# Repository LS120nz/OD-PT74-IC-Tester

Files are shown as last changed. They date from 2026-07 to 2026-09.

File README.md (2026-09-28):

# OD-PT74

Pico 74xx Logic IC Tester

OD-PT74 is the first bench instrument in the Otter Designs Test Equipment family.








## PCB Manufacturing

Production-ready PCBs are available from the PCBWay Shared Project.

➡️ https://www.pcbway.com/project/shareproject/OD_PT74_Logic_IC_Tester_728014b9.html

An open-source bench instrument for testing classic 74xx-series logic ICs.

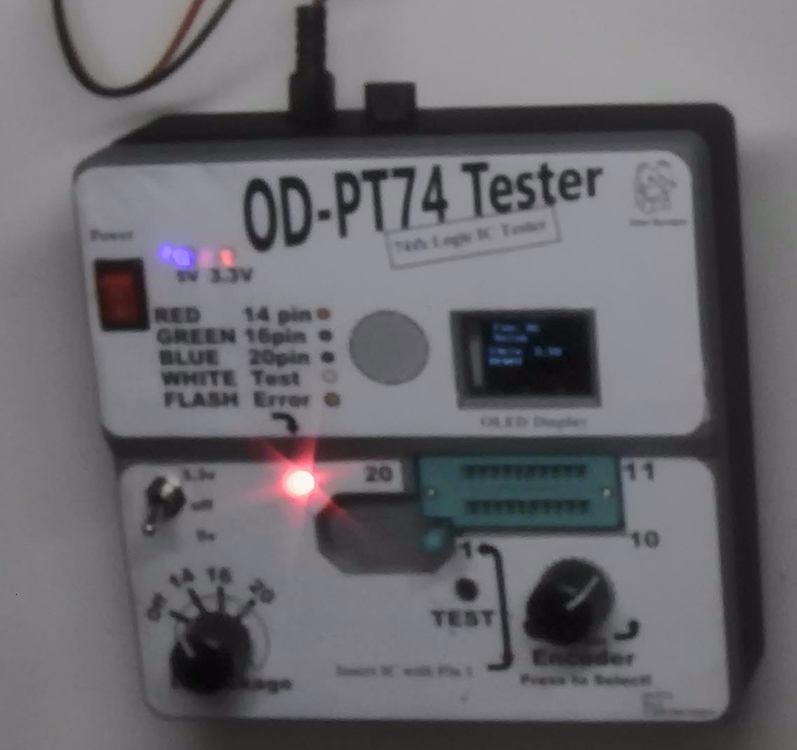
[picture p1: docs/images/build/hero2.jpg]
OD-PT74 Tester


*OD-PT74 Pico 74xx IC Tester installed in the production enclosure.*



---

## Overview

The OD-PT74 Pico 74xx IC Tester is a Raspberry Pi Pico 2 (RP2040) based instrument designed to test common 74xx logic ICs used in retro-computing, electronics repair, education, and hobby projects.

The Rev-C platform combines dedicated hardware, a graphical OLED user interface, and modular MicroPython firmware to provide fast, repeatable testing of common logic devices in a compact desktop instrument.

Current support focuses on standard 14-pin, 16-pin, and 20-pin DIP devices from the 74LS, 74HC, 74HCT and selected compatible logic families.

## 🚀 Quick Start

1. Download or clone this repository.
2. Install **Thonny** from https://thonny.org
3. Install **MicroPython** onto your Raspberry Pi Pico.
4. Copy the following files to the Pico:
   - `main.py`
   - `ssd1306.py`
5. Power up the tester.
6. Verify the POST completes successfully.
7. Start testing ICs!

For detailed installation instructions, see the **Documentation Index** or jump directly to one of the guides below.

---

## Documentation

| Section | Description |
|---|---|
| [📖 Documentation Index](docs/README.md) | Browse all project documentation |
| [🚀 Getting Started](docs/guides/getting-started.md) | First-time setup |
| [🔧 Build Guide](docs/guides/build-guide.md) | Hardware assembly |
| [🔧 Front Panel Wiring Guide](docs/guides/Switch-Wiring-guide.md)
| [💾 Firmware Guide](docs/guides/firmware-guide.md) | Install and update the firmware |
| [▶️ Usage Guide](docs/guides/usage-guide.md) | Operating the tester |
| [🧩 Supported ICs](docs/guides/supported-ics.md) | Supported logic device library |
| [🛠 Troubleshooting Guide](docs/guides/troubleshooting-guide.md) | Diagnose common issues |

---

## Key Features

* Raspberry Pi Pico 2 (RP2040) based design
* Supports standard 14-, 16- and 20-pin DIP packages
* Compatible with common 74LS, 74HC and 74HCT logic families
* Automatic package detection
* Quick, Full and Soak test modes
* Power-On Self Test (POST)
* 128×64 OLED graphical interface
* Rotary encoder driven menu system
* USB serial diagnostics
* Open-source hardware and firmware

---

## Gallery

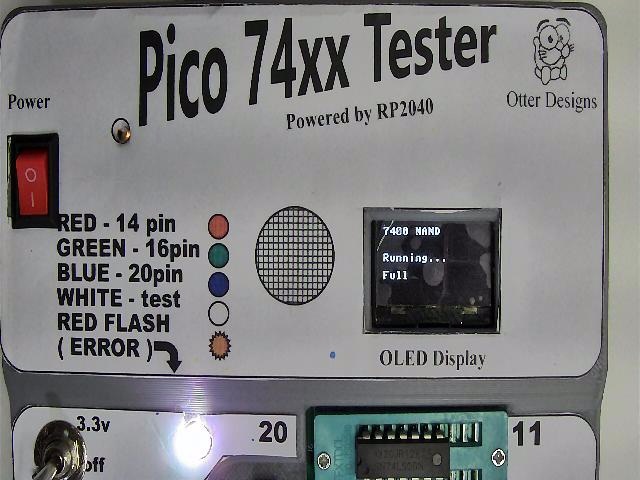
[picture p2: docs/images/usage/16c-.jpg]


*Figure 1. Full functional test in progress.*

* 
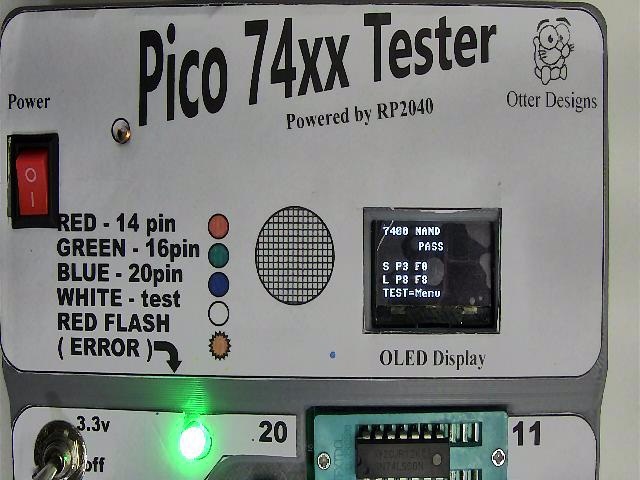
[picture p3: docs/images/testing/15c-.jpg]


*Figure 2. OLED displaying a successful PASS result.*

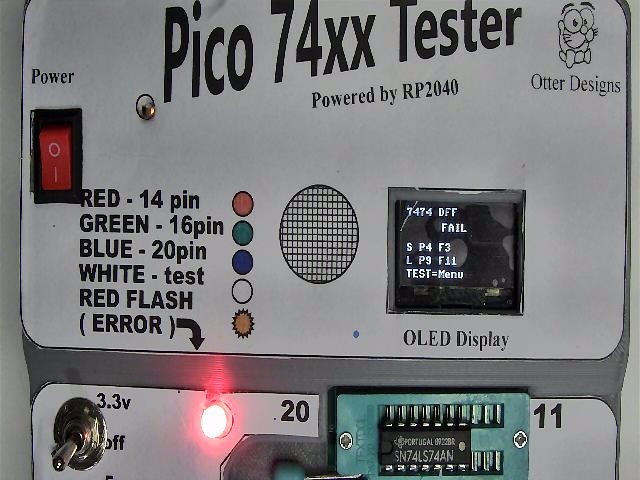
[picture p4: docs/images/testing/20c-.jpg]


*Figure 3. OLED displaying a FAIL result.*

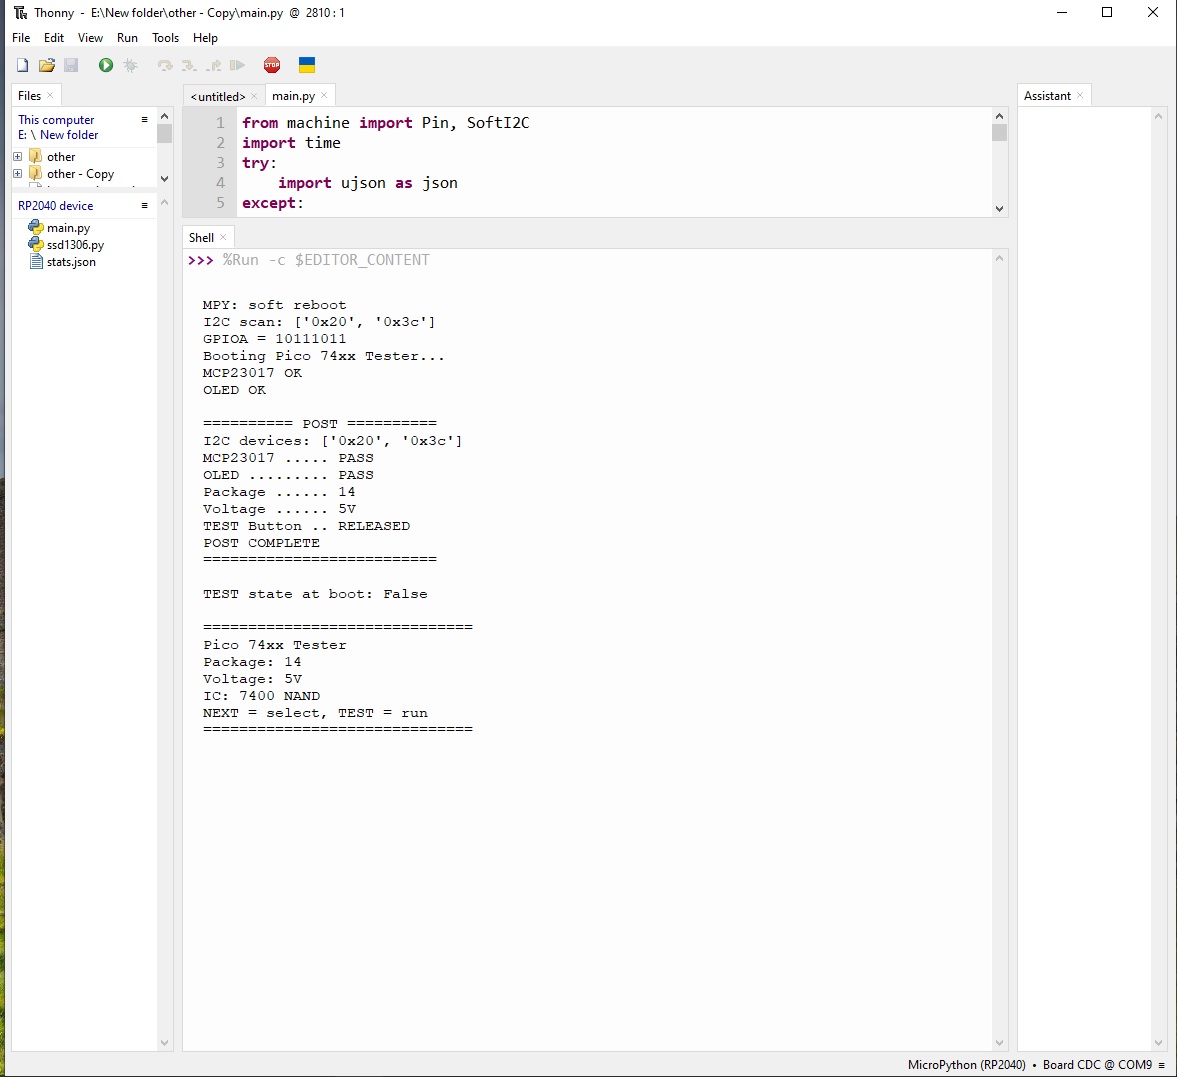
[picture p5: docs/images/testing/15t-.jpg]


*Figure 4. USB serial diagnostic output in Thonny.*

## Hardware Summary

| Feature | Specification |
| --- | --- |
| MCU | Raspberry Pi Pico 2 (RP2040) |
| Display | 128 × 64 SSD1306 OLED |
| DUT Packages | 14, 16 and 20-pin DIP |
| DUT Supply | 3.3 V / OFF / 5 V |
| Interface | Rotary encoder + push buttons |
| Firmware | MicroPython |
| License | MIT (firmware), CERN-OHL-S v2 (hardware) |

---

## Current Release

Hardware PCB Revision: Rev-C
Firmware Version: v1.0.0

This is the first public release of the OD-PT74.

Earlier PCB revisions (Rev-A and Rev-B) were internal development prototypes and were never publicly released.

The project is now focused on:

* expanding the verified IC library
* firmware maintenance and refinement
* documentation improvements
* community contributions

Advanced diagnostic capabilities are planned for the separate Logic IC Diagnostic Analyzer project.

---

## Hardware

Designed for through-hole construction using readily available components with a few SMDs.

Rev-C introduces a production-quality hardware platform featuring:

* Raspberry Pi Pico 2 controller
* 20-pin ZIF socket
* 3.3 V / OFF / 5 V DUT power selection
* Package selection for 14-, 16- and 20-pin devices
* MCP23017 I/O expansion
* SSD1306 OLED display
* Rotary encoder navigation
* TEST and NEXT push buttons
* RGB status LED
* Audible buzzer
* Shared I²C bus architecture
* 5 V power indicator LED
* 3.3 V power indicator LED

GPIO protection is provided through series resistors and clamp diodes to improve robustness during normal operation.

---

## Firmware

The firmware uses a modular architecture that separates hardware drivers, IC definitions, and user interface logic for ease of maintenance and future expansion.

Implemented functionality includes:

* Power-On Self Test (POST)
* OLED diagnostics
* I²C bus diagnostics
* MCP23017 detection
* Package detection
* DUT voltage detection
* Menu-driven user interface
* Serial diagnostic output
* Quick Test mode
* Full Functional Test mode
* Soak testing (50, 500 and Continuous)

---

## Test Modes

| Mode | Description |
| --- | --- |
| Quick | Fast functional verification |
| Full | Complete functional testing |
| Soak 50 | 50 consecutive test cycles |
| Soak 500 | 500 consecutive test cycles |
| Continuous | Unlimited endurance testing |
| POST | Automatic hardware self-test during power-up |

During startup the tester automatically verifies:

* OLED communication
* MCP23017 communication
* I²C bus operation
* Package selection
* DUT voltage selection
* TEST button operation

Diagnostic information is displayed on both the OLED and the USB serial console.

---

## Getting Started

1. Assemble the hardware.
2. Install MicroPython on the Raspberry Pi Pico 2.
3. Copy the firmware to the Pico.
4. Power on the tester.
5. Allow the Power-On Self Test to complete.
6. Select the package size.
7. Insert the IC into the ZIF socket.
8. Press **TEST**.

---

## Project Evolution

| Revision | Description |
| --- | --- |
| Rev-C | First public production release of the OD-PT74 |

Earlier prototype revisions were used during development and are documented in the project history.

---

## Repository Layout

```text
hardware/
firmware/
graphics/
images/
templates/

docs/
├── README.md
├── guides/
├── reference/
├── development/
├── archive/
└── images/

README.md
CHANGELOG.md
CONTRIBUTING.md
LICENSE
```

---

## Contributing

Contributions are welcome, particularly:

* verified IC definitions
* bug reports
* documentation improvements
* hardware testing
* firmware enhancements

When submitting a new IC definition, please include:

* source code
* pin mapping
* tested device family
* hardware validation results
* Quick, Full and Soak test results where applicable

---

## License

Hardware is licensed under the **CERN-OHL-S v2**.

Firmware and documentation are licensed under the **MIT License**.

See the LICENSE file for details.

---

## Acknowledgements

Developed by **Otter Designs**, New Zealand.

If you build an OD-PT74, we'd love to see it! Share your photos, improvements, verified IC definitions, or project ideas by opening an issue or discussion on GitHub.

---

## Project Reference

| Document | Description |
|---|---|
| [📐 Project Overview](docs/reference/project-overview.md) | Project goals and architecture |
| [📘 Hardware Design Guide](docs/reference/hardware-design-guide.md) | Hardware architecture and design |
| [📝 Documentation Style Guide](docs/reference/documentation-style-guide.md) | Documentation standards |

## Development

| Document | Description |
|---|---|
| [📅 Milestones](docs/development/Milestones.md) | Project progress and milestones |

## Project Preservation

Where practical, the OD-PT74 repository includes the original source files used to create the project.

Examples include:

- KiCad PCB source
- FreeCAD enclosure source
- SVG diagrams
- Firmware source code
- Documentation source

This approach helps ensure the project remains buildable, maintainable and adaptable for many years to come.

| [✅ Bring-up Checklist](docs/development/bringup-checklist.md) | Hardware verification checklist |

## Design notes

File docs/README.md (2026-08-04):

# Documentation

*Welcome to the OD-PT74 Pico 74xx IC Tester documentation.*

New to the project? Start with the Getting Started Guide, then continue with the Build Guide and Firmware Guide.

## User Guides

1. **[Getting Started](guides/getting-started.md)** – First-time setup and initial power-on.
2. **[Build Guide](guides/build-guide.md)** – Complete hardware assembly instructions.
3. **[Front Panel Wiring Guide](guides/Switch-Wiring-guide.md)** - Wire up Switches.
4. **[Firmware Guide](guides/firmware-guide.md)** – Installing MicroPython and the OD-PT74 firmware.
5. **[Usage Guide](guides/usage-guide.md)** – Operating the tester and interpreting results.
6. **[Supported ICs](guides/supported-ics.md)** – Validated devices and support status.
7. **[Troubleshooting Guide](guides/troubleshooting-guide.md)** – Diagnosing common problems.

## Reference

- **[Project Overview](reference/project-overview.md)** – High-level overview of the OD-PT74 project.
- **[Hardware Design Guide](reference/hardware-design-guide.md)** – Hardware architecture and design philosophy.
- **[Documentation Style Guide](reference/documentation-style-guide.md)** – Documentation standards used throughout the repository.

## Development

- **[Project Milestones](development/milestones.md)** – Major project achievements and release history.
- **[Bring-up Checklist](development/bringup-checklist.md)** – Hardware validation checklist for assembled boards.

## Archive

Historical documentation for Rev-A and early Rev-B development.

---

## Documentation Navigation

| Document | Description |
|---|---|
| [🏠 Project Home](../README.md) | Return to the project homepage |

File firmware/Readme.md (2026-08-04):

\# Firmware

This directory contains the firmware for the \*\*OD-PT74 Pico 74xx Logic IC Tester\*\*.

\## Current Release

\- Hardware: Rev-C

\- Firmware: v1.0.0

\## Files

| File | Description |

|------|-------------|

| `main.py` | Main application firmware |

| `ssd1306.py` | SSD1306 OLED display driver |

| `stats.json` | Automatically created after testing ICs (do not copy manually) |

\## Installation

1\. Install the supported version of MicroPython onto the Raspberry Pi Pico.

2\. Copy `main.py` and `ssd1306.py` to the Pico.

3\. Reset the Pico.

4\. The OD-PT74 will boot automatically.

For detailed installation instructions, see the \*\*Firmware Guide\*\*.

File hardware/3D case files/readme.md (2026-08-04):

# OD-PT74 3D Printed Case

This directory contains the 3D printable enclosure for the **OD-PT74 Rev-C**.

## Design

- Designed using **FreeCAD**
- Tested on a **Creality K1**
- Optimised for **PLA+**

## Included Files

| File Type | Description |
|---|---|
| **FCStd** | Original FreeCAD source files |
| **3MF** | Print projects with print settings |
| **STL** | Standard files ready for slicing and printing |

## Project Preservation

The original FreeCAD source files are included so the enclosure can be modified, repaired or adapted for future revisions of the OD-PT74.

This follows the project's preservation philosophy of including original design files wherever practical.

## CAD Software

The enclosure was designed using **FreeCAD 0.21**.

The supplied `.FCStd` files can be opened with newer versions of FreeCAD, although the user interface and available tools may differ.

## Source Files

The FreeCAD (`.FCStd`) files are provided so the enclosure can be modified or adapted for future revisions.

The STL files are ready for 3D printing.

The 3MF files are provided for users who wish to use the recommended print settings.

> [!NOTE]
> The 3MF files contain the slicer settings used to print the enclosure shown throughout this documentation. Users of other printers or slicers can use the STL files together with their own preferred print settings.

### Recommended Print Settings

The supplied 3MF files have been prepared for:

- **Printer:** Creality K1
- **Nozzle:** 0.4 mm
- **Material:** PLA filament

These settings are provided as a starting point and may be adjusted to suit your own printer and preferred material.

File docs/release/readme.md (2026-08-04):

# Release Assets

This folder contains the assets used to publish the OD-PT74 Logic IC Tester.

Contents include:

- GitHub release notes
- PCBWay Shared Project description
- Release images
- QR code artwork

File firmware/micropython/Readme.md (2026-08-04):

# Firmware

This directory contains the firmware for the **OD-PT74 Pico 74xx Logic IC Tester**.

## Supported Hardware

- Hardware Revision: Rev-C
- Firmware Version: v1.0.0

## Files

| File | Description |
|---|---|
| `main.py` | Main OD-PT74 application firmware |
| `ssd1306.py` | SSD1306 OLED display driver |

## Installation

1. Install MicroPython on the Raspberry Pi Pico.
2. Copy `main.py` to the Pico.
3. Copy `ssd1306.py` to the Pico.
4. Reboot the Pico.

The firmware will start automatically.

## Notes

This firmware is intended for the Rev-C OD-PT74 hardware.

*Copyright © 2026 Otter Designs*

OD-PT74 Firmware v1.0.0

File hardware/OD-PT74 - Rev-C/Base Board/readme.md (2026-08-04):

# OD-PT74 Rev-C Base Board

This directory contains all design, manufacturing and reference files for the **OD-PT74 Rev-C Base Board**.

## Contents

### BOM

Contains the Bill of Materials in both human-readable Markdown and KiCad-generated CSV formats.

### KiCad

Contains the complete KiCad source project, including the schematic, PCB layout and associated project files.

### Gerbers

Contains the Gerber and drill files generated from the final Rev-C design.

### Images

Contains reference images, including the schematic, PCB layout and 3D board render.

### OD-PT74_Base.zip
A ready-to-upload archive containing all manufacturing files required for PCB fabrication.

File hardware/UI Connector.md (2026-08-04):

\# OD-PT74 UI Connector

This document defines the board-to-board connector assignments between the OD-PT74 Rev-C Main Board and Top Board.

These connector assignments are provided for hardware maintenance, future revisions and third-party expansion boards.

\## Compatible Hardware

• OD-PT74 Rev-C Main Board

• OD-PT74 Rev-C Top Board

\## J7 — ZIF Interface Bus (Pins 1–16)

Pin 1 - ZIF-1
Pin 2 - ZIF-2
Pin 3 - ZIF-3
Pin 4 - ZIF-4
Pin 5 - ZIF-5
Pin 6 - ZIF-6
Pin 7 - ZIF-7
Pin 8 - ZIF-8
Pin 9 - ZIF-9
Pin 10 - ZIF-10
Pin 11 - ZIF-11
Pin 12 - ZIF-12
Pin 13 - ZIF-13
Pin 14 - ZIF-14
Pin 15 - ZIF-15
Pin 16 - ZIF-16

\## J8 — ZIF \& User Interface Bus

Pin 1 - ZIF-17
Pin 2 - ZIF-18
Pin 3 - ZIF-19
Pin 4 - ZIF-20
Pin 5 - I2C SDA
Pin 6 - I2C SCL
Pin 7 - RGB Red
Pin 8 - RGB Green
Pin 9 - RGB Blue
Pin 10 - Test / Enter Button
Pin 11 - Active Piezo Buzzer
Pin 12 - Encoder-A
Pin 13 - Encoder-B
Pin 14 - Encoder-SW
Pin 15 - GPIO28 (Reserved / Future Use)
Pin 16 - Next / Select Button

\## J6 — Power Distribution Bus

Pin 1 - DC +3.3v
Pin 2 - DC +3.3v
Pin 3 - DC +5v
Pin 4 - DC +5v
Pin 5 - Gnd
Pin 6 - Gnd
Pin 7 - Pico +3.3v
Pin 8 - Pico +3.3v
Pin 9 - Pico +5v
Pin 10 - Pico +5v
Pin 11 - Gnd
Pin 12 - Gnd
Pin 13 - 3.3 V Output
Pin 14 - 3.3 V Output
Pin 15 - 5 V Output
Pin 16 - 5 V Output
Pin 17 - Gnd
Pin 18 - Gnd
Pin19 - N/C
Pin20 - N/C

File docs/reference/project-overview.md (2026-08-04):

# OD-PT74 Project Overview

## Introduction

The OD-PT74 Pico 74xx Logic IC Tester is an open-source bench instrument designed to verify the functionality of standard 74xx-series digital logic integrated circuits.

Built around the Raspberry Pi Pico (RP2040), the tester provides a dedicated hardware platform with modular MicroPython firmware, allowing common logic devices to be tested quickly and consistently without requiring external test equipment.

The project is intended for electronics enthusiasts, retro-computing hobbyists, educators, repair technicians, and anyone working with TTL or CMOS logic devices.

---

| Item | Value |
| --- | --- |
| Product | OD-PT74 |
| Hardware | Rev-C |
| Firmware | v1.0.0 |
| MCU | RP2040 |
| Language | MicroPython |
| Supported Packages | 14, 16 & 20-pin DIP |

---

## Project Goals

The primary objectives of the project are:

* Provide a simple, reliable tester for common 74xx logic ICs.
* Support the most widely used DIP package formats.
* Deliver consistent and repeatable functional testing.
* Present an intuitive user interface suitable for bench use.
* Maintain an open, modular architecture that is easy to extend.
* Encourage community contributions for additional IC definitions.

---

## Design Scope

The OD-PT74 Rev-C hardware is designed specifically for testing standard logic devices using conventional pin assignments.

Supported device families include:

* 74LS
* 74HC
* 74HCT
* Selected compatible 74xx logic families

Supported package sizes are:

* 14-pin DIP
* 16-pin DIP
* 20-pin DIP

The Rev-C hardware assumes conventional power pin locations used by the majority of standard 74xx devices.

Devices requiring non-standard power arrangements, external adapters, analogue measurements, or specialised timing analysis are intentionally outside the scope of this revision.

---

## Hardware Overview

The tester consists of a dedicated hardware platform featuring:

* Raspberry Pi Pico (RP2040)
* 20-pin ZIF socket
* OLED graphical display
* MCP23017 I/O expander
* Rotary encoder navigation
* TEST and NEXT push buttons
* DUT voltage selection (3.3 V / OFF / 5 V)
* RGB status LED
* Audible buzzer
* Dual 5 V / 3.3 V power indicators

The hardware has been designed for robustness, ease of assembly, and reliable bench operation.

---

## Firmware Overview

The firmware is written in MicroPython using a modular architecture.

Major software components include:

* Hardware abstraction layer
* Display driver
* Menu system
* IC definition library
* Test engine
* Self-test routines
* Diagnostic utilities

Separating IC definitions from the test engine allows new devices to be added without modifying the core firmware.

---

## Testing Philosophy

The objective of the tester is to verify the logical behaviour of supported integrated circuits rather than perform exhaustive electrical characterisation.

Available test modes include:

* Quick Test
* Full Functional Test
* Soak Test (50, 500, or Continuous cycles)

Each device is exercised using predefined test vectors appropriate to its logical function.

---

## Current Status

The OD-PT74 hardware is now based on the Rev-C production PCB and is considered feature complete.

Current development is focused on:

• Expanding the verified IC library
• Firmware enhancements
• Documentation improvements
• Community contributions

---

## Future Development

Future advanced diagnostic capabilities are being developed as part of the separate Otter Designs Advanced Diagnostics Unit (OD-ADU) project.

Planned capabilities include:

* Support for larger package formats
* Adapter-based device testing
* Non-standard power pin configurations
* Advanced timing analysis
* Oscilloscope-style diagnostic tools
* Enhanced device characterisation

These features are intentionally outside the design scope of Rev-C to keep the platform simple, reliable, and focused on testing the most commonly encountered 74xx logic devices.

---

## Repository Documentation

Additional information is available throughout the repository:

* README – project introduction and quick start
* Getting Started – assembly and first use
* Build Guide – hardware construction
* Usage Guide – operating instructions
* Supported ICs – verified device list
* Troubleshooting – common problems and solutions
* CHANGELOG – project revision history

Refer to these documents for detailed instructions and technical reference material.

---

## Related Documentation

| Document | Description |
|---|---|
| [🏠 Project Home](../../README.md) | Return to the main project page |
| [📖 Documentation Index](../README.md) | Documentation overview |
| [🔧 Build Guide](../guides/build-guide.md) | Hardware assembly |

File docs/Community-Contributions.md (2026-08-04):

## Community IC Contributions

The OD-PT74 74xx Tester was designed to allow additional IC support to be added over time.

If you develop and validate support for a new device, contributions are welcome.

### Please Include

* IC part number
* Device family (74LS, 74HC, 74HCT, etc.)
* Test function source code
* Pin mapping used
* Test methodology
* Hardware validation results
* Quick / Full / Soak test results
* Any known limitations

### Validation Requirements

Before submitting a new IC definition, please verify the device on physical hardware.

At minimum:

* Quick Test PASS
* Full Test PASS
* Soak Test PASS (recommended 50 cycles)

### Goal

The aim of the project is to build a growing library of verified logic IC tests that can be shared with the community.

Verified contributions may be incorporated into future firmware releases and credited to the contributor.

### Notes

OD-PT74 74xx Tester focuses primarily on standard 74xx-series logic devices.

More specialised devices and advanced diagnostic functions are planned for the future Logic IC Diagnostic Analyzer.

## Project Preservation

The OD-PT74 repository is intended to preserve everything required to build, modify, and maintain the project. Where practical, original source files are included alongside generated outputs to ensure the project remains usable for future builders and contributors.

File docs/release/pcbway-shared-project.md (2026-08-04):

OD-PT74 PCBWay Shared Project
Project Title

OD-PT74 Logic IC Tester

Short Description
-------------------
The OD-PT74 is an open-source RP2040-based 74xx TTL and CMOS logic IC tester designed for hobbyists, repair technicians and electronics enthusiasts. It supports 14, 16 and 20-pin DIP devices and features an intuitive OLED display with rotary encoder navigation. Complete firmware, hardware source, enclosure files and build documentation are available on GitHub.

Features
----------
Supports 14, 16 and 20-pin DIP logic ICs
Supports both TTL and CMOS logic families
RP2040 microcontroller
OLED display
Rotary encoder user interface
Quick, Full and Soak test modes
Open-source firmware
KiCad hardware source included
FreeCAD enclosure source included
Complete build documentation

GitHub Repository
----------------
GitHub Repository Contents:

Firmware source
Hardware source (KiCad)
Gerber files
BOM files
Pick & Place files
FreeCAD enclosure source
STL files
3MF files
Build Guide
Front Panel Wiring Guide
Hardware Design Guide
Troubleshooting Guide

PCBWay Files
--------------
This Shared Project provides the production-ready manufacturing files for both PCBs used by the OD-PT74:

• Base Board
• Top Board

Each board includes:
• Gerber files
• Bill of Materials (BOM)
• Pick & Place files

GitHub
--------
The complete project, including firmware, documentation, hardware source, enclosure source and future updates, is available on GitHub:

https://github.com/LS120nz/OD-PT74-IC-Tester
Please visit the GitHub repository for firmware updates, documentation and future hardware revisions.

Notes
--------
This project is fully open source.

Complete documentation, firmware updates and future revisions will always be available from the GitHub repository.

Photos to Upload
-----------------
Hero image
Assembled tester
Internal assembly
Top PCB
Base PCB

This project is released as open-source hardware. Contributions, improvements and additional device support are welcome through the GitHub repository.

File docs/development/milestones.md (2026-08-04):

# Project Milestones

## Current Release

Hardware: Rev-C
Firmware: v1.0.0
Status: Public Release

The OD-PT74 has progressed through three hardware revisions, culminating in the Rev-C production design.

### Verified Hardware

* RP2040 Pico controller
* MCP23017 I/O expander
* 20-pin ZIF socket interface
* 14-pin package support
* 16-pin package support
* 20-pin package support
* 3.3V / OFF / 5V DUT voltage selection
* Rotary encoder interface
* TEST and NEXT pushbuttons
* SSD1306 128×64 OLED display
* I²C bus shared between MCP23017 and OLED
* Fault detection and reporting
* Dual 5 V / 3.3 V power indicators

### Verified ICs

Refer to the *Supported ICs* Guide for the current list of validated devices.

### Validation Highlights

The tester has successfully identified defective ICs during validation testing, including:

* Faulty 74HC393 device detected and confirmed
* Incorrect 74163 test implementation identified during firmware validation
* Multiple pin-mapping and package-mapping issues corrected during bring-up

### Project Timeline

✅ Rev-A
Initial concept and functional prototype.

✅ Rev-B
Major redesign and feature validation.

✅ Rev-C
Production hardware.
Public GitHub release.
Documentation complete.
Firmware v1.0.0.

### Future Development

- Additional IC definitions
- Firmware enhancements
- Community contributions
- OD-ADU development

## Related Documentation

| Document | Description |
|---|---|
| [🏠 Project Home](../../README.md) | Return to the main project page |
| [📖 Documentation Index](../README.md) | Documentation overview |

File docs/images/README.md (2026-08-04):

# Images

This directory contains all images used throughout the GitHub documentation for the **OD-PT74 Pico 74xx IC Tester**.

Images are organised by document or purpose to simplify maintenance and keep the documentation consistent.

## Folder Structure

- **build/** – Hardware assembly photographs.
- **firmware/** – Thonny and firmware installation screenshots.
- **hardware/** – Product photographs and hardware overview images.
- **usage/** – Operating the tester and example test results.
- **testing/** – Test examples and validation images.
- **branding/** – Logos, labels, and other branding artwork.

When adding new images:

- Use descriptive filenames.
- Keep images grouped in the appropriate folder.
- Optimise images for GitHub viewing where practical.
- Update the relevant documentation if image filenames or locations change.

## Related Documentation

| Document | Description |
|---|---|
| [🏠 Project Home](../../README.md) | Return to the main project page |
| [📖 Documentation Index](../README.md) | Documentation overview |

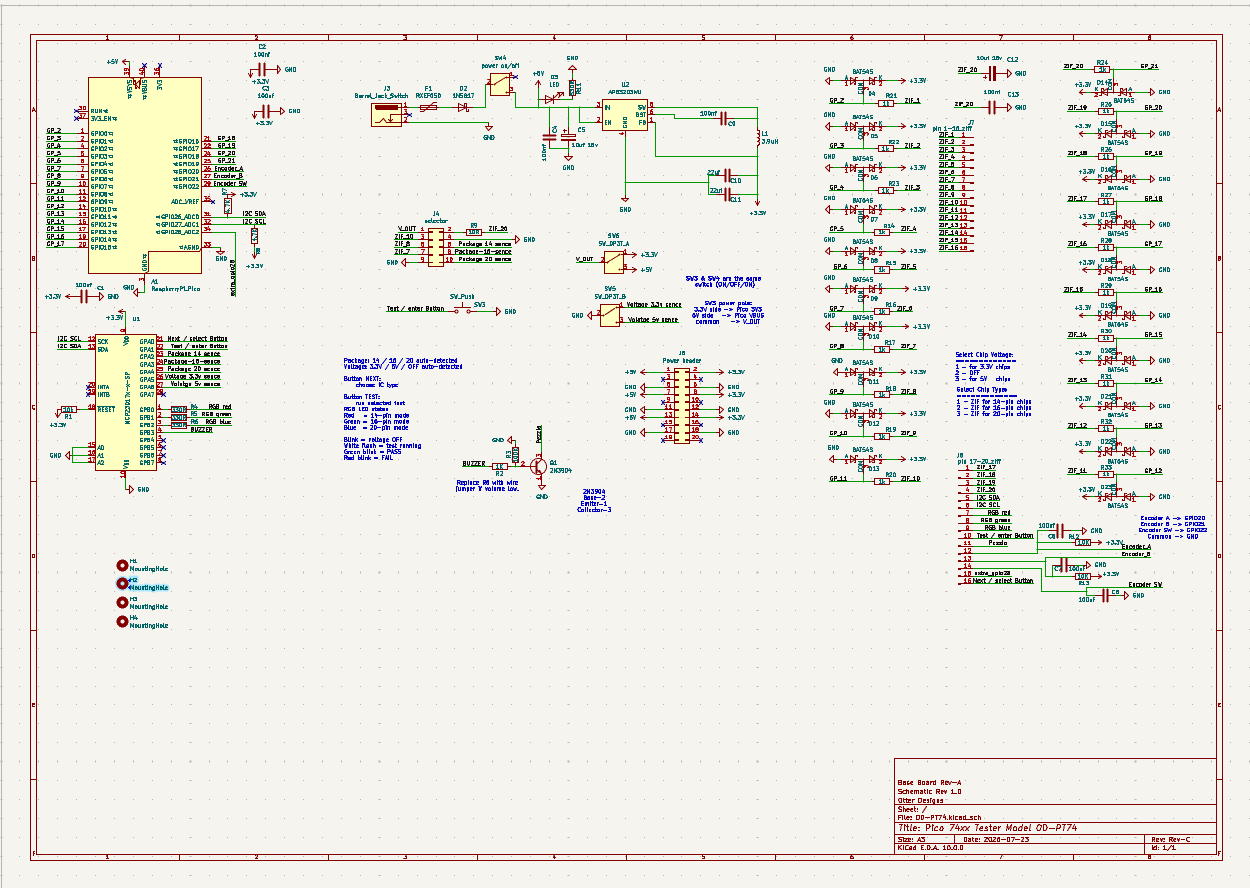
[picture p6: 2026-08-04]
hardware/OD-PT74 - Rev-C/Base Board/Images/OD-PT74_Rev-C_Base_Board-schematic.png

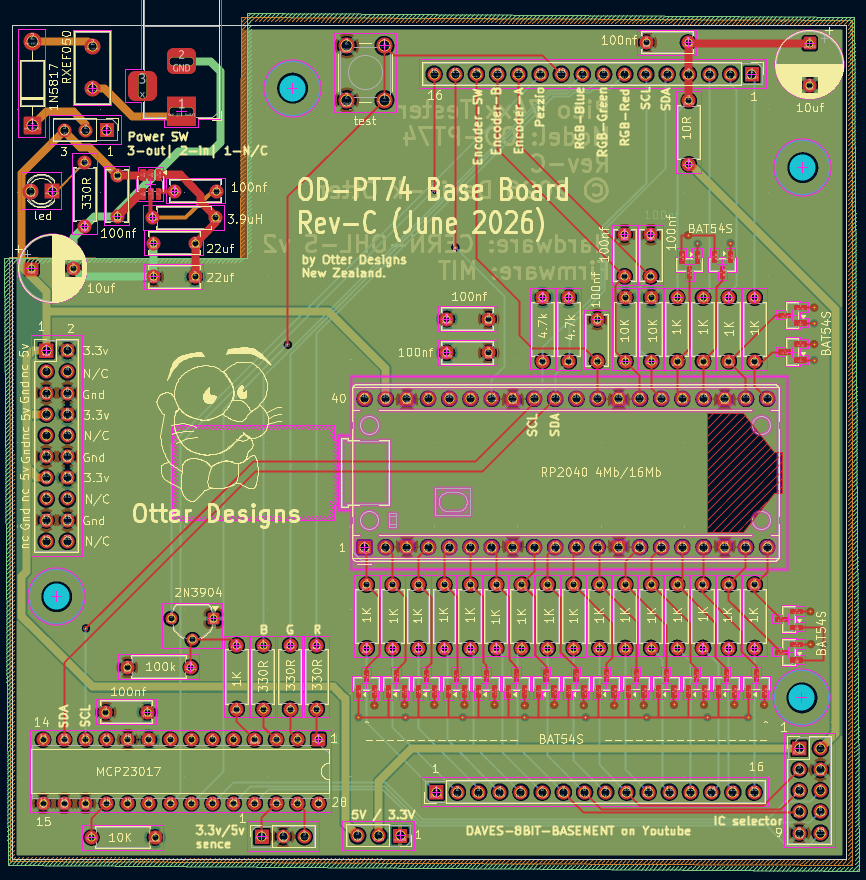
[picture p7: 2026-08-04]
hardware/OD-PT74 - Rev-C/Base Board/Images/OD-PT74_Rev-C_Base_Board-KiCad.png

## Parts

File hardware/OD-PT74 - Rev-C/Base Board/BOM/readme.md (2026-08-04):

# Bill of Materials

This directory contains the manufacturing and assembly files for the **OD-PT74 Rev-C**.

## Files

| File | Purpose |
|---|---|
| `OD-PT74_BOM.md` | Human-readable parts list |
| `OD-PT74.csv` | KiCad Bill of Materials export |
| `OD-PT74_all.pos` | Pick-and-Place data for PCB assembly |

The CSV files were generated from the final Rev-C KiCad project.

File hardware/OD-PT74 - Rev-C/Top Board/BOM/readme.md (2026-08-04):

# Bill of Materials

This directory contains the manufacturing and assembly files for the **OD-PT74 Rev-C**.

## Files

| File | Purpose |
|---|---|
| `top_board_BOM.md` | Human-readable parts list |
| `top_board.csv` | KiCad Bill of Materials export |
| `top_board_all.pos` | Pick-and-Place data for PCB assembly |

The CSV files were generated from the final Rev-C KiCad project.

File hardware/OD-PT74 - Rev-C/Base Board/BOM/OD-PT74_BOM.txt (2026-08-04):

Main Board B.O.M Rev-B
------------------
1 x Raspberry-Pi Pico 2040 4Mb+ (A1)
9 x 100nf Disc cap (C1, C2, C3, C4, C6, C7, C8, C9, C13)
2 X 10UF 16V Elec Cap (C5, C12)
2 x 22uf Poly/Disc (C10, C11)
1 x 1N5817 Shockey Diode (D2)
1 x 3mm Led power led (D3)
20 x BAT54S diode (D4 - D23)
1 x RXEF050 resettable fuse (F1)
1 x Barrel Jack (J3)
1 x Selector 3-Pole x 4-Contact (connects to J4)
1 x 2x5 p2.54 Vertical header (J4) (selector header)
1 x 2x10 p2.54 Vertical Socket (J6) (top board Power)
2 x 1x16 p5.54 Vertical Socket (J7,J8) (GPIO headers)
1 x 3.9uH coil (L1)
1 x 2N3904 (Q1)
3 x 10K (R1,R12,R13)
1 x 100K (R3)
4 x 330R (R4,R5,R6,R11)
2 x 4.7K (R7,R8)
1 x 10R (R9)
21 x 1K (R2, R14-R33)
1 x push switch 6x6mm (SW3)
1 x SPST power on/of mains switch (SW7 not in circuit)
1 x DPxTT 3v/5v ic test & scene (for SW5 and SW6) (On/Off/On)
1 x MCP23017 (U1)
1 x AP63203WU (U2)
1 x Dip20 socket
2 x 1x3 2.54 Vertical Header (SW3, SW5, SW6)

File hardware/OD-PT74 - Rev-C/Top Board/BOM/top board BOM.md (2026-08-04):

# OD-PT74 Rev-C Top Board

*Bill of Materials*
-------------------------

1 × Active Piezo Buzzer (BZ1)

2 × 3 mm Power LEDs (D1, D3)
    - Red
    - Green

1 × RGB LED (D2)

1 × Power Switch, ON/OFF/ON (J1)

1 × 128×64 OLED Display Header (J2)

1 × 2×10 Board Connector (J3)

2 × 1×16 Headers (J4, J5)

1 × 20-pin ZIF Socket

1 × 1 kΩ Resistor (R1)

1 × 330 Ω Resistor (R2)

1 × 6×6 mm Tactile Push Button (SW1)

1 × EC11E Vertical Low-Profile Rotary Encoder (SW2)

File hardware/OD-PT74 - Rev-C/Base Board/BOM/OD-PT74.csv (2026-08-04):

Id | Designator | Footprint | Quantity | Designation | Supplier and ref
1 | A1 | RaspberryPi_Pico_Common_THT | 1 | RaspberryPi_Pico
2 | C1, C2, C3, C4, C6, C7, C8, C9, C13 | C_Disc_D6.0mm_W2.5mm_P5.00mm | 9 | 100nf
3 | C5, C12 | CP_Radial_D8.0mm_P5.00mm | 2 | 10uf 16v
4 | C10, C11 | C_Disc_D6.0mm_W2.5mm_P5.00mm | 2 | 22uf
5 | D2 | D_DO-41_SOD81_P10.16mm_Horizontal | 1 | 1N5817
6 | D3 | LED_D3.0mm_Clear | 1 | LED
7 | D4, D5, D6, D7, D8, D9, D10, D11, D12, D13, D14, D15, D16, D17, D18, D19, D20, D21, D22, D23 | SOT-23 | 20 | BAT54S
8 | F1 | Fuse_Littelfuse_395Series | 1 | RXEF050
9 | J3 | BarrelJack_Horizontal | 1 | Barrel_Jack_Switch
10 | J4 | PinHeader_2x05_P2.54mm_Vertical | 1 | selector
11 | J6 | PinHeader_2x10_P2.54mm_Vertical | 1 | Power header
12 | J7 | PinHeader_1x16_P2.54mm_Vertical | 1 | pin 1-16_ziff
13 | J8 | PinHeader_1x16_P2.54mm_Vertical | 1 | pin 17-20_ziff
14 | L1 | R_Axial_DIN0207_L6.3mm_D2.5mm_P7.62mm_Horizontal | 1 | 3.9uH
15 | Q1 | TO-92L_Wide | 1 | 2N3904
16 | R1 | R_Axial_DIN0207_L6.3mm_D2.5mm_P7.62mm_Horizontal | 1 | 10k
17 | R2 | R_Axial_DIN0207_L6.3mm_D2.5mm_P7.62mm_Horizontal | 1 | 1K
18 | R3 | R_Axial_DIN0207_L6.3mm_D2.5mm_P7.62mm_Horizontal | 1 | 100K
19 | R4, R5, R6, R11 | R_Axial_DIN0207_L6.3mm_D2.5mm_P7.62mm_Horizontal | 4 | 330R
20 | R7, R8 | R_Axial_DIN0207_L6.3mm_D2.5mm_P7.62mm_Horizontal | 2 | 4.7K
21 | R9 | R_Axial_DIN0207_L6.3mm_D2.5mm_P7.62mm_Horizontal | 1 | 10R
22 | R12, R13 | R_Axial_DIN0207_L6.3mm_D2.5mm_P7.62mm_Horizontal | 2 | 10K
23 | R14, R15, R16, R17, R18, R19, R20, R21, R22, R23, R24, R25, R26, R27, R28, R29, R30, R31, R32, R33 | R_Axial_DIN0207_L6.3mm_D2.5mm_P7.62mm_Horizontal | 20 | 1k
24 | SW3 | SW_PUSH_6mm_H7.3mm | 1 | SW_Push
25 | SW4 | PinHeader_1x03_P2.54mm_Vertical | 1 | power on/off
26 | SW5 | PinSocket_1x03_P2.54mm_Vertical | 1 | SW_DP3T_B
27 | SW6 | PinSocket_1x03_P2.54mm_Vertical | 1 | SW_DP3T_A
28 | U1 | DIP-28_W7.62mm | 1 | MCP23017x-x-SP
29 | U2 | TSOT-23-6 | 1 | AP63203WU

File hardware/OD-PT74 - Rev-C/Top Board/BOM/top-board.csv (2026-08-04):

Id | Designator | Footprint | Quantity | Designation | Supplier and ref
1 | BZ1 | Buzzer_15x7.5RM7.6 | 1 | Active Piezo Buzzer
2 | D1, D3 | LED_D3.0mm | 2 | LED
3 | D2 | LED_D5.0mm-4_RGB_Staggered_Pins | 1 | LED_BRKG
4 | J2 | OLED_128x64 | 1 | OLED_128x64
5 | J3 | PinHeader_2x10_P2.54mm_Vertical | 1 | Power header
6 | J4 | PinHeader_1x16_P2.54mm_Vertical | 1 | pin 1-16_ziff
7 | J5 | PinHeader_1x16_P2.54mm_Vertical | 1 | pin 17-20_ziff
8 | J6 | DIP_Socket-20_W4.3mm_W5.08mm_W7.62mm_W10.16mm_W10.9mm_3M_220-3342-00-0602J | 1 | Ziff
9 | J7 | PinHeader_1x03_P2.54mm_Horizontal | 1 | buzzer power
10 | J8 | PinHeader_1x03_P2.54mm_Vertical | 1 | RGB-header1
11 | J9 | PinHeader_1x03_P2.54mm_Vertical | 1 | RGB-header2
12 | R1 | R_Axial_DIN0207_L6.3mm_D2.5mm_P7.62mm_Horizontal | 1 | 1k
13 | R2 | R_Axial_DIN0207_L6.3mm_D2.5mm_P7.62mm_Horizontal | 1 | 330R
14 | SW1 | SW_PUSH_6mm | 1 | Test
15 | SW2 | RotaryEncoder_Alps_EC11E-Switch_Vertical_H20mm | 1 | RotaryEncoder_Switch_MP

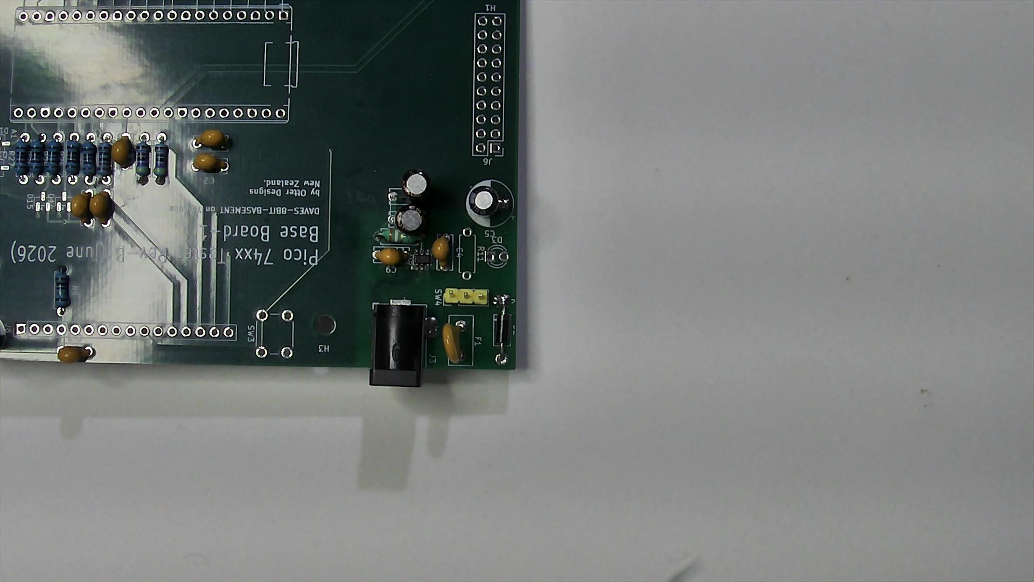
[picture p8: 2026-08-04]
docs/images/build/02-5v-power-components.jpg

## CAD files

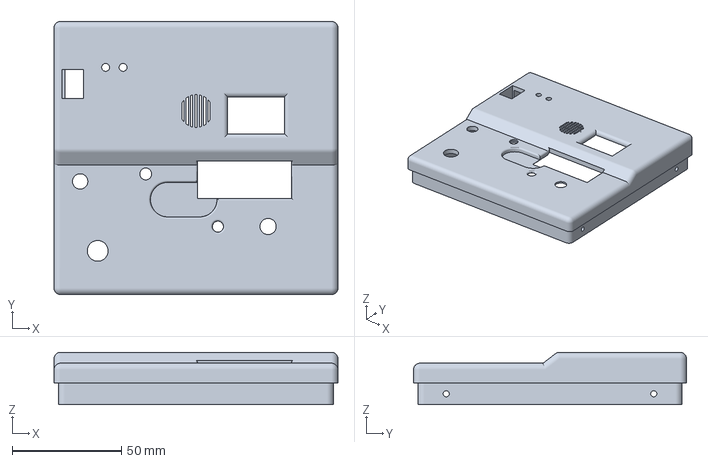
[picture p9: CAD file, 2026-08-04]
hardware/3D case files/3mf/OD-PT74-top-Body.3mf
130.0 x 125.0 x 24.0 mm

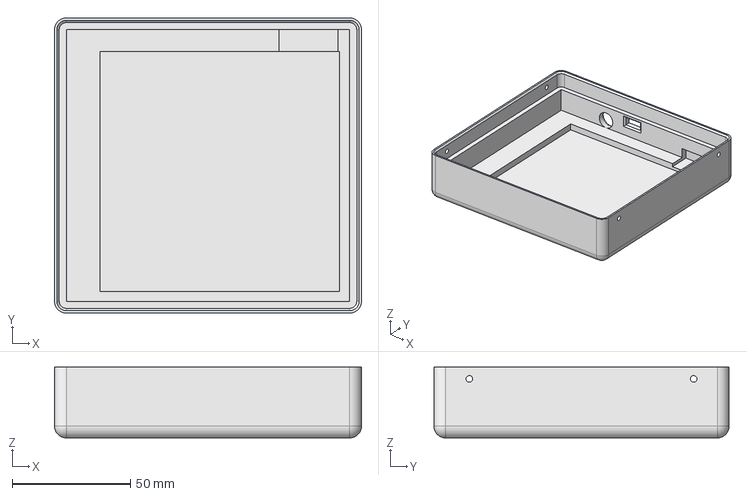
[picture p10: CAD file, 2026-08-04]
hardware/3D case files/freecad/OD-PT74-base.FCStd
130.0 x 125.0 x 30.0 mm

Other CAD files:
hardware/3D case files/freecad/OD-PT74-top.FCStd
hardware/3D case files/3mf/OD-PT74-base.3mf
hardware/3D case files/stl/OD-PT74-base.stl
hardware/3D case files/stl/OD-PT74-top-Body.stl

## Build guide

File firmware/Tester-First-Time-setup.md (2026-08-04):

# Installing MicroPython and the OD-PT74 Pico 74xx Logic IC Tester Firmware

If this is your first time using a Raspberry Pi Pico, don't worry—this guide walks you through every step.
Difficulty: Beginner
Estimated time: 10–15 minutes

This guide was validated using MicroPython v1.28.0 and Thonny 4.x. Newer versions should also work, but the screenshots may differ slightly.

## OD-PT74 First-Time Setup

## Requirements

You'll need:
- Raspberry Pi Pico or Pico W
- USB cable
- Windows / Linux / macOS
- Internet connection

## Step 1 - Install Thonny
➡️ **Download Thonny**
https://thonny.org
Download and install Thonny from the official website before continuing with this guide.
- Install and Start Thonny.

## Step 2 - Install MicroPython

- Hold BOOTSEL.
- Plug the Pico into USB.
- Release BOOTSEL.
- A new drive appears.
* In Thonny:
	Run
	   Select Interpreter
		Raspberry Pi Pico
		     Install MicroPython

## Step 3 - Download the Project

Clone the GitHub repository or download the ZIP archive, then open the firmware folder.

## Step 4 - Copy the Firmware

Copy the following file to the Raspberry Pi Pico:

- main.py

(Save the files to the Raspberry Pi Pico in Thonny, not to "This Computer".)

Saving main.py causes the Pico to restart automatically. This is normal.

Installing main.py

*Figure 1. Saving main.py to RP2040.*

## Step 5 - Install Required Libraries

Make sure you Copy this file to the Pico:

ssd1306.py

ssd1306.py is the display driver used by the tester. 

MicroPython does not include this library by default, 

ssd1306.py is included in the project's firmware folder and it must be copied to the Pico before the OLED will work.

(Save the files to the Raspberry Pi Pico in Thonny, not to "This Computer".)

Installing ssd1306.py

*Figure 2. Saving ssd1306.py to RP2040.*

## Step 6 - Verify the Files

The Pico should contain:

| File | Purpose |
| --- | --- |
| `main.py` | Main OD-PT74 firmware |
| `ssd1306.py` | OLED display driver |

verify files

*Figure 3. files installed on PR2040.*

## Step 7 - Reset the Pico

Press Reset or unplug/replug USB.

Expected terminal output:

Booting OD-PT74...
POST...
MCP23017 PASS
OLED PASS
...
If the terminal window is not visible in Thonny, open View → Shell to see the POST messages.

verify files

*Figure 4. the boot screen from Thonny.*

## Step 8 - First Boot

When the Pico restarts you should see:

==============================
OD-PT74
Pico 74xx Logic IC Tester
Firmware v1.0.0
==============================
POST...
MCP23017 PASS
OLED PASS

If you see this, your firmware has been installed successfully.

Congratulations!

Your OD-PT74 Pico 74xx Logic IC Tester firmware is now installed.

Continue with the Bring-Up Guide to verify the hardware.

## Next Step;

Continue with the **[Bring-up Checklist](...)**

## Common Mistakes & Troubleshooting

OLED not detected ?

Before checking the wiring:

• Forgot to copy ssd1306.py to the Pico.
• Saved main.py onto the PC instead of the Pico.
• Selected the wrong interpreter in Thonny.
• OLED connected to the wrong I²C address (0x3C/0x3D).
• USB cable is charge-only and cannot transfer data.
• Does i2c.scan() show the OLED?
• Forgot to install MicroPython before copying main.py.

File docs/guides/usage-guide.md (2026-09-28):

# Usage Guide

This guide explains how to use the OD-PT74 74xx Logic IC Tester to identify and test supported logic ICs.

---

## Before You Begin

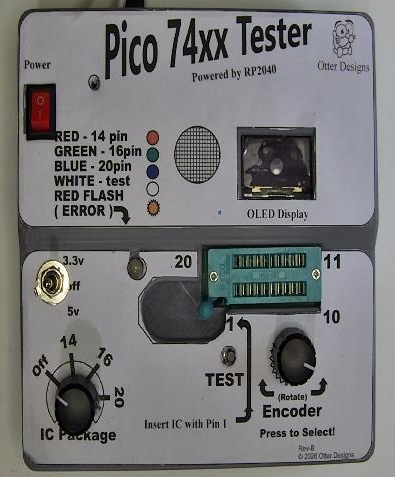
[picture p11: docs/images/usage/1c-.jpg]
Tester turned off


Figure 1 – tester turned off.

Before testing an IC ensure that:

- The firmware has been installed.
- The tester powers on correctly.
- The OLED display is operating.
- The ZIF socket is empty.
- The POST completes without errors.

Always set the IC Voltage Selector to OFF before inserting or removing an IC.
---

## Powering On

Connect the 5 V power supply.

After a few seconds the startup screen is displayed.

---

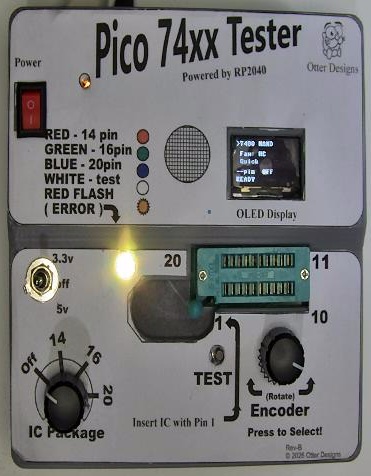
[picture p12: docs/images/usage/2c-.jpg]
Powered on, IC voltage OFF


Figure 2 - powered on, IC voltage off.

---

## Controls

The tester is operated using three controls.

### Voltage Selector

Selects the operating voltage.

---

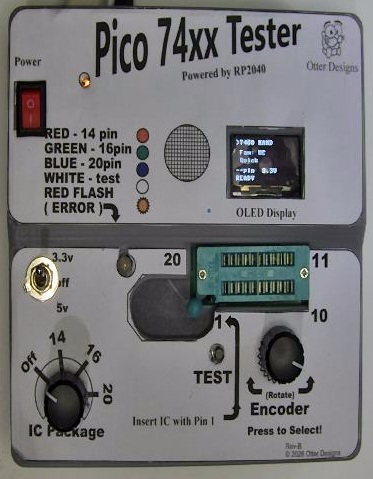
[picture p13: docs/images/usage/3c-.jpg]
3.3v Voltage Selector


Figure 3 - 3.3v voltage selected.

---

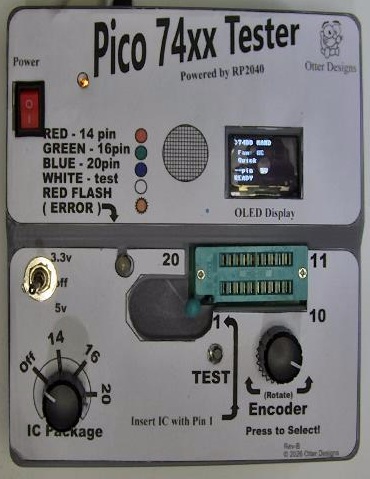
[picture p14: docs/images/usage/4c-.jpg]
5v Voltage Selector


Figure 4 - 5v voltage selected.

---

Always use the correct voltage for the device being tested.
Select 3.3 V for 74LVC, 74HC and other 3.3 V devices (as appropriate for your supported families).
Select 5 V for standard 5 V logic devices.
Never change the voltage while a test is running.

---

## Selecting an IC Package

---

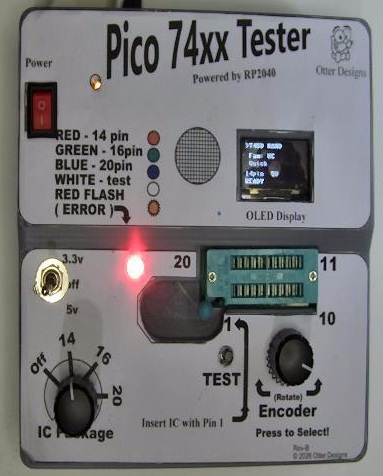
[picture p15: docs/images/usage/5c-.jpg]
Select 14 Pin IC


Figure 5 - selected 14 Pin IC

---

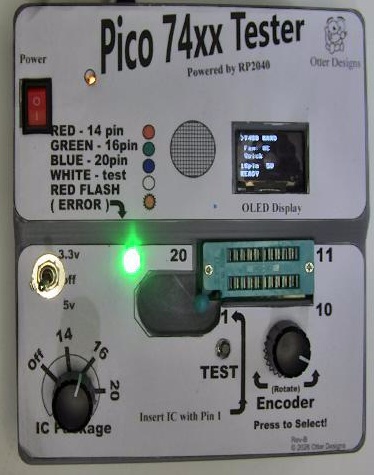
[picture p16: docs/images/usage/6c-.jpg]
Select 16 Pin IC


Figure 6 - selected 16 Pin IC

---

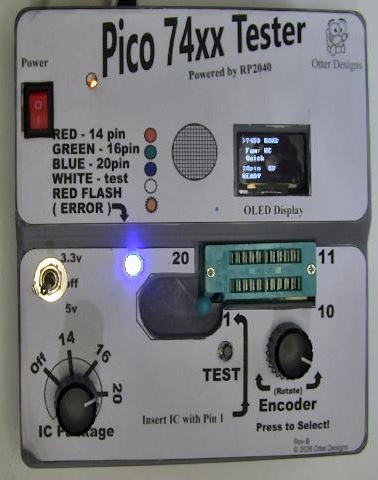
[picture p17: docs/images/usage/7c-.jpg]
Select 20 Pin IC


Figure 7 - selected 20 Pin IC

---

Before inserting an IC, ensure the IC Voltage Selector is set to OFF.

Select the package size that matches the IC being tested:

• 14-pin
• 16-pin
• 20-pin

---

## Installing an IC

Raise the ZIF socket lever.

Insert the IC with Pin 1 aligned with the Pin 1 marking.

Close the lever firmly.

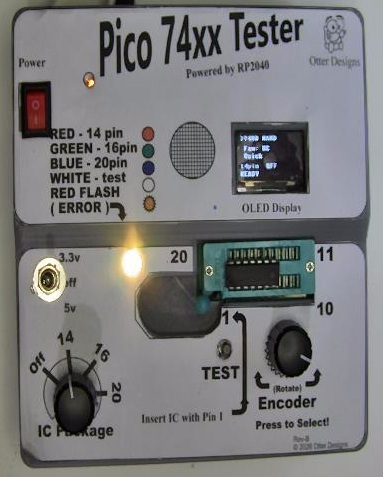
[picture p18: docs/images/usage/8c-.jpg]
Insert IC


Figure 8 - installing an IC.

After the IC has been installed and the ZIF socket is closed, select the correct supply voltage.

Typical examples are:

• 74HC and 74LVC devices — 3.3 V
• Standard 74xx, 74L and 74LS devices — 5 V

Always verify the correct operating voltage for the IC before testing.

---

## Selecting an IC

Rotate the encoder to select the required IC family and device, then press the encoder to confirm.

IC Selection

Figure 9 - selecting an IC.

---

## Running a Test

Press the TEST button and wait for the result.

The display shows the test progress. 

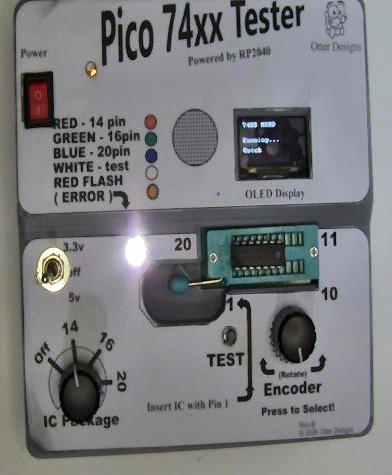
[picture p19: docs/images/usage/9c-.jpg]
Testing


Figure 10 - IC under test.

---

## Quick Test

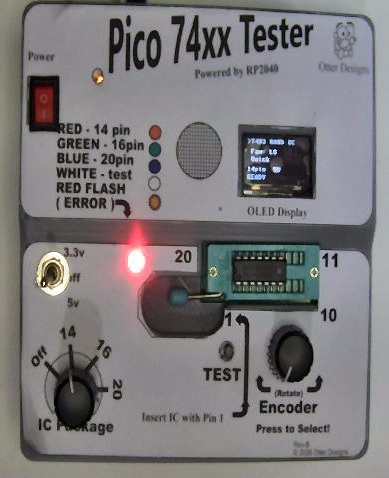
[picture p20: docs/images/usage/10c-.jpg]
quick Testing


Figure 11 - IC quick test.

---

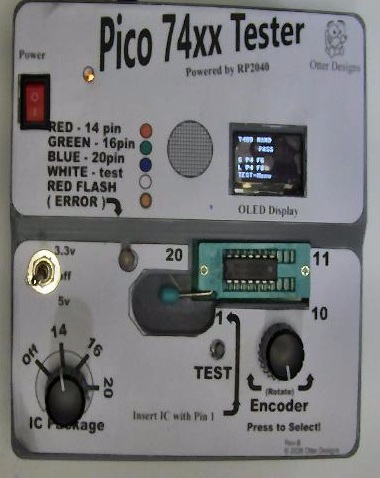
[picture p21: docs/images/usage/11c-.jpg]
quick Test pass


Figure 12 - IC quick test pass.

---

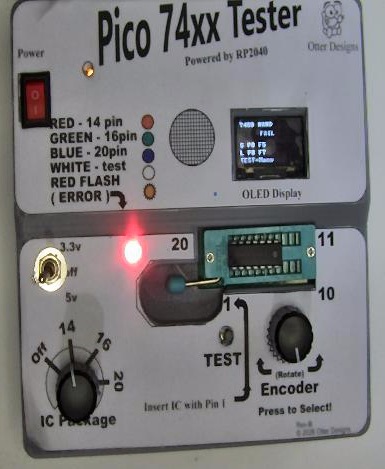
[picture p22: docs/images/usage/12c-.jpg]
quick Test fail


Figure 13 - IC quick test fail.

---

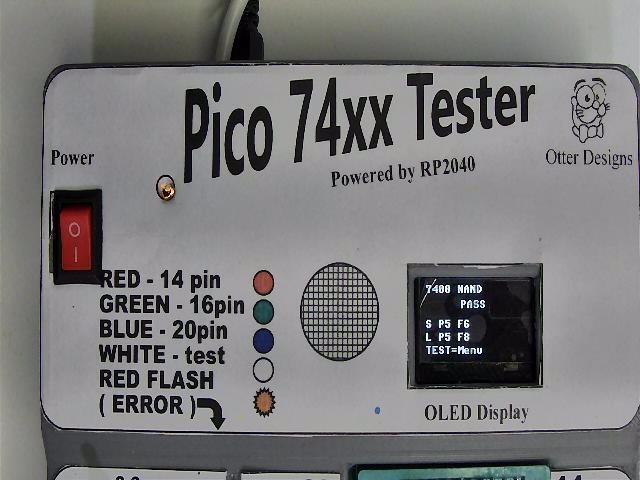
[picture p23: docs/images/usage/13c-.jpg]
Close up pass


Figure 14 - close-up quick test pass.

---

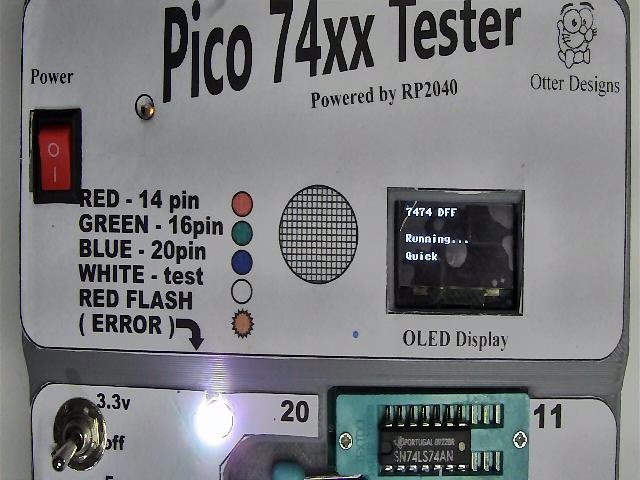
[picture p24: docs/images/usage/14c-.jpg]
running quick Test


Figure 15 - running quick test.

---

Quick Test performs a rapid functional check of the IC.

Typical execution time is approximately 10 seconds, depending on the device.

### PASS

The IC passed the basic functional tests.

### FAIL

The IC failed one or more functional tests...

---

## Full Test

Full Test performs additional functional verification and therefore takes longer than Quick Test.

Full Test pass

Figure 16 - full test pass.

---

Running Full Test

Figure 17 - Running full test.

---

Full Test performs a more comprehensive verification than Quick Test.

For maximum confidence, run a Soak Test to exercise the IC continuously over an extended period.

---

## Soak Test

Some devices may be tested continuously.

Select **Soak Test** from the menu.

The tester repeatedly exercises the IC until cancelled.

---

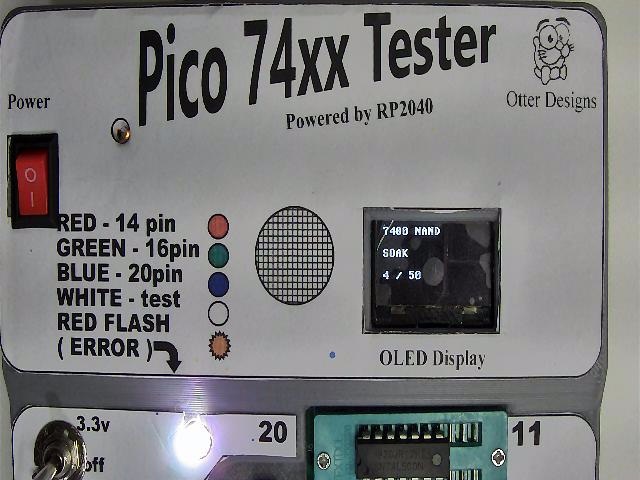
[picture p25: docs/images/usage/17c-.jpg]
Soak Test Start


Figure 18 - soak test start.

---

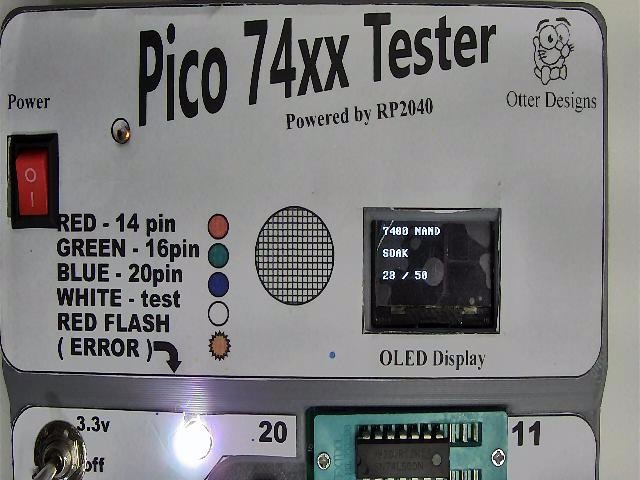
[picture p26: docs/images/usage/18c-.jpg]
Soak Test Halfway


Figure 19 - soak test halfway.

---

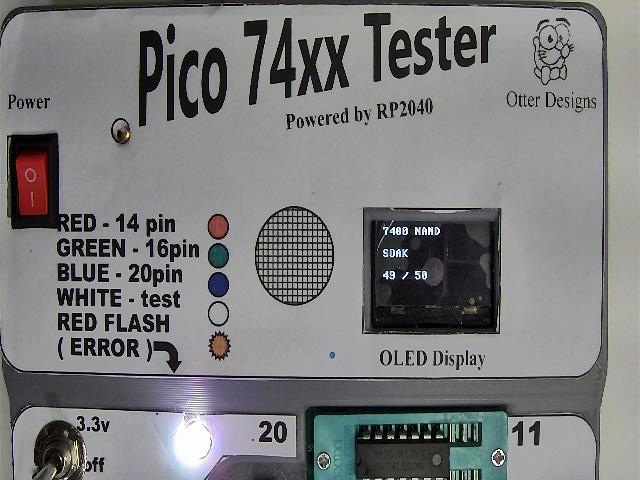
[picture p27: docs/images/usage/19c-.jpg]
Soak Test Finished


Figure 20 - soak test finished.

---

Soak Test repeatedly exercises the IC to help identify intermittent or temperature-related faults.

As the IC reaches its normal operating temperature, faults that do not appear during shorter tests may become apparent.

---

## Failed IC Example

Failed IC

Figure 21 - failed IC test.

If a test reports FAIL then the IC did not pass one or more functional checks.

For additional diagnostic information, connect the Raspberry Pi Pico 2 USB port to your computer and view the serial output in Thonny or another serial terminal.

If the fault is unclear, check the following before retesting:

• IC Voltage Selector is set correctly.
• IC orientation is correct.
• The correct IC type has been selected.
• The IC pins are clean and undamaged.

---

## Removing an IC

When testing has completed:
1. Switch the IC power to OFF.
2. Open the ZIF socket.
3. Remove the IC.
4. Insert the next IC and close the ZIF socket when ready.

---

## Supported Devices

Refer to the **Supported ICs** document for the complete list of supported devices.

---

## Troubleshooting

If a device repeatedly fails:

- Verify the correct voltage is selected.
- Check IC orientation.
- Confirm the correct device has been selected.
- Inspect the IC for bent or damaged pins.
- Clean oxidised pins if necessary.

For further assistance refer to the **Troubleshooting Guide**.

---

## Next Steps

You should now be familiar with the basic operation of your **OD-PT74 Pico 74xx IC Tester**.

Continue with the following guides to explore the supported IC library or to diagnose hardware and firmware issues if required.

## Related Documentation

| Document | Description |
|---|---|
| [🏠 Project Home](../../README.md) | Return to the main project page |
| [📖 Documentation Index](../README.md) | Browse all project documentation |
| [🚀 Getting Started](getting-started.md) | First-time setup |
| [🔧 Build Guide](build-guide.md) | Hardware assembly |
| [💾 Firmware Guide](firmware-guide.md) | Installing and updating the firmware |
| **▶️ Usage Guide** | **You are here** |
| [🧩 Supported ICs](supported-ics.md) | List of supported logic devices |
| [🛠 Troubleshooting Guide](troubleshooting-guide.md) | Diagnose common hardware and firmware issues |

---

| ← Previous | Next → |
|---|---|
| [💾 Firmware Guide](firmware-guide.md) | [🧩 Supported ICs](supported-ics.md) |

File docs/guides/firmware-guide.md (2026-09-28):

# Firmware Guide

Thonny Installed

Welcome to the **Firmware Guide** for the **OD-PT74 Pico 74xx IC Tester**.

This guide explains how to prepare a Raspberry Pi Pico (RP2040) by installing MicroPython and loading the OD-PT74 firmware. It provides a step-by-step walkthrough using the Thonny IDE, from connecting the Pico for the first time to running the firmware and verifying that the tester is operating correctly.

The firmware consists of two Python files:

- `main.py` – Main application firmware.
- `ssd1306.py` – OLED display driver.

No previous experience with MicroPython is required. Simply follow each step in order, and your tester will be ready to use in just a few minutes.

---

## Requirements

Before starting you will need:

- Raspberry Pi Pico 2 RP2040
- USB cable
- Computer running Windows, Linux or macOS
- Thonny IDE installed
- `main.py`
- `ssd1306.py`

> [!NOTE]
> This guide assumes the OD-PT74 hardware has already been assembled. 
>
> If you have not yet completed the hardware build, refer to the **Build Guide** before continuing.
>
> The firmware consists of two Python files:
> - `main.py` – Main application firmware.
> - `ssd1306.py` – OLED display driver.

---

## Installing Thonny

If Thonny is not already installed, download and install it before continuing.

Once installed, connect the Raspberry Pi Pico 2 to your computer using a USB cable.

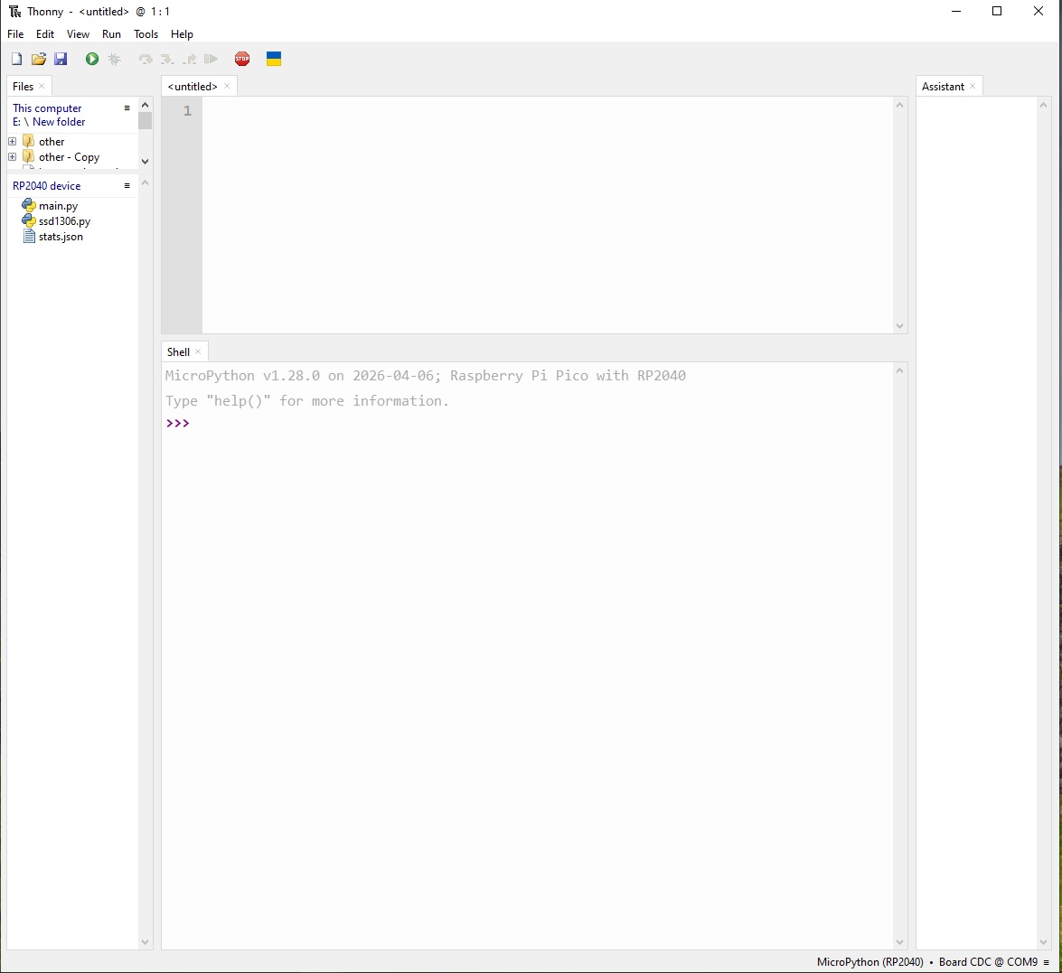
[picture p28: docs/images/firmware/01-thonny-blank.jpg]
Thonny Start


Figure 2 - Thonny IDE after starting.

Download and install the supported version of MicroPython as specified in the project README.

---

## Configure Thonny

Open the interpreter configuration.

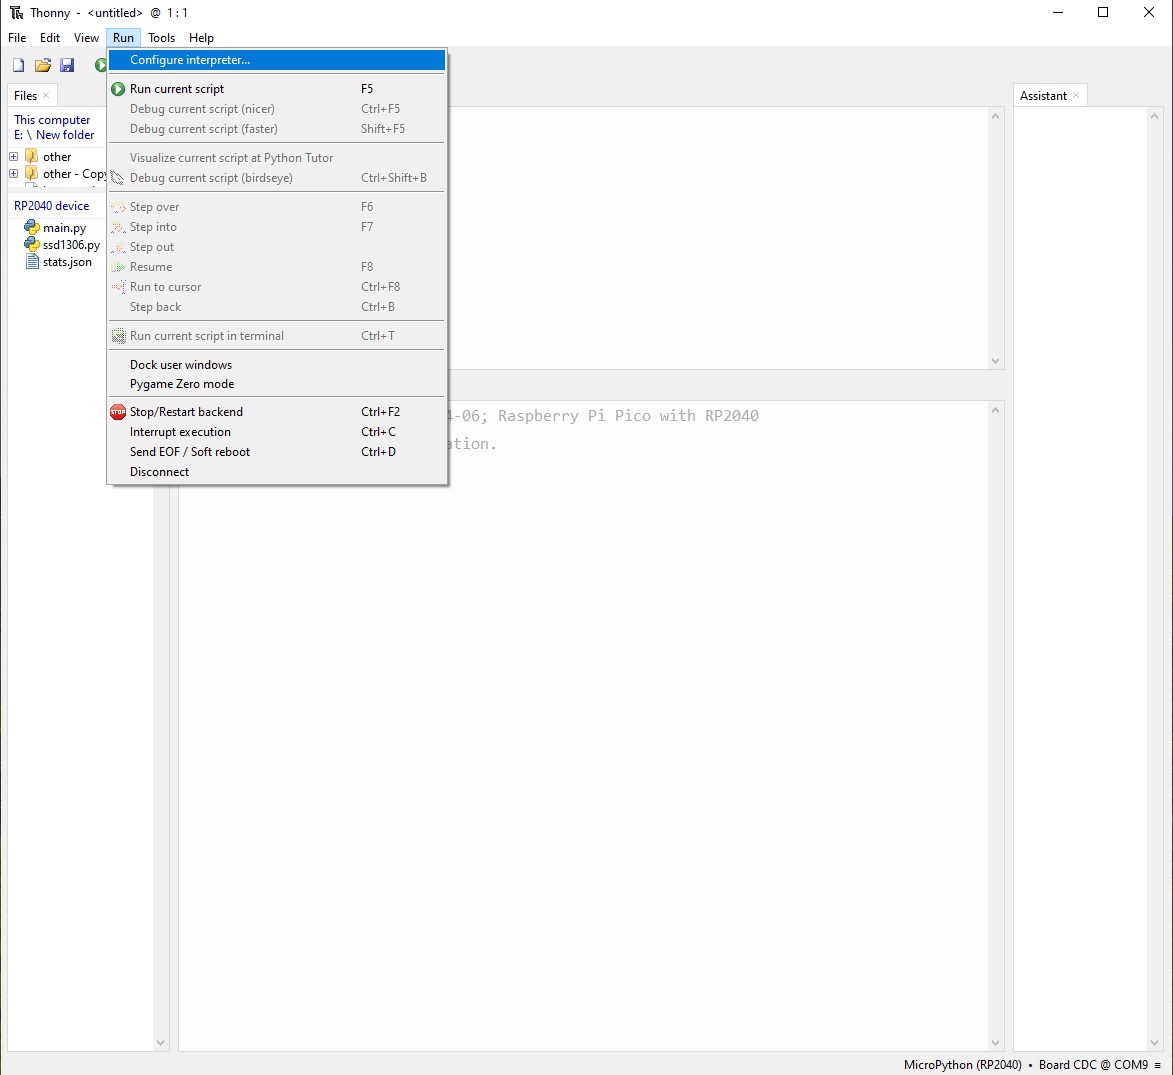
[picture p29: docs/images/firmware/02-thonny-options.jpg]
Interpreter Menu


Figure 3 - open the interpreter configuration.

Then select **Run → Interpreter...**

Select:

- **MicroPython (Raspberry Pi Pico)**

Connection:

- **Try to detect port automatically**

or select the correct COM port manually if required.

---

## Verify USB Connection

If no serial port is shown, open Windows Device Manager.

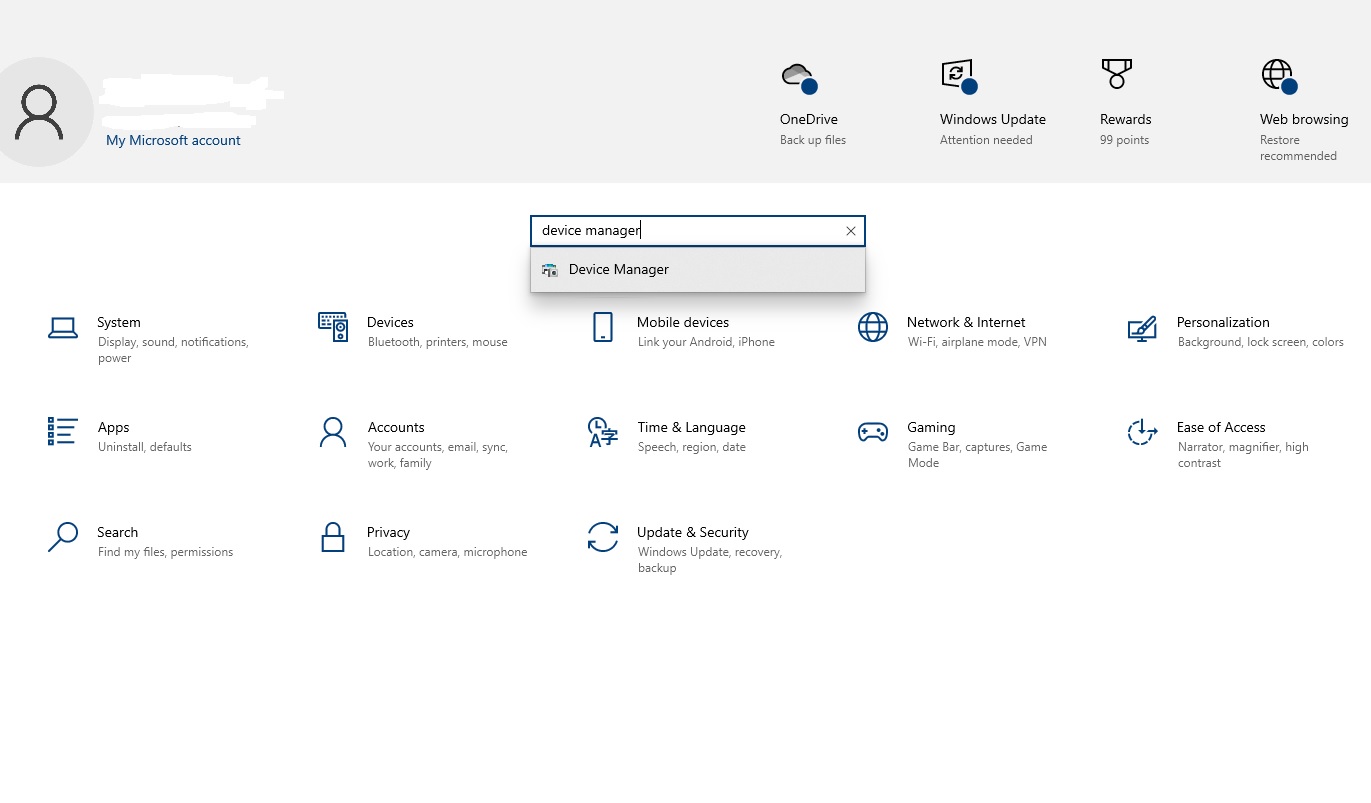
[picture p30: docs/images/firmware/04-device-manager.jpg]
Device Manager


Figure 4 - windows device manager.

Expand:

Ports (COM & LPT)

Verify that the Raspberry Pi Pico 2 serial port is listed.

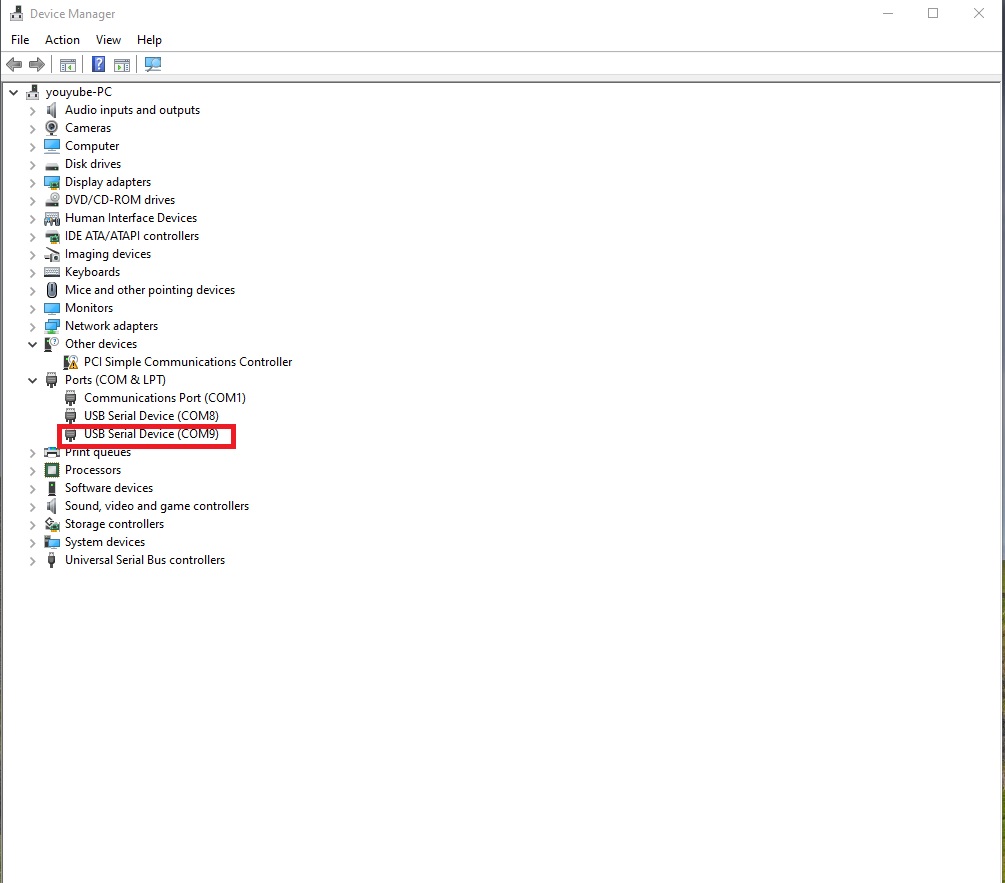
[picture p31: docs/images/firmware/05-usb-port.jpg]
USB Port


Figure 5 - pico USB serial port detected.

Return to Thonny and select this COM port.

---

## Copy main.py

Open the firmware file.

Select **File → Open**.

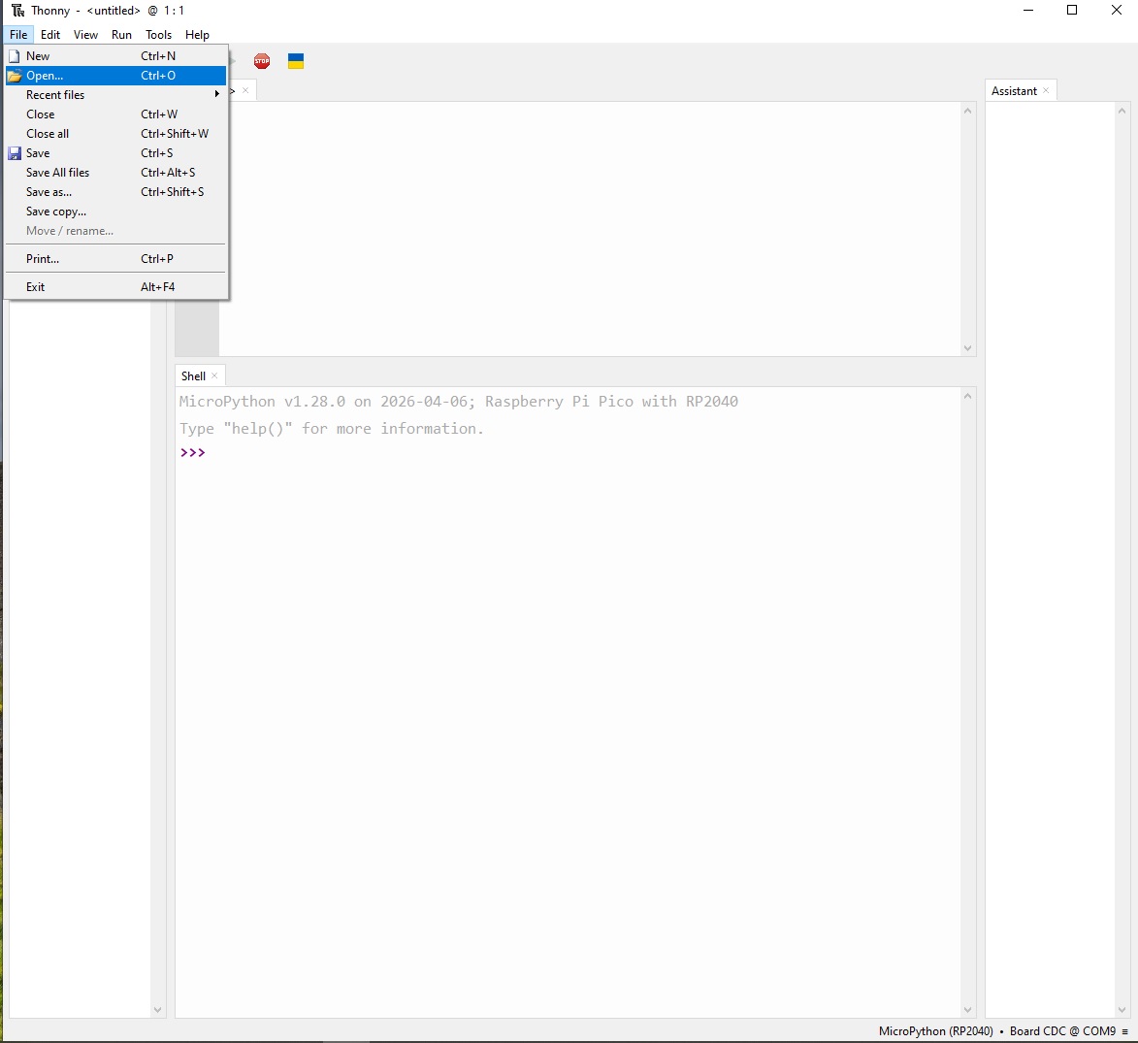
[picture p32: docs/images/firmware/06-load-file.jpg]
Load File


Figure 6 - opening a file.

Choose **This Computer**.

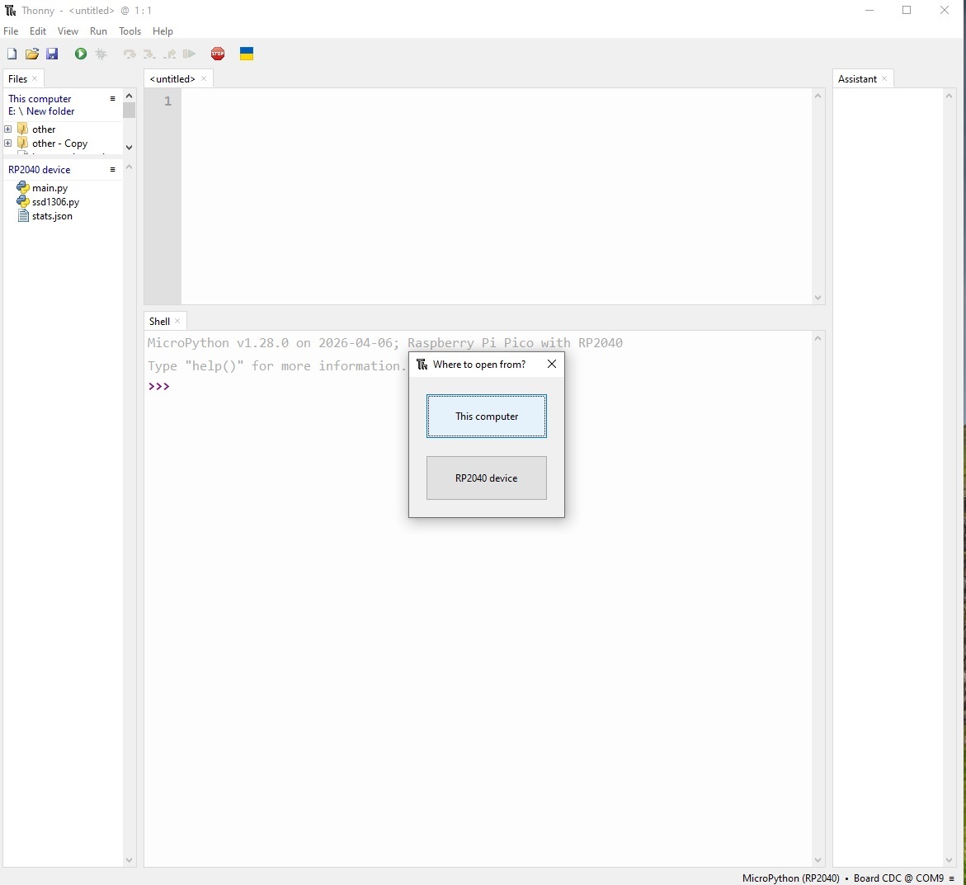
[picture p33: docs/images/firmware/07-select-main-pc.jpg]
Select PC


Figure 7 - select "this computer".

Browse to **firmware/main.py**.

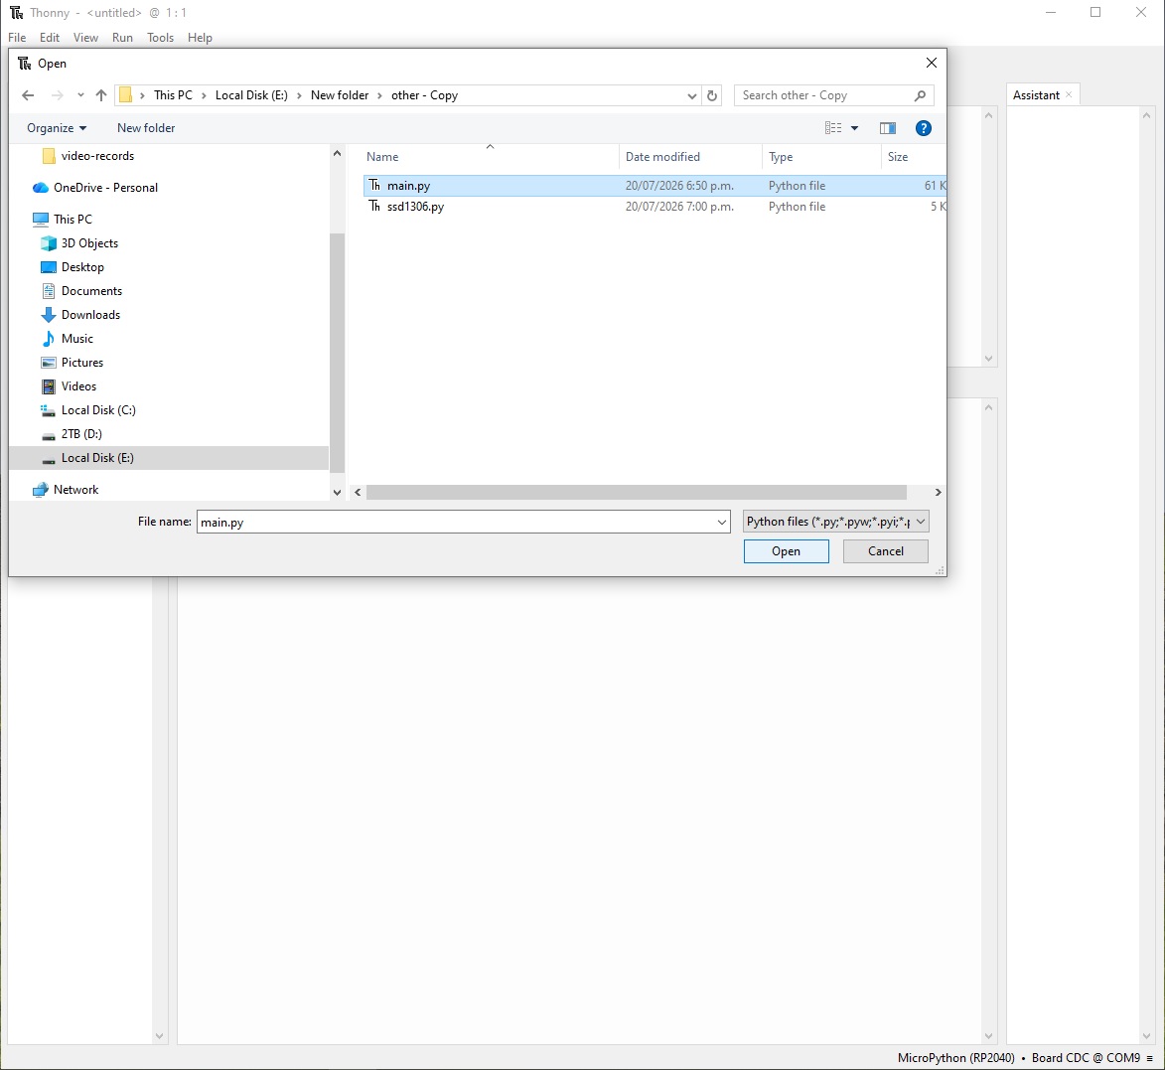
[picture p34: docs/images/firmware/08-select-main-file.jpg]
Select main.py


Figure 8 - select main.py.

The firmware source should now appear in the editor.

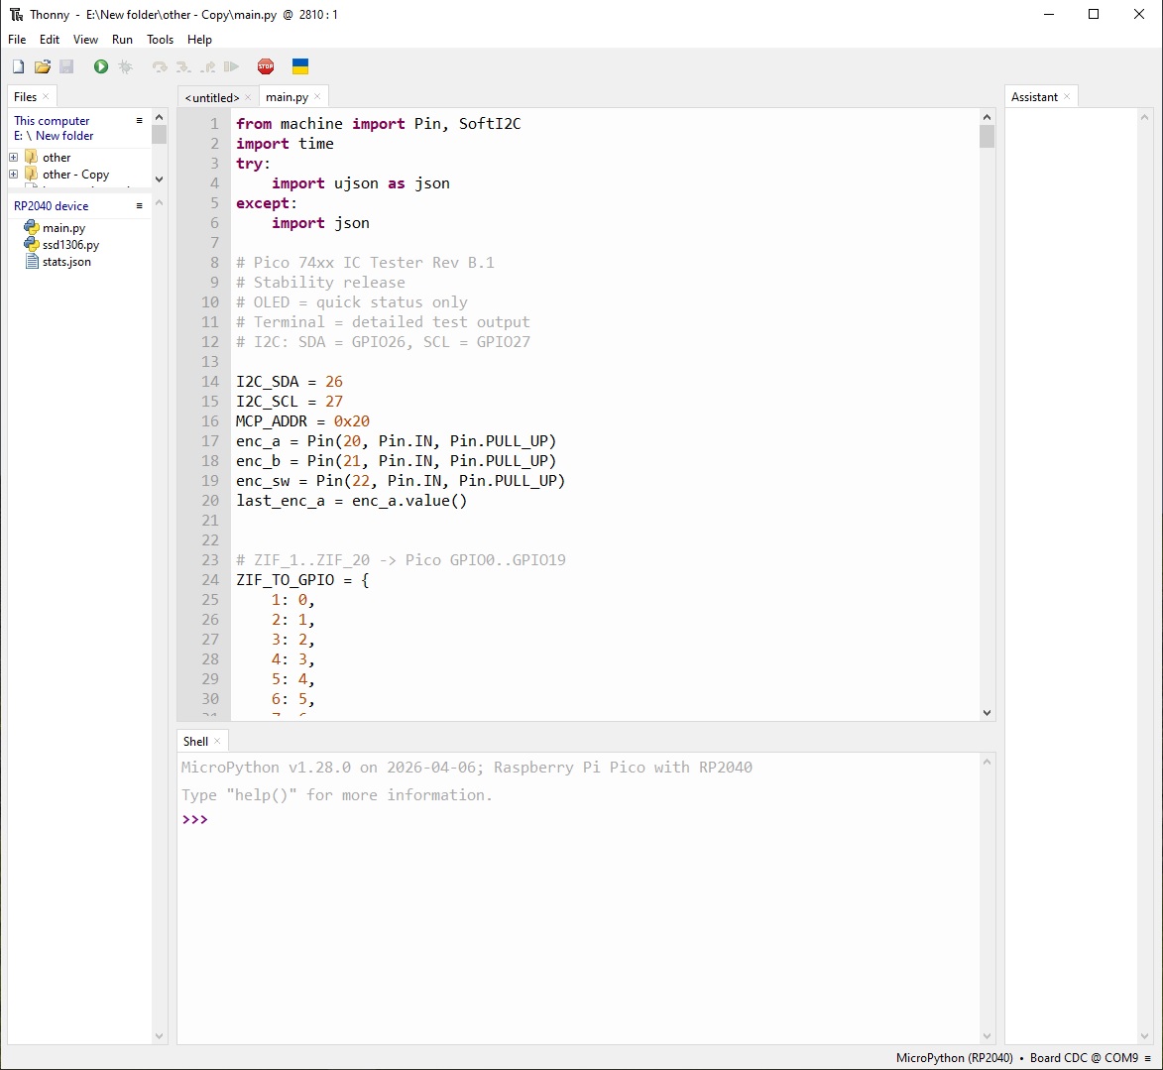
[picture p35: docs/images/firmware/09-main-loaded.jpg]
main.py Loaded


Figure 9 - main.py loaded into thonny.

---

## Save main.py

Select **File → Save As...**

Choose **Raspberry Pi Pico 2**.

Do **not** save the file back to your PC.

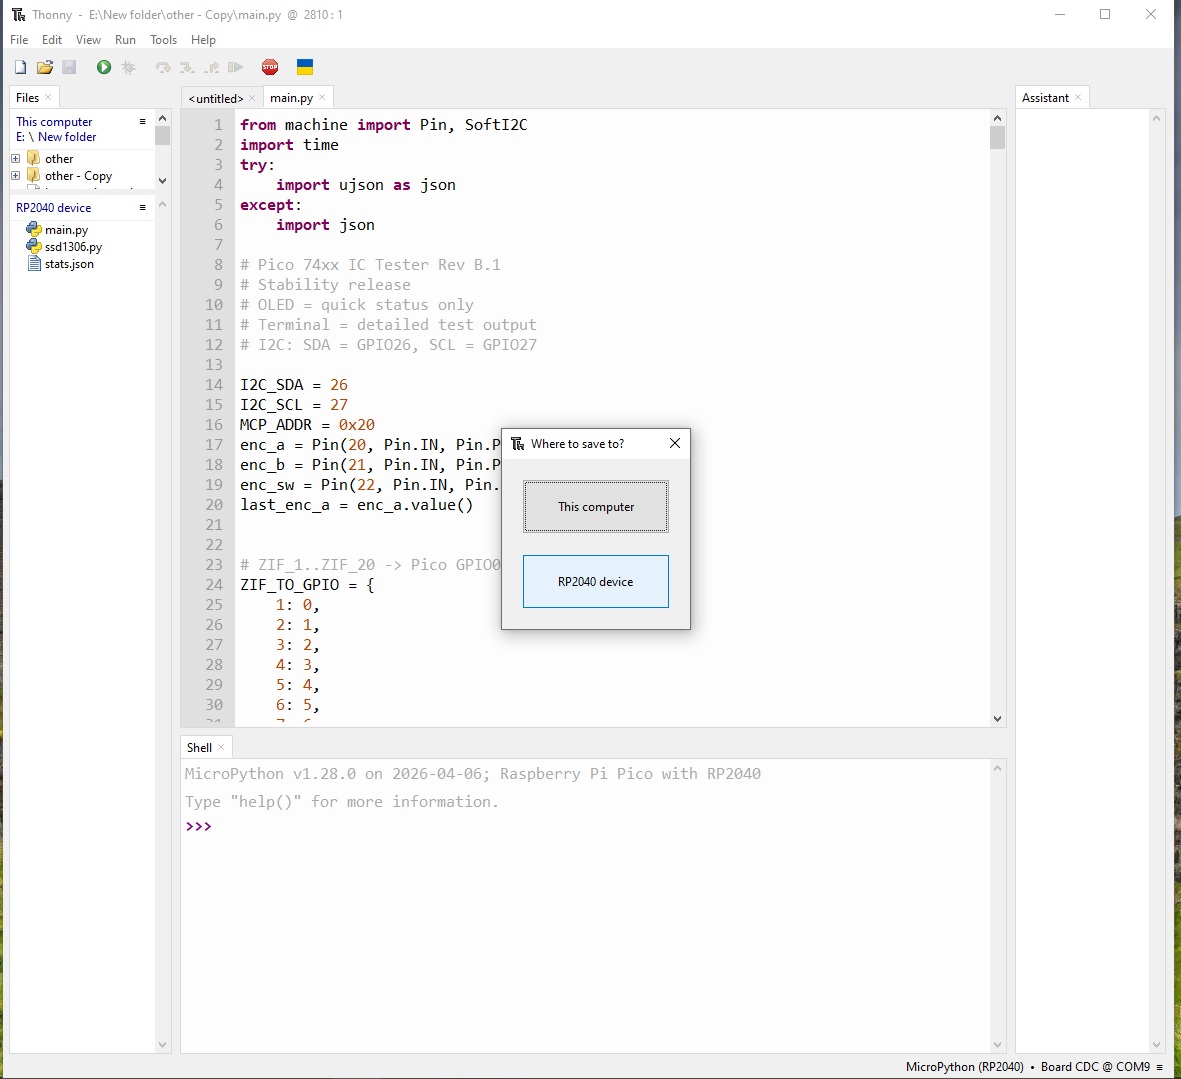
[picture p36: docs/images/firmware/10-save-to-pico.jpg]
Save to Pico


Figure 10 - save main.py to the pico.

---

## Copy ssd1306.py

Repeat the same process for the OLED driver.

Open **ssd1306.py**.

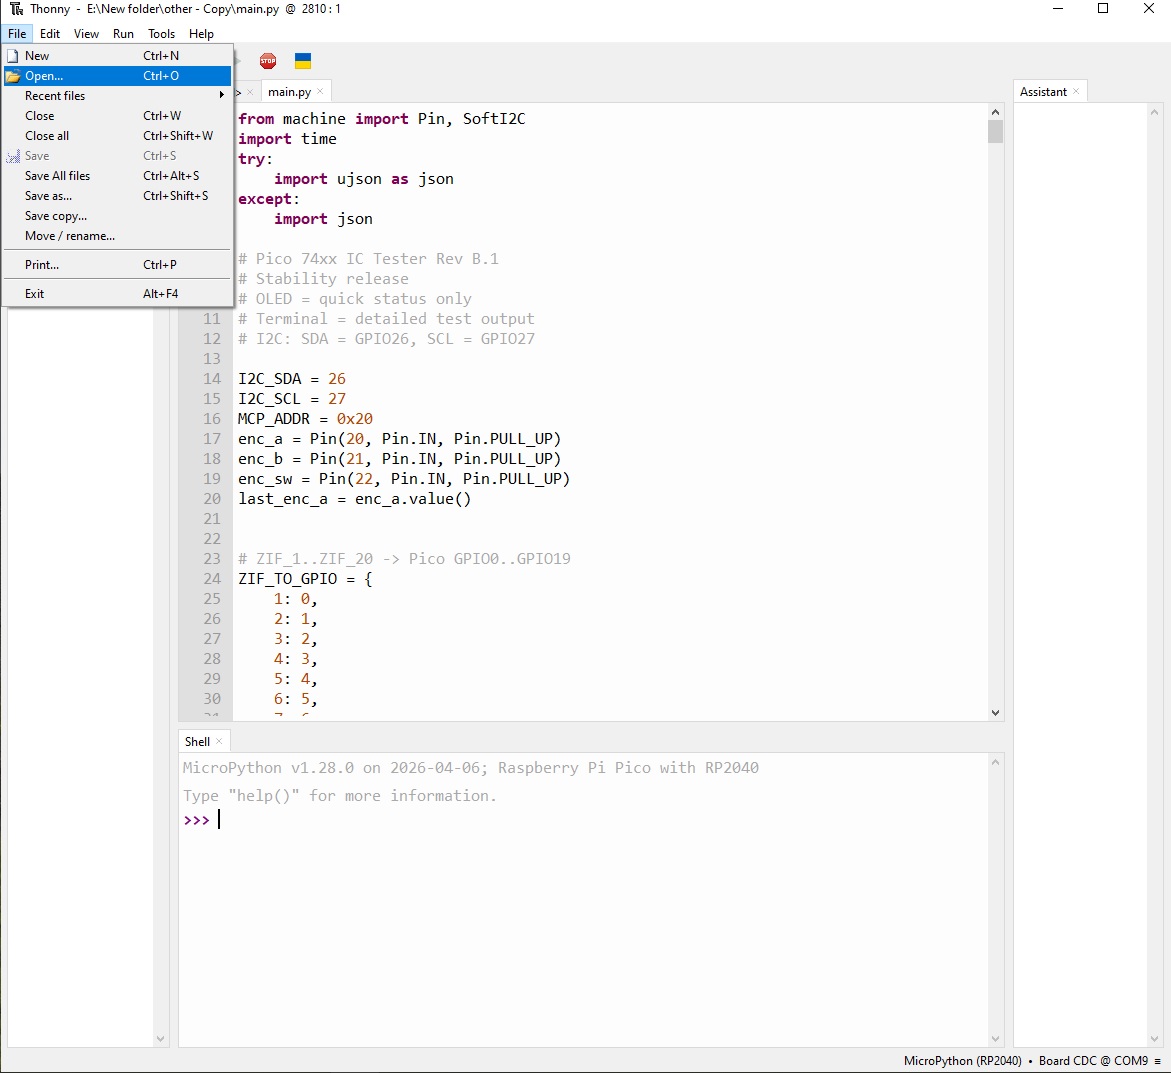
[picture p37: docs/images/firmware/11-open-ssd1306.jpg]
Open OLED Driver


Figure 11 - open ssd1306.py.

Select the file.

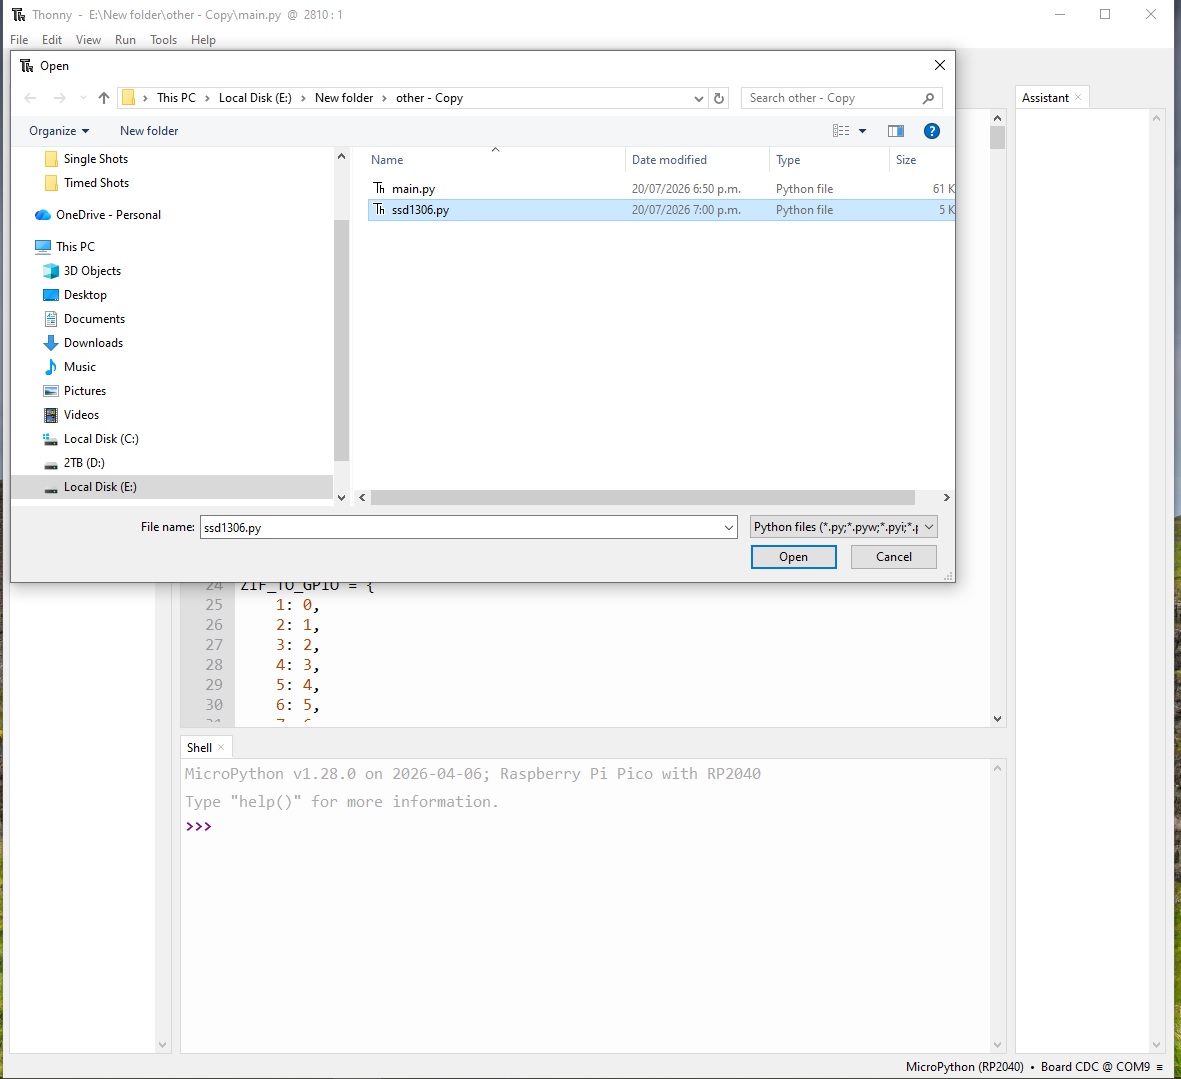
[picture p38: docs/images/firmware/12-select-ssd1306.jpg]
Select OLED Driver


Figure 12 - select ssd1306.py.

Save it to the Raspberry Pi Pico 2.

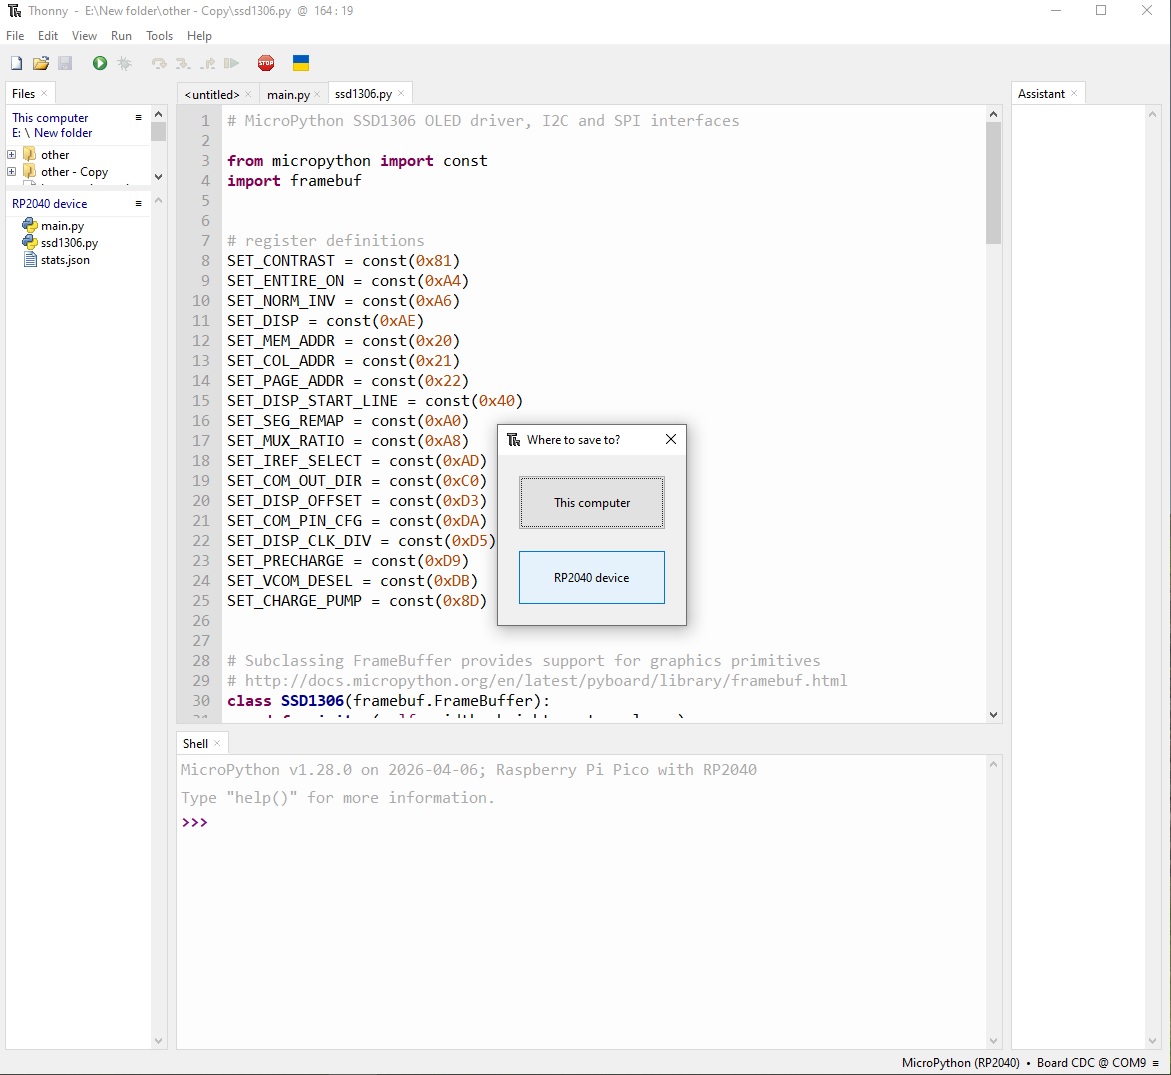
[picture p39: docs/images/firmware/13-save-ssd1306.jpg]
Save OLED Driver


Figure 13 - save ssd1306.py to the Pico 2.

---

## Run the Firmware

Close the OLED driver.

You should see "main.py" and "ssd1306.py" on the left panel under RP2040 device.

A stats.json file will be created automatically after you begin testing ICs. It stores tester statistics and does not need to be copied manually.

Ensure **main.py** is the active editor window.

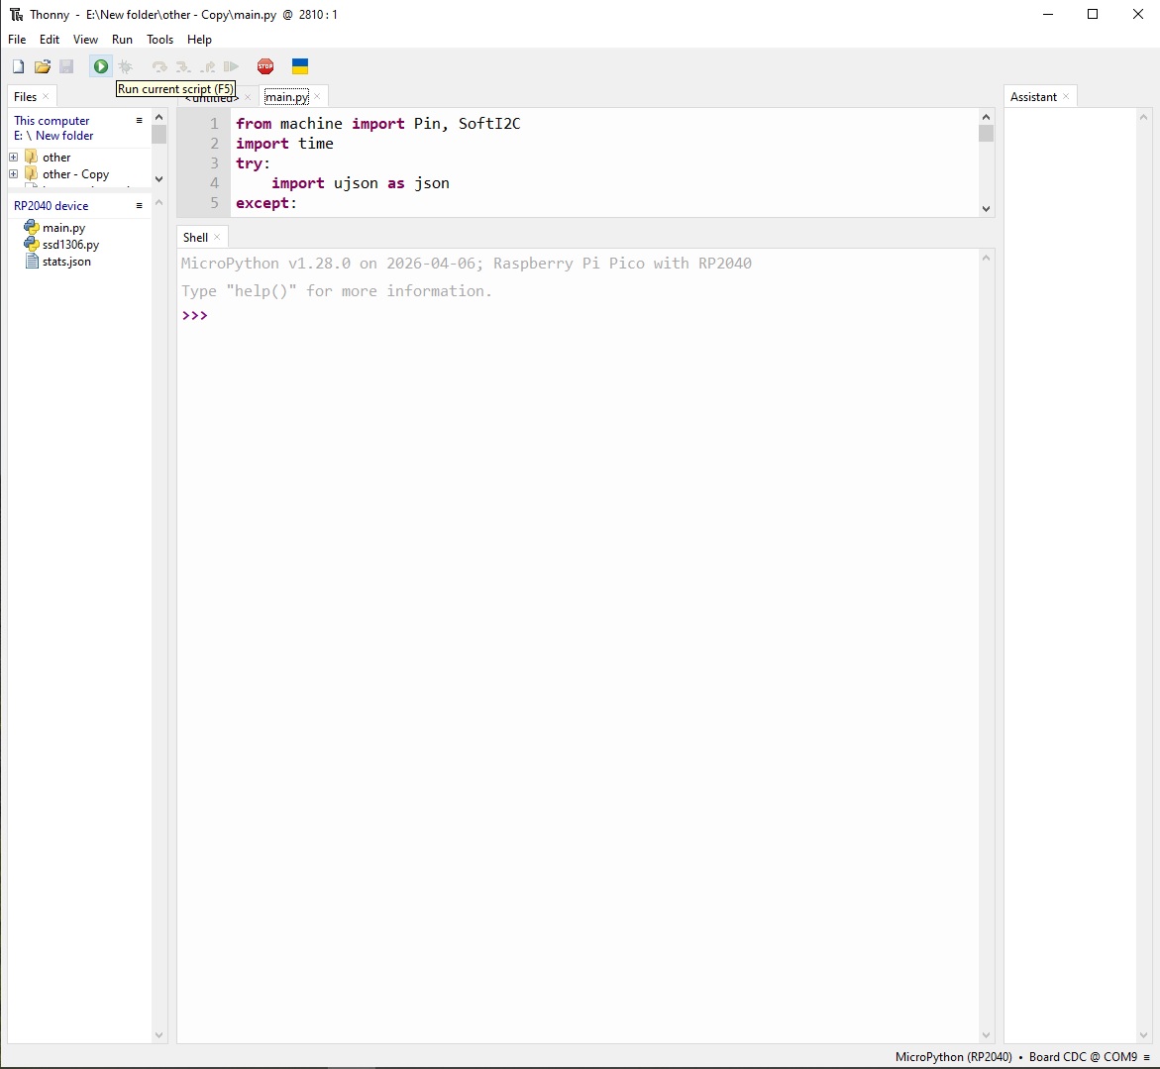
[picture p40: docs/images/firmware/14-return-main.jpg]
Return to main.py


Figure 14 - return to main.py.

Press the **Run** button **(green circle with arrow)** or press **F5**.

Run Firmware

Figure 15 - running the firmware.

The OD-PT74 should now boot, perform its Power-On Self Test (POST), and display the main menu.

If the OLED display does not initialise, confirm that:

- `main.py` has been copied.
- `ssd1306.py` has been copied.
- The correct interpreter is selected.
- The Pico 2 is connected.

---

## Verifying Operation

If installation was successful, the following screens illustrate the normal operating modes of the OD-PT74.

The following screenshots show normal operation of the firmware.

## Quick Test

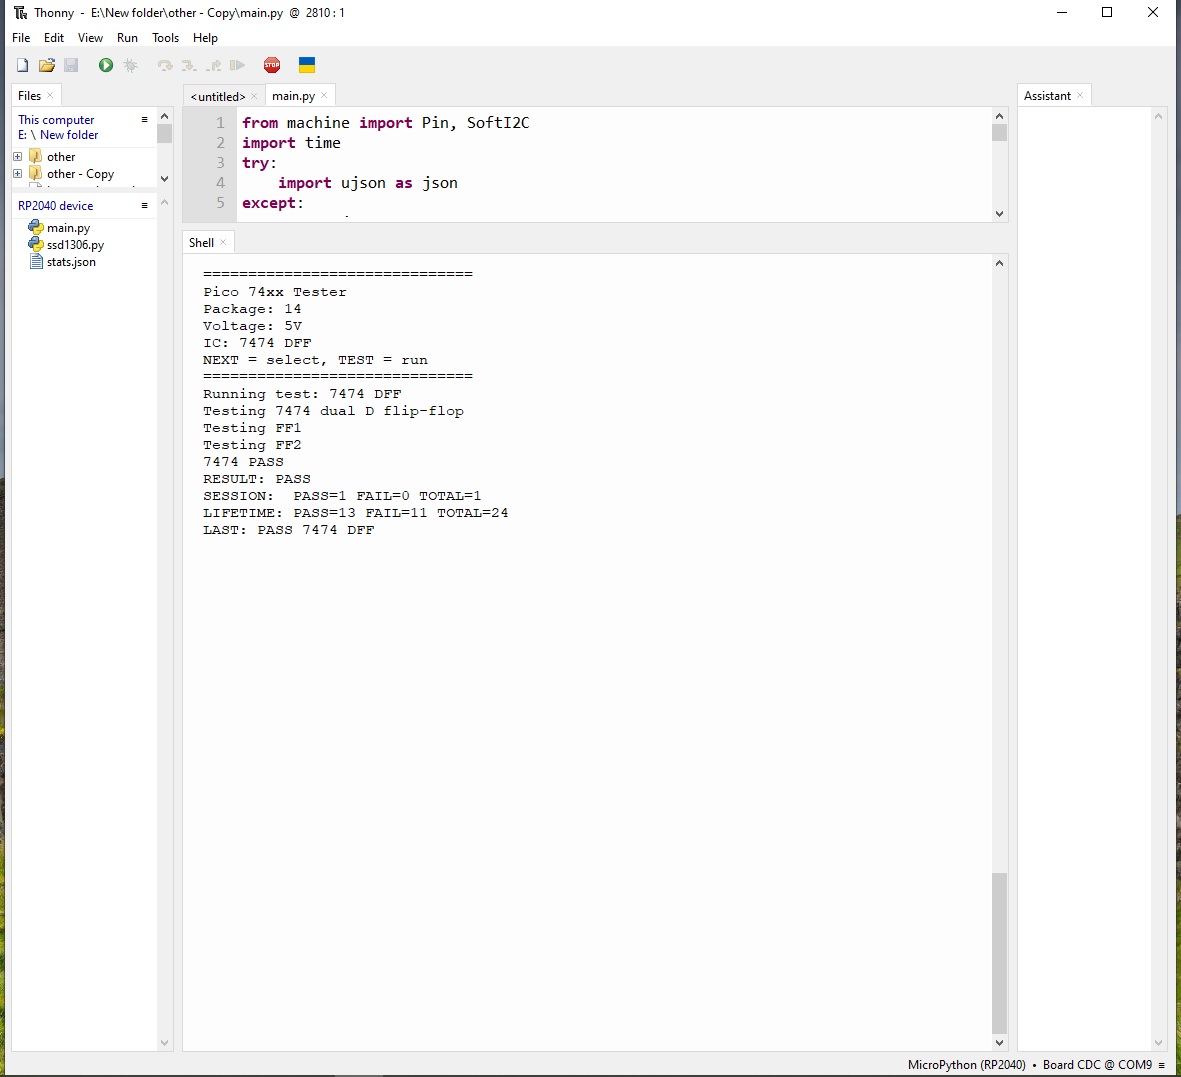
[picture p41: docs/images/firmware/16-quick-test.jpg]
Quick Test


Figure 16 - Quick test.

## Full Test

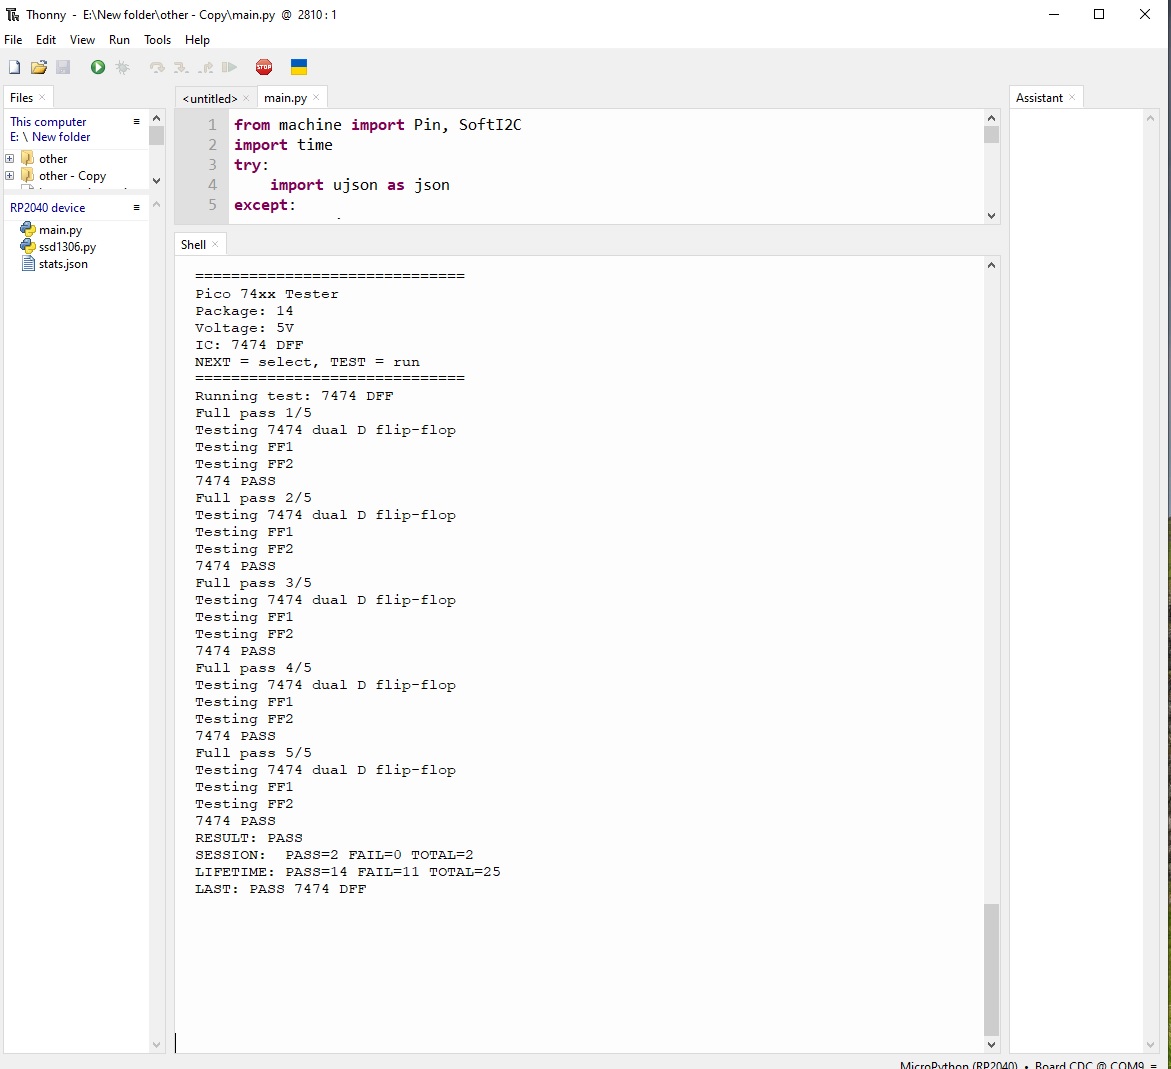
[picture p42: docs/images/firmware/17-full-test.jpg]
Full Test


Figure 17 - Full test.

## Soak Test

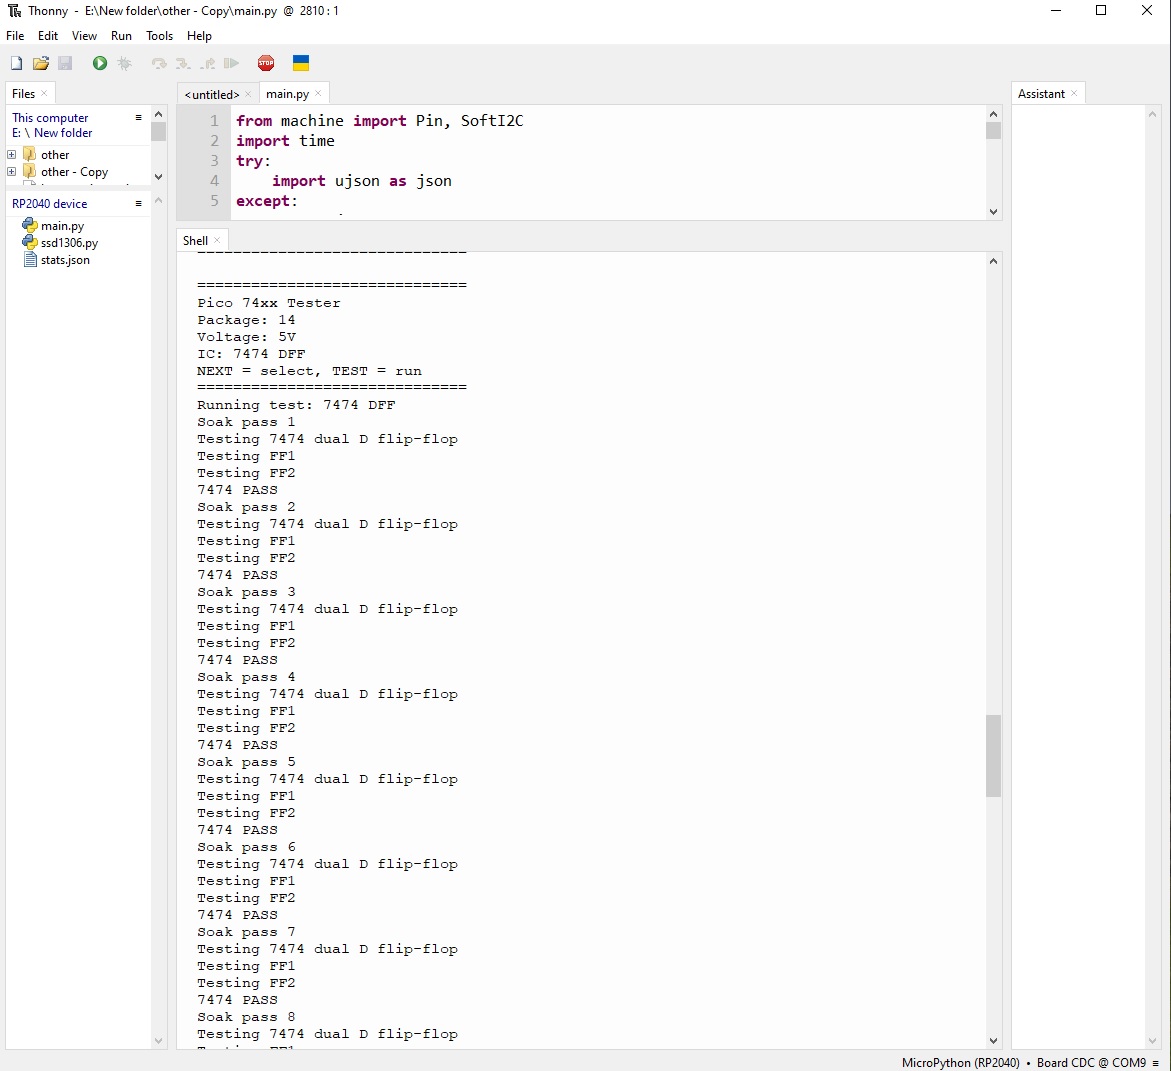
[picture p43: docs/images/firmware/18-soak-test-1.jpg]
Soak Test 1


Figure 18 - Soak test.

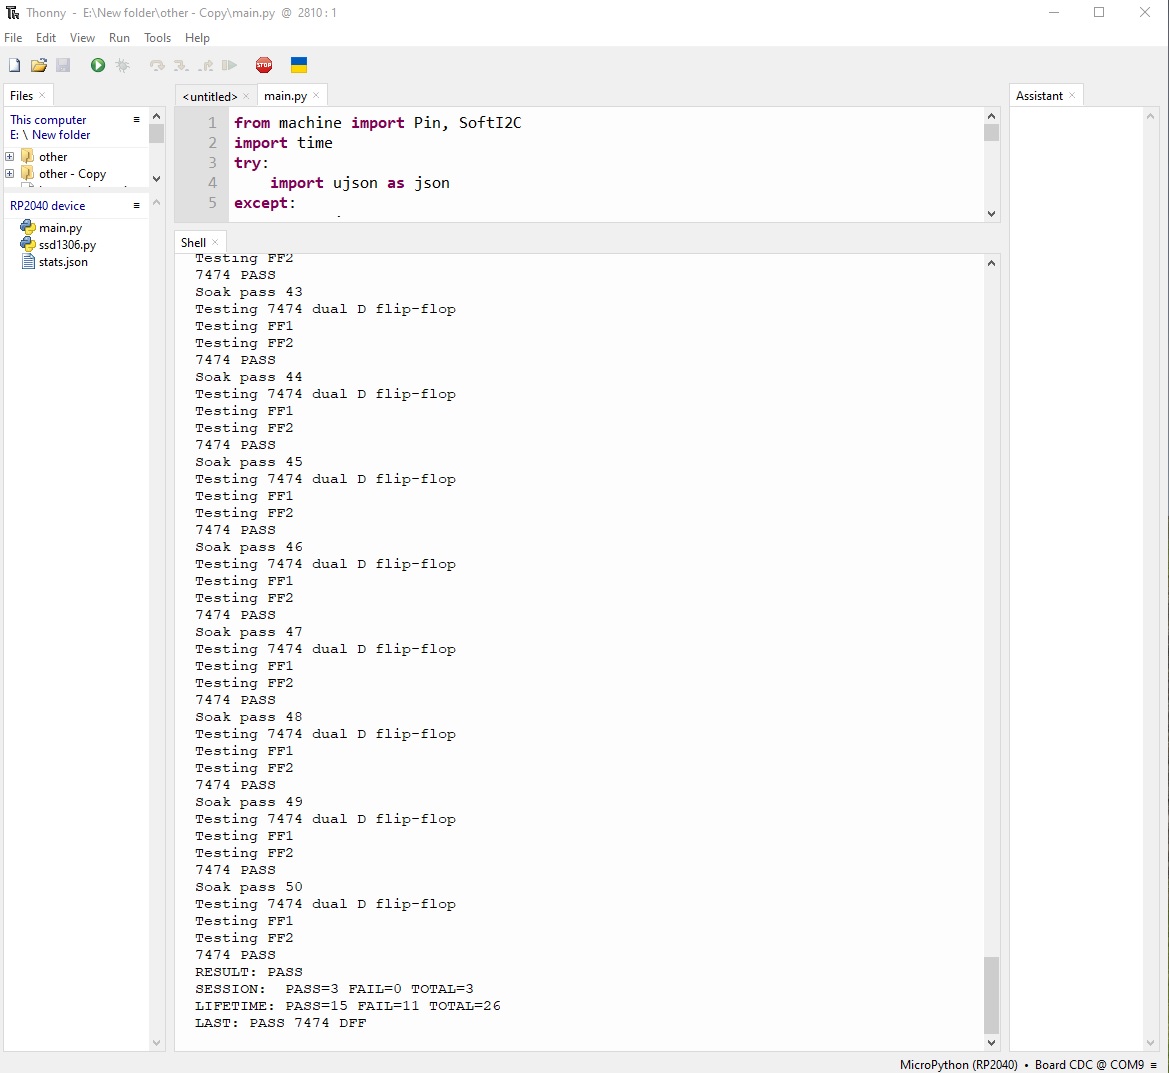
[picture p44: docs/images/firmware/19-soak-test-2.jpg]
Soak Test 2


Figure 19 - Soak test complete.

## Failure Examples

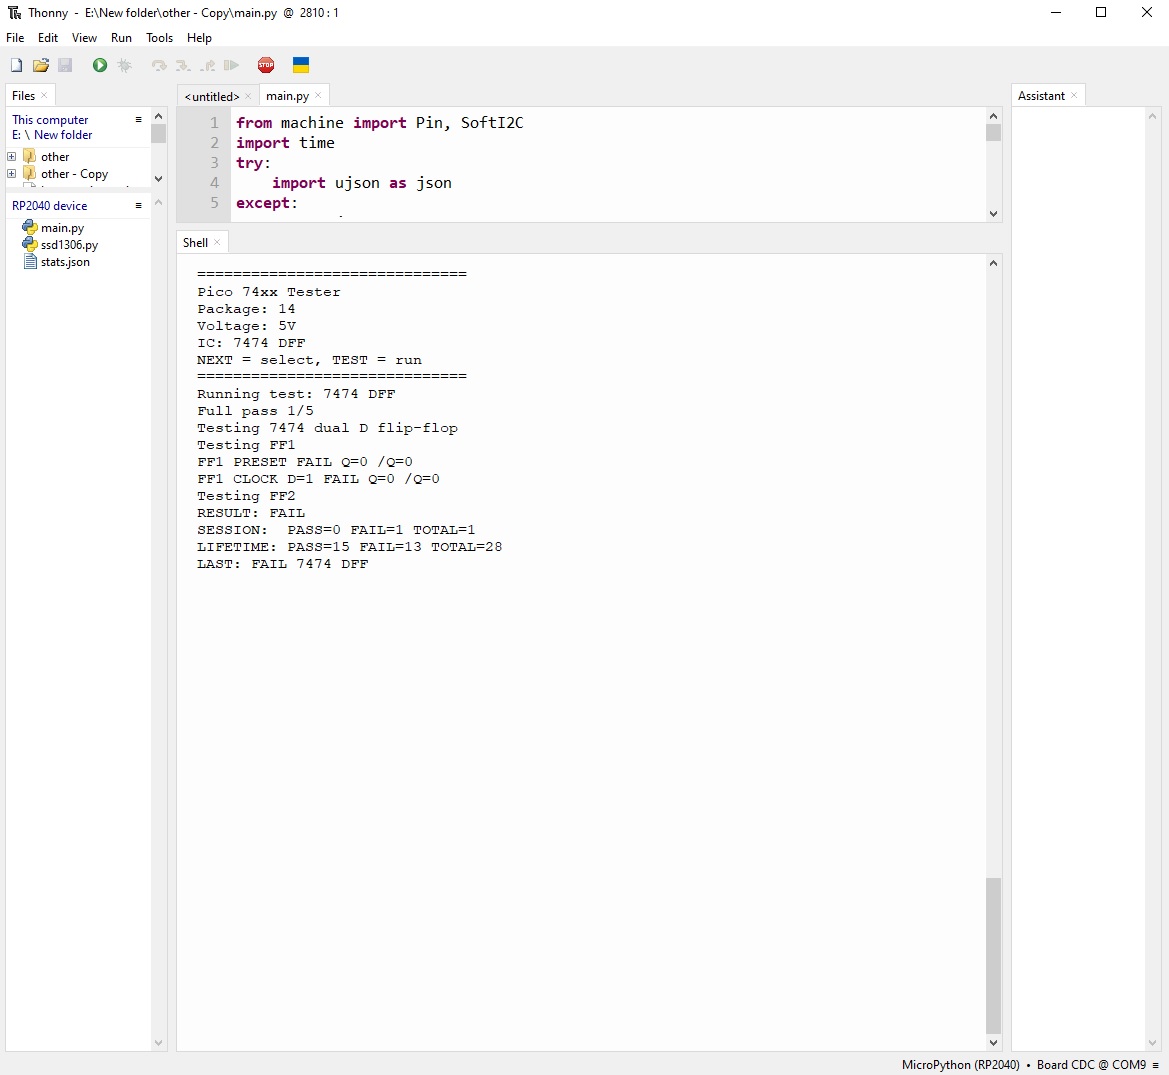
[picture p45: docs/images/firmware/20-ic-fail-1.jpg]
Failure 1


Figure 20 - Failed IC example.

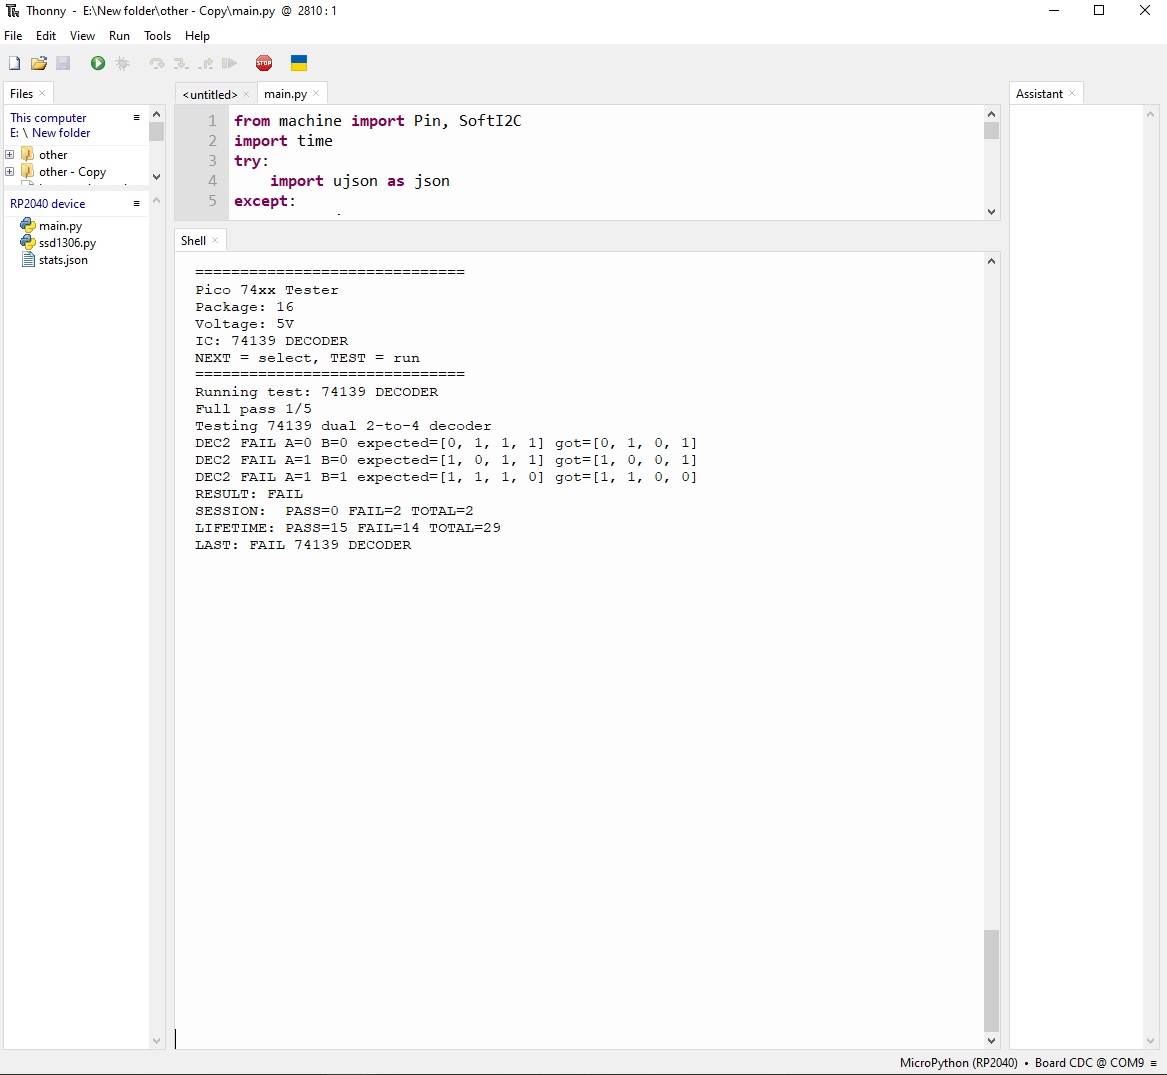
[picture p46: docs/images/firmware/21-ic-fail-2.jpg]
Failure 2


Figure 21 - Failed IC example.

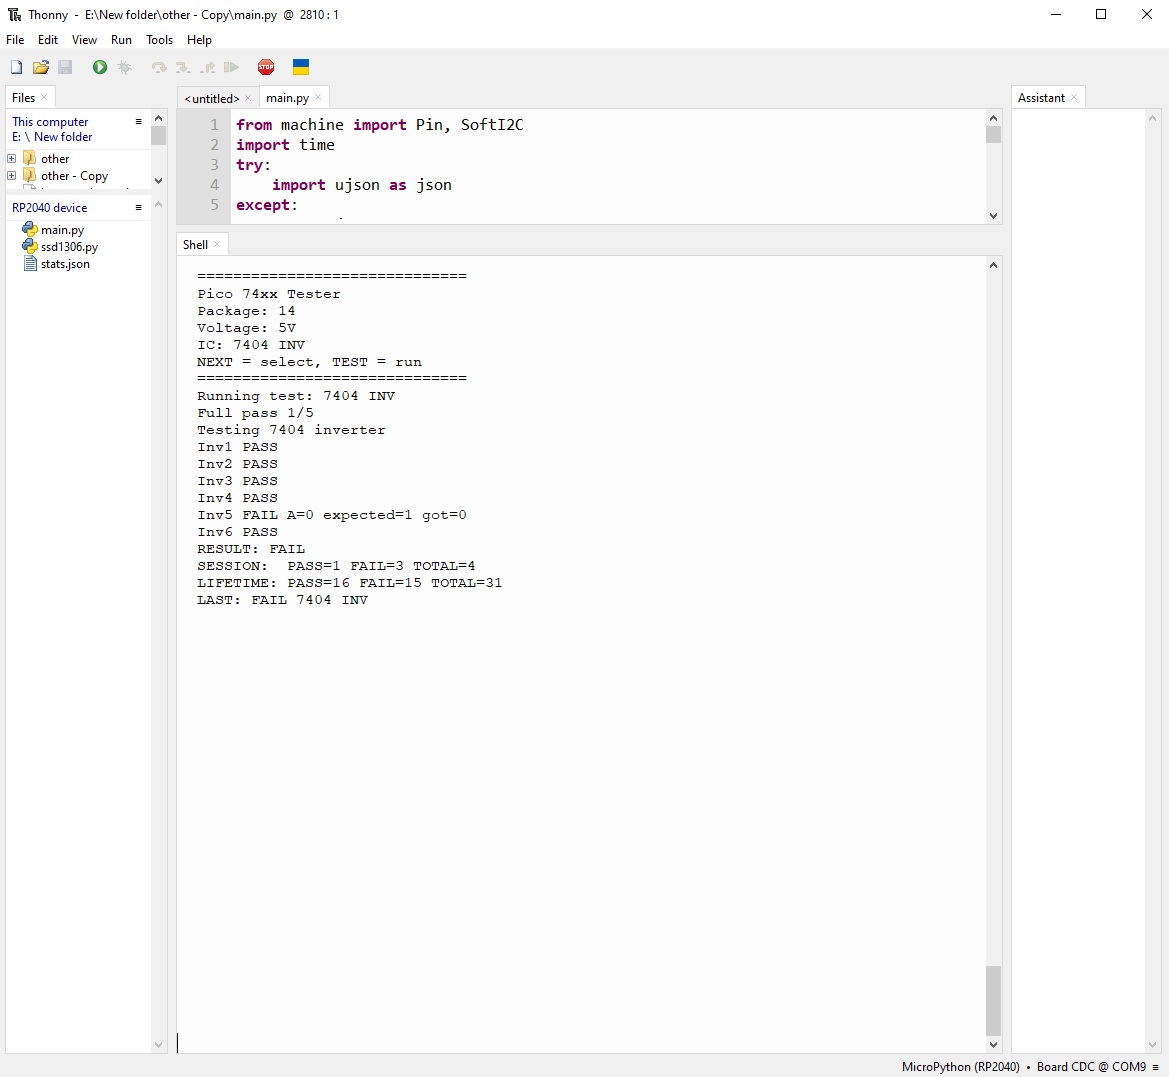
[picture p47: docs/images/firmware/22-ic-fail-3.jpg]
Failure 3


Figure 22 - Failed IC example.

---

---

## Next Steps

Your **OD-PT74 Pico 74xx IC Tester** firmware should now be installed and ready to use.

Continue with the following guides to learn how to operate the tester, explore the supported IC library, and diagnose any hardware or firmware issues.

## Related Documentation

| Document | Description |
|---|---|
| [🏠 Project Home](../../README.md) | Return to the main project page |
| [📖 Documentation Index](../README.md) | Browse all project documentation |
| [🚀 Getting Started](getting-started.md) | First-time setup |
| [🔧 Build Guide](build-guide.md) | Hardware assembly |
| **💾 Firmware Guide** | **You are here** |
| [▶️ Usage Guide](usage-guide.md) | Operating the tester |
| [🧩 Supported ICs](supported-ics.md) | List of supported logic devices |
| [🛠 Troubleshooting Guide](troubleshooting-guide.md) | Diagnose common hardware and firmware issues |

---

| ← Previous | Next → |
|---|---|
| [🔧 Build Guide](build-guide.md) | [▶️ Usage Guide](usage-guide.md) |

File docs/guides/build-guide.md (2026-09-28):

# Build Guide

## Introduction

This guide describes the assembly of the **OD-PT74 Pico 74xx IC Tester** hardware.

The Rev-C design consists of two printed circuit boards that together form the complete tester. 

This guide follows the recommended assembly sequence, including inspection and verification checkpoints, to help ensure a successful build.

---

Completed Tester

*Figure 1. Completed OD-PT74 Pico 74xx IC Tester.*

---

## Before you begin

### Tools required

* Fine-tip soldering iron
* Quality electronic solder
* Side cutters
* Small pliers
* Tweezers
* Digital multimeter
* Magnification (recommended)

### Parts required

For a complete component list, refer to the Main Board BOM and Top Board BOM.

Before beginning assembly:

* Verify all components are present.
* Check resistor values.
* Identify all polarised components.
* Familiarise yourself with the PCB layout.

For a complete list check the **main-board & top-board b.o.m**

> [!TIP]
>
> Sort resistors and capacitors by value before starting. This makes assembly faster and significantly reduces mistakes.

---

## Assembly

## Stage 1 – Power supply

The Rev-C tester includes an onboard power supply. Assemble and verify this section before installing any other components.

Install:

* BAT54S protection diode(s)
* 3.3 V voltage regulator
* Associated bypass capacitors

Figure 2 shows the completed power supply section before electrical verification.

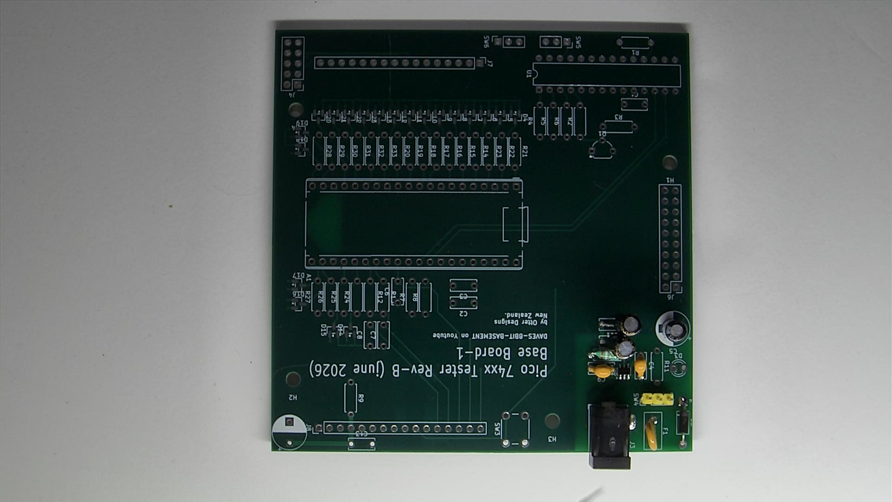
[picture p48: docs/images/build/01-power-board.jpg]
Power supply assembled


*Figure 2. Main board power supply assembled.*

### Power supply verification

Connect a regulated 5 V DC supply.

Verify:

* 5 V input present
* Stable 3.3 V regulator output
* No excessive current draw
* No component heating

---

**Testing for 3.3 v**

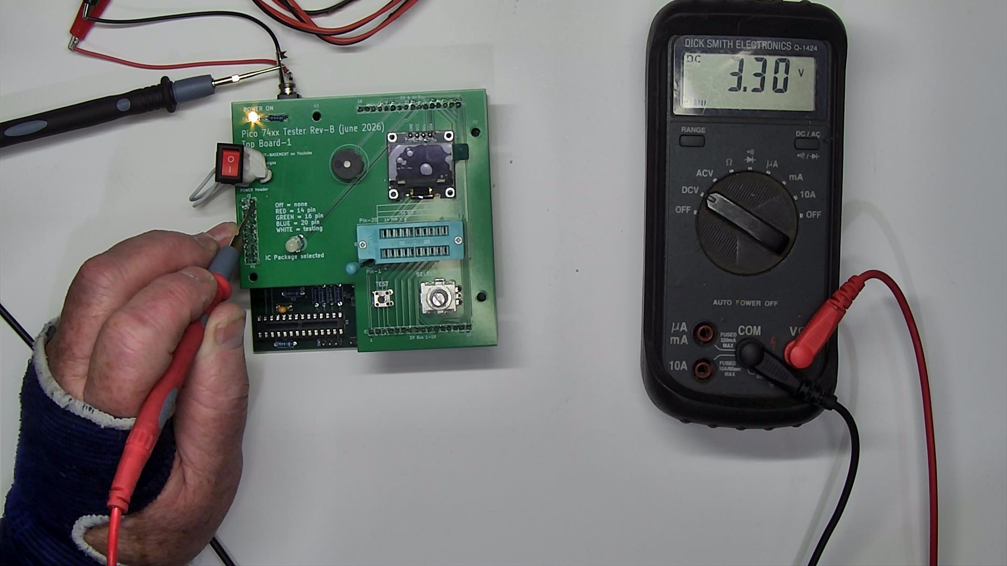
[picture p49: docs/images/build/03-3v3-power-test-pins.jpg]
Test Voltage 3v3


*Figure 3. Test 3.3 v on power board.*

---

**Testing for 5 v**

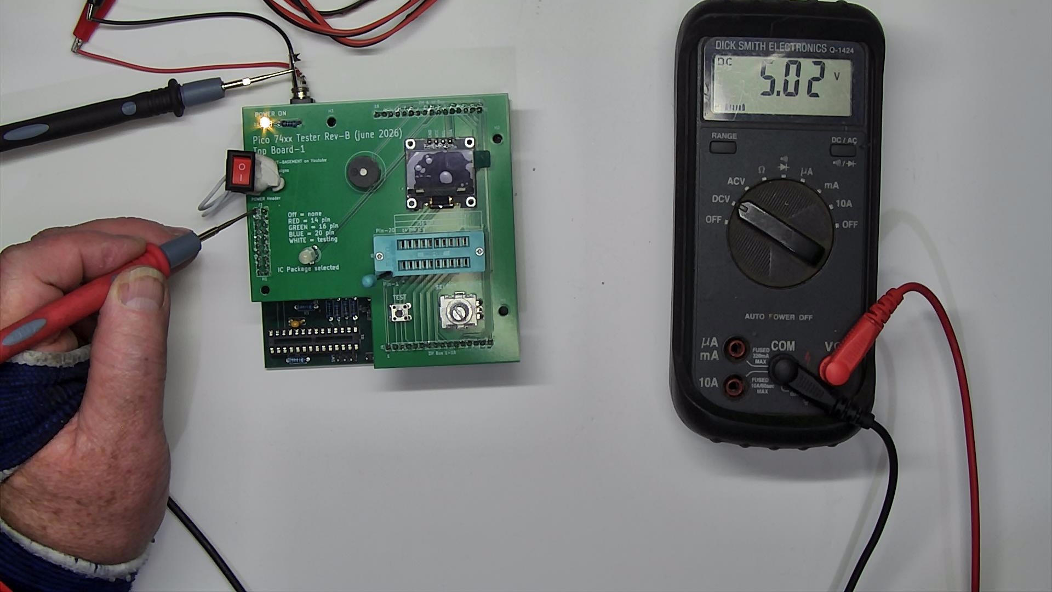
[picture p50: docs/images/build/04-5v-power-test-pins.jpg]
Test Voltage 5v


*Figure 4. Test 5 v on power board.*

---

** Disconnect power before continuing. **

> [!IMPORTANT]
>
> Verifying the power supply first makes fault finding much easier than troubleshooting a fully populated board.

---

## Stage 2 – Main board assembly

Populate the main board using the following order:

1. Resistors
2. Ceramic capacitors
3. Diodes
4. IC sockets
5. Headers and connectors

Figure 5 shows the main board after the passive components have been installed.

Main board after passives

*Figure 5. main board after passive components.*

Continue with:

* Push buttons
* LEDs
* Buzzer
* Remaining connectors

Complete the remaining through-hole components as shown in Figure 6.

Main board complete

*Figure 6. Completed main board assembly.*

### Assembly Checkpoint

Before continuing:

* ✓ No solder bridges
* ✓ Correct resistor values
* ✓ Correct diode orientation
* ✓ All IC sockets aligned
* ✓ Board cleaned and inspected

---

## Stage 3 – Top board assembly

> [!IMPORTANT]
> Before installing the OLED display, apply power and verify:
>
> - The 5 V rail measures correctly.
> - The 3.3 V rail measures correctly.
> - The 5 V and 3.3 V power indicators illuminate (if fitted).
>
> Disconnect power before installing the OLED display and continuing with Stage 3.

Assemble the top board.

Pay particular attention to:

* OLED header orientation
* Rotary encoder alignment
* Board-to-board connector alignment

Figure 7 shows the top board after the initial components have been installed.

Top board

*Figure 7. top board during assembly.*

Figure 8 shows the completed top board ready for final inspection.

Top board complete

*Figure 8. completed top board assembly.*

> [!NOTE]
> **Assembly Checkpoint**
>
> Before continuing, confirm:
>
> - No solder bridges
> - Correct resistor values
> - Correct diode orientation
> - All IC sockets aligned
> - Board cleaned and inspected

---

## Stage 4 – Raspberry Pi Pico 2

Install the Raspberry Pi Pico 2 only after both boards have passed inspection.

Before fitting the Pico 2:

* Verify there are no shorts between power rails.
* Check connector alignment.
* Confirm correct orientation.

Figure 9 shows the correct installation of the Raspberry Pi Pico.

Pico installed

*Figure 9. Raspberry Pi Pico 2 installed.*

---

## Stage 5 – Final assembly

Join the main and top boards.

Install:

* OLED module
* Remaining hardware
* Spacers and fasteners (if fitted)

Carry out a final visual inspection.

Figure 10 shows the completed hardware assembly before electrical testing.

Boards assembled

*Figure 10. Completed top board assembly.*

---

## Front Panel Wiring

Front Panel Wiring

*Figure 11. Front Panel Wiring assembly.*

The OD-PT74 uses three panel-mounted switches that are connected to the Base Board using wiring harnesses.

> **See also:** [Front Panel Wiring Guide](Switch-Wiring-guide.md) for detailed wiring instructions for the panel-mounted switches.

---

## Electrical checks

> [!WARNING]
> Never install the Raspberry Pi Pico or any socketed ICs until the power supply has been verified and the board has been inspected for shorts.

Before applying power:

* Check resistance between 5 V and GND.
* Check resistance between 3.3 V and GND.
* Inspect for solder bridges.
* Confirm regulator orientation.
* Confirm BAT54S orientation.
* Ensure no loose solder or debris remains.

> [!TIP]
> Spending a few minutes checking the board before power-up can prevent hours of fault finding later.

---

## USB Connection Options

ext cable

*Figure 11. USB Extension Cable.*

> [TIP]
> IIf you do not wish to fit the internal USB extension cable, a standard 1 metre USB-C cable can be routed through the rear cable slot instead.

Connect the short USB extension cable to the RP2040 and route it alongside the DC power jack.

route usb

*Figure 12. Usb from RP2040.*

Route the connector through the rear slot in the enclosure next to the 5 V DC power jack.

Boards assembled

*Figure 13. Back of Case with USB and DC.*

---

## First power-up

Connect the tester to a USB power source.

The tester will automatically perform the **Power-On Self Test (POST)**.

Expected sequence:

1. OLED initialises.
2. POST begins.
3. Hardware checks complete.
4. Main menu appears.
5. Main menu displayed.
6. Ready for testing.

A successful Power-On Self Test (POST) is shown in Figure 11.

POST screen

*Figure 11. successful (POST) screen.*

If POST reports an error, refer to the **Troubleshooting Guide** before continuing.

---

## Initial functional check

Verify the following operate correctly:

* OLED display
* Rotary encoder
* TEST button
* Package selector
* DUT voltage selector

Figure 12 shows the Main Menu after a successful startup.

Main menu

*Figure 12. main menu after startup.*

A successful functional test is shown in Figure 13.

PASS result

*Figure 13. successful pass result.*

The tester is now ready for its first functional IC test. Continue with the Usage Guide to begin testing supported 74xx-series logic devices.

---

## Next Steps

Your hardware is assembled. Continue with the Firmware Guide to install the latest firmware.

Continue with the following guides to install the firmware, learn how to operate the tester, and explore its supported features.

## Related Documentation

| Document | Description |
|---|---|
| [🏠 Project Home](../../README.md) | Return to the main project page |
| [📖 Documentation Index](../README.md) | Browse all project documentation |
| [🚀 Getting Started](getting-started.md) | First-time setup |
| **🔧 Build Guide** | **You are here** |
| [💾 Firmware Guide](firmware-guide.md) | Installing and updating the firmware |
| [▶️ Usage Guide](usage-guide.md) | Operating the tester |
| [🧩 Supported ICs](supported-ics.md) | List of supported logic devices |
| [🛠 Troubleshooting Guide](troubleshooting-guide.md) | Diagnose common hardware and firmware issues |

---

| ← Previous | Next → |
|---|---|
| [🚀 Getting Started](getting-started.md) | [💾 Firmware Guide](firmware-guide.md) |

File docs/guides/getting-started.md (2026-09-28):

# Getting Started

Completed OD-PT74

Welcome to the **OD-PT74 Pico 74xx IC Tester**.

This guide will help you assemble the hardware, install the firmware, and perform your first IC test. This guide assumes you are using the Rev-C hardware PCB and firmware v1.0.0.

For more detailed information, see the additional guides in the documentation.

---

## Before you begin

You will need:

* Rev-C PCB set
* Raspberry Pi Pico 2 (RP2040)
* All components listed in the Bill of Materials (BOM)
* USB cable
* Computer with USB support
* Soldering equipment
* Small hand tools

Basic electronics assembly experience is recommended.

---

## Step 1 – Assemble the hardware

Populate both PCBs according to the Build Guide.

During assembly:

* Install low-profile components first.
* Observe the polarity of all diodes, electrolytic capacitors and LEDs.
* Fit all IC sockets before installing integrated circuits.
* Carefully inspect every solder joint before applying power.

When assembly is complete, perform a visual inspection to check for:

* solder bridges
* dry joints
* incorrect component values
* reversed polarised components
* bent connector pins

Refer to the **Build Guide** for detailed assembly instructions.

---

## Step 2 – Install the firmware

Install the supported version of MicroPython onto the Raspberry Pi Pico 2, then copy the OD-PT74 firmware files to the board.

Copy the project firmware to the Pico by following the Firmware Guide.

Refer to the firmware installation instructions if you are unfamiliar with installing MicroPython.

---

## Step 3 – Power up

Connect the Pico to your computer using a USB cable.

On first power-up the tester automatically performs a **Power-On Self Test (POST)**.

During POST the tester verifies:

* OLED display
* MCP23017 communication
* I²C bus
* Package selector
* DUT voltage selector
* TEST button

If all checks pass, the main menu is displayed.

If a fault is detected, the tester displays an error message describing the failed test.

---

## Step 4 – Configure the tester

Before testing an IC:

1. Select the correct package size.
2. Select the required DUT supply voltage.
3. Confirm the ZIF socket is empty.

The tester is now ready for use.

---

## Step 5 – Perform your first test

A 74LS00 or 74HC00 quad NAND gate is recommended for your first test because these devices are widely available and easy to verify.

1. Set the DUT voltage selector to OFF.
2. Open the ZIF socket.
3. Insert the IC with Pin 1 correctly oriented.
4. Close the ZIF socket.
5. Select the package size (14, 16 or 20 pins).
6. Select the DUT voltage (3.3 V or 5 V).
7. Select the device family and IC from the menu.
8. Press **TEST**.
9. Review the test results displayed on the OLED.

If the device passes, your tester is operating correctly.

---

## Safety notes

> [!IMPORTANT]
>
> Always move the DUT voltage selector to OFF before inserting or removing an IC.

> [!IMPORTANT]
>
> Never insert or remove an IC while a test is in progress.

> [!WARNING]
>
> Verify the orientation of every device before closing the ZIF socket.

> [!WARNING]
>
> The tester is designed for supported 74xx-series logic devices only. Do not connect external circuitry to the DUT socket while testing.

---

Congratulations! Your **OD-PT74 Pico 74xx IC Tester** is now ready to test supported 74xx-series logic ICs.

We hope you enjoy using it, and we welcome bug reports, hardware feedback, and contributions to expand the supported IC library.

---

---

## Next Steps

Now that your OD-PT74 is assembled and running, continue with the Build Guide for detailed assembly information and optional enhancements.

## Related Documentation

| Document | Description |
|---|---|
| [🏠 Project Home](../../README.md) | Return to the main project page |
| [📖 Documentation Index](../README.md) | Browse all project documentation |
| **🚀 Getting Started** | **You are here** |
| [🔧 Build Guide](build-guide.md) | Complete hardware assembly instructions |
| [💾 Firmware Guide](firmware-guide.md) | Installing and updating the firmware |
| [▶️ Usage Guide](usage-guide.md) | Operating the tester |
| [🧩 Supported ICs](supported-ics.md) | List of supported logic devices |
| [🛠 Troubleshooting Guide](troubleshooting-guide.md) | Diagnose common hardware and firmware issues |

---

| ← Previous | Next → |
|---|---|
| [🏠 Project Home](../../README.md) | [🔧 Build Guide](build-guide.md) |

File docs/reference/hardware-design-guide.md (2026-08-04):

# Hardware Design Guide

## Introduction

This document describes the hardware architecture and design philosophy of the **OD-PT74 Pico 74xx Logic IC Tester**.

Rather than focusing on assembly or operation, this guide explains the engineering decisions behind the hardware and the major subsystems that make up the tester.

The OD-PT74 Pico 74xx Logic IC Tester was designed as a dedicated bench instrument for the functional verification of standard 74xx-series logic ICs. The design prioritises reliability, repeatability, ease of construction, and long-term maintainability.

---

| Item | Specification |
| --- | --- |
| MCU | RP2040 |
| I/O Expander | MCP23017 |
| Display | 128×64 SSD1306 OLED  |
| DUT Packages | 14 / 16 / 20-pin DIP |
| DUT Voltage  | 3.3 V / OFF / 5 V |
| Firmware | MicroPython |

---

## Design objectives

The primary design objectives of the OD-PT74 are:

* Reliable bench operation
* Simple construction using readily available components
* Modular hardware architecture
* Easy firmware development
* Low component count where practical
* Straightforward fault finding
* Expandable firmware support
* Robust operation during normal bench use

Every major hardware decision was made with these objectives in mind.

---

## System architecture

The tester is built around the Raspberry Pi Pico (RP2040) microcontroller and a dedicated hardware platform designed specifically for functional testing of standard logic ICs.

Major hardware subsystems include:

* Raspberry Pi Pico (RP2040)
* MCP23017 I²C GPIO expander
* 20-pin ZIF socket
* OLED display
* Rotary encoder
* TEST and NEXT push buttons
* RGB status LED
* Audible buzzer
* DUT voltage selection
* Package selection
* Independent 5 V and 3.3 V power status LEDs

The relationship between the major hardware subsystems is illustrated in Figure 1.

System architecture

*Figure 1. OD-PT74 system architecture.*

---

## Raspberry Pi Pico

The Raspberry Pi Pico was selected because it provides an excellent balance of performance, flexibility, and cost.

Advantages include:

* RP2040 dual-core microcontroller
* Large number of GPIO pins
* Native USB support
* Excellent MicroPython support
* Widely available
* Well documented
* Strong community support

The Pico performs all user interface, device control, and test sequencing functions.

---

## MCP23017 I/O Expander

The MCP23017 significantly increases the number of available GPIO pins using the I²C bus.

This provides several advantages:

* Simplifies PCB routing
* Reduces wiring complexity
* Frees RP2040 GPIO pins
* Provides additional digital I/O for IC testing

Using the MCP23017 also allows the firmware to remain modular and simplifies future expansion.

Figure 2 illustrates how the RP2040 communicates with the MCP23017 and OLED display over the I²C bus.

I²C Communications Architecture

*Figure 2. I²C Communication Architecture of the OD-PT74 Pico 74xx Logic IC Tester.*

---

## Power system

The OD-PT74 Pico 74xx Logic IC Tester is powered from a standard 5 V USB supply.

An onboard voltage regulator generates the 3.3 V rail required by the RP2040, MCP23017, and OLED display.

The DUT supply voltage is selectable:

* OFF
* 3.3 V
* 5 V

This allows the tester to support both modern CMOS devices and traditional TTL logic families.

The power supply section is assembled and verified before the remainder of the board to simplify fault finding during construction.

Figure 2 shows the distribution of the 5 V and 3.3 V power rails throughout the tester.

Power architecture

*Figure 2. Power architecture of the OD-PT74 Pico 74xx Logic IC Tester.*

---

## Device Under Test (DUT) interface

The DUT interface has been designed for simplicity and reliability.

Features include:

* 20-pin ZIF socket
* Package selection
* DUT voltage selection
* GPIO protection resistors
* Clamp diode protection
* Clearly marked pin orientation

The tester supports:

* 14-pin DIP
* 16-pin DIP
* 20-pin DIP

using conventional 74xx-series power pin arrangements.

Figure 3 shows the signal path from the MCP23017 through the ZIF driver circuitry to the Device Under Test (DUT).

DUT Interface Architecture

*Figure 3. DUT interface architecture of the OD-PT74 Pico 74xx Logic IC Tester.*

---

## User interface

The tester is operated using:

* Rotary encoder
* TEST button
* NEXT button
* 128 × 64 OLED display
* RGB status LED
* Audible buzzer

This combination provides a straightforward user experience while keeping the front panel uncluttered.

---

## Hardware protection

Several protection features have been incorporated into the design.

These include:

* GPIO series resistors
* Clamp diode protection
* Controlled DUT voltage switching
* Regulated power supply

These measures improve the robustness of the tester during normal operation but do not eliminate the need for good handling practices.

> [!WARNING]
> The tester is designed for supported 74xx-series logic ICs only. It is not intended to be connected directly to external circuits while testing.

---

## Design philosophy

The OD-PT74 Pico 74xx Logic IC Tester is a dedicated bench instrument rather than a general-purpose development platform.

The design intentionally favours:

* Simplicity
* Reliability
* Repeatability
* Ease of construction
* Ease of maintenance

Rather than supporting every possible logic device, the OD-PT74 focuses on the most commonly encountered 74xx-series logic ICs used in electronics repair, education, and hobby projects.

This focused approach results in a tester that is straightforward to build, easy to use, and highly reliable in everyday bench use.

---

## Design limitations

The following limitations are intentional design decisions:

* Supports standard 14-, 16-, and 20-pin DIP packages.
* Supports conventional 74xx-series power pin arrangements.
* Performs functional verification only.
* Does not perform analogue measurements.
* Does not measure propagation delay.
* Does not characterise device performance.
* Does not support adapter-based devices.

These limitations help keep the hardware simple while providing comprehensive functional testing for the majority of commonly encountered logic ICs.

---

## Firmware interaction

The hardware has been designed to work closely with the modular firmware architecture.

Hardware-specific drivers are separated from the test engine and IC definitions, allowing new devices to be added with minimal impact on the core firmware.

This modular approach simplifies maintenance and future firmware enhancements.

The overall firmware structure is illustrated in Figure 4.

Firmware architecture

*Figure 4. Firmware architecture of the OD-PT74 Pico 74xx Logic IC Tester.*

---

## Summary

The OD-PT74 Pico 74xx Logic IC Tester combines a purpose-designed hardware platform with modular MicroPython firmware to provide a reliable and easy-to-use instrument for testing standard 74xx-series logic ICs.

Every major design decision reflects the project's primary objective: delivering a practical, dependable bench instrument that is straightforward to build, maintain, and use.

## Related Documentation

| Document | Description |
|---|---|
| [🏠 Project Home](../../README.md) | Return to the main project page |
| [📖 Documentation Index](../README.md) | Documentation overview |

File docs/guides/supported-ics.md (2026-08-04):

# Supported ICs

## Introduction

This document lists the logic ICs currently supported by the **OD-PT74 Pico 74xx Logic IC Tester**.

Each device listed has either been validated on physical Rev-C hardware or is included in the firmware awaiting hardware verification.

The Rev-C hardware platform focuses on standard **74xx-series logic ICs** in **14-pin, 16-pin, and 20-pin DIP packages** using conventional power pin arrangements.

---

## Validation summary

**Current Release

Firmware: v1.0.0
Hardware: Rev-C

> [!NOTE]
> **Validation Summary**
>
> - Supported packages: **14-, 16- and 20-pin DIP**
> - Supported families: **74LS, 74HC, 74HCT and selected 74LVC**
> - Verified devices: **48**
> - Pending validation: **10**

### Supported package sizes

* 14-pin DIP
* 16-pin DIP
* 20-pin DIP

### Supported logic families

* 74LS
* 74HC
* 74HCT
* Selected 74LVC devices operating at 3.3 V

### Validation status

- ✅ Physical hardware validation
- 🧪 Firmware implementation awaiting validation
- 📋 Outside the scope of the OD-PT74

---

## Validation levels

| Status | Description |
| --- | --- |
| ✅ **Verified** | Successfully tested on physical Rev-C hardware. |
| ⚠ **Failed** | Physical device tested but failed functional verification. |
| 🧪 **Pending Validation** | Firmware support exists but physical validation has not yet been completed. |
| 📦 Not Yet Tested (No Sample Available)| Firmware support exists but a suitable device was not available for testing. |
| 🚫 Not Supported | Outside the design scope of the OD-PT74. |

A device is considered **Verified** only after successful testing on physical Rev-C hardware PCB using one or more of the available test modes (Quick, Full, and Soak, where appropriate).

---

## Verified Devices

The following devices have been successfully validated on physical Rev-C hardware PCB.

## 14-pin Devices

| IC | Function | Status | 
| --- | --- | --- |
| 74HC00  | Quad 2-input NAND | ✅ | 
| 74LS00  | Quad 2-input NAND | ✅ | 
| 74HC02  | Quad 2-input NOR | ✅ | 
| 74LS02  | Quad 2-input NOR | ✅ | 
| 74HC03  | Quad 2-input NAND OC | ✅ | 
| 74LS04  | Hex inverter | ✅ | 
| 74HC05  | Hex inverter OC | ✅ |
| 74HC06  | Hex inverter / driver OC | ✅ | 
| 74LS06  | Hex inverter / driver OC | ✅ | 
| 74HC07  | Hex buffer / driver OC | ✅ | 
| 74LS07  | Hex buffer / driver OC | ✅ | 
| 74HC08  | Quad 2-input AND | ✅ | 
| 74HC10  | Triple 3-input NAND | ✅ | 
| 74LS11  | Triple 3-input AND | ✅ | 
| 74HC14  | Hex Schmitt inverter | ✅ | 
| 74HC21  | Dual 4-input AND | ✅ | 
| 74LS27  | Triple 3-input NOR | ✅ | 
| 74HC30  | 8-input NAND | ✅ | 
| 74HC32  | Quad 2-input OR | ✅ | 
| 74LS32  | Quad 2-input OR | ✅ | 
| 74LS74  | Dual D flip-flop | ✅ | 
| 74LS86  | Quad 2-input XOR | ✅ | 
| 74HC125 | Quad tri-state buffer | ✅ | 
| 74HC126 | Quad tri-state buffer | ✅ | 
| 74HC132 | Quad Schmitt NAND | ✅ | 
| 74HC164 | 8-bit shift register | ✅ | 
| 74HC393 | Dual binary counter | ✅ | 

---

## 16-pin Devices

| IC | Function | Status |
| --- | --- | --- |
| 74LS85  | 4-bit magnitude comparator | ✅ | 
| 74HC138 | 3-to-8 decoder | ✅ | 
| 74HC139 | Dual 2-to-4 decoder | ✅ | 
| 74LS139 | Dual 2-to-4 decoder | ✅ | 
| 74LS151 | 8-input digital multiplexer | ✅ |
| 74LS153 | Dual 4-input multiplexer | ✅ | 
| 74LS157 | Quad 2:1 multiplexer | ✅ |
| 74LS161 | 4-bit synchronous binary counter | ✅ | 
| 74HC163 | 4-bit counter | ✅ | 
| 74HC165 | 8-bit PISO shift register | ✅ | 
| 74HC174 | Hex D flip-flop | ✅ | 
| 74LS194 | 4-bit bidirectional shift register | ✅ | 
| 74HC595 | Serial-in parallel-out shift register | ✅ | 

---

## 20-pin Devices

| IC | Function | Status | 
| --- | --- | --- |
| 74HC244 | Octal buffer | ✅ | 
| 74HC245 | Octal bus transceiver | ✅ | 
| 74HC273 | Octal D flip-flop | ✅ | 
| 74HC373 | Octal latch | ✅ | 
| 74HC374 | Octal D flip-flop | ✅ | 
| 74HC573 | Octal latch | ✅ |
| 74HC574 | Octal D flip-flop | ✅ | 

---

## 74LVC Devices

> [!IMPORTANT]
> All **74LVC** devices must be tested with the DUT voltage selector set to **3.3 V**.

| IC | Function | Status | Notes |
| --- | --- | --- | --- |
| 74LVC245 | Octal bus transceiver | ✅ | Clean legs required |

---

# Pending Validation

The following devices are implemented in firmware but have not yet been validated on physical hardware.

| IC | Function | Status |
| --- | --- | --- |
| 74HC04  | Hex inverter | 📦 Not tested |
| 74HC11  | Triple 3-input AND | 📦 Not tested |
| 74HC27  | Triple 3-input NOR | 📦 Not tested |
| 74HC74  | Dual D flip-flop | 📦 Not tested |
| 74HC86  | Quad 2-input XOR | 📦 Not tested |
| 74HC151 | 8-input multiplexer  | 📦 Not tested |
| 74HC153 | Dual 4-input mux | 📦 Not tested |
| 74HC157 | Quad 2:1 multiplexer | 📦 Not tested |
| 74HC161 | 4-bit counter | 📦 Not tested |
| 74HC194 | Shift register | 📦 Not tested |

---

# Notes on 74LVC devices

74LVC devices operate at **3.3 V** and require the tester's DUT voltage selector to be set accordingly.

Because of their lower operating voltage, poor socket contact or tarnished IC pins may cause intermittent failures during extended testing.

The tester can verify:

* Logic functionality
* Output enable operation
* Tri-state behaviour
* Bus transceiver direction control
* Input and output operation
* Stuck-high and stuck-low faults

The tester performs **functional verification only**.

It does **not** measure:

* Propagation delay
* Maximum operating frequency
* Output drive capability
* Leakage current
* Full datasheet compliance

---

# How devices are verified

Before an IC is added to the **Verified** list, it is tested on physical Rev-C hardware PCB.

Validation normally includes:

* Correct device identification
* Quick Test
* Full Functional Test
* Soak Test (where applicable)
* Verification using known-good devices
* Confirmation that the observed behaviour matches the expected logic function

Firmware implementation alone does not qualify a device as **Verified**.

---

# Community contributions

Additional IC definitions and validation results are always welcome.

When submitting a new device, please include:

* IC part number
* Logic family
* Package type
* Test definition source code
* Pin mapping
* Hardware revision used
* Quick Test results
* Full Test results
* Soak Test results (if performed)
* Any known limitations or observations

Community contributions help expand the supported IC library and increase confidence in the validation process.

---

# Project scope

The OD-PT74 Pico 74xx Logic IC Tester is designed to test the most commonly encountered 74xx-series logic ICs using standard 14-pin, 16-pin and 20-pin DIP packages.

Devices requiring non-standard power connections, adapter boards, specialised timing analysis, analogue measurements or additional hardware are outside the design scope of this project.

As additional IC definitions are developed and verified, this guide will continue to expand with future firmware releases.

---

## Next Steps

You now have an overview of the logic devices currently supported by the **OD-PT74 Pico 74xx Logic IC Tester**.

As additional IC definitions are developed and verified, this guide will continue to expand with future firmware releases.

If you encounter unexpected behaviour while testing a supported device, refer to the **Troubleshooting Guide** for diagnostic procedures and common solutions.

## Related Documentation

| Document | Description |
|---|---|
| [🏠 Project Home](../../README.md) | Return to the main project page |
| [📖 Documentation Index](../README.md) | Browse all project documentation |
| [🚀 Getting Started](getting-started.md) | First-time setup |
| [🔧 Build Guide](build-guide.md) | Hardware assembly |
| [💾 Firmware Guide](firmware-guide.md) | Installing and updating the firmware |
| [▶️ Usage Guide](usage-guide.md) | Operating the tester |
| **🧩 Supported ICs** | **You are here** |
| [🛠 Troubleshooting Guide](troubleshooting-guide.md) | Diagnose common hardware and firmware issues |

---

| ← Previous | Next → |
|---|---|
| [▶️ Usage Guide](usage-guide.md) | [🛠 Troubleshooting Guide](troubleshooting-guide.md) |

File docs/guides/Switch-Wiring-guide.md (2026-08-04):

# Front Panel Switch Wiring Guide

switches

*Figure 1 - The Installed Switches On Base board.*

The OD-PT74 uses three off-board switches mounted in the front panel.

These switches are connected to the PCB using pre-made wiring harnesses. This guide explains the function of each switch and how each connector should be wired.

---

## Power Switch

power switch

*Figure 2 - The Main 5v DC Power Switch.*

This switch connects and disconnects the external DC input to the tester.

### Wiring the Power ON/OFF Switch

The power switch is a standard SPST ON/OFF switch and is not polarised, so either wire may be connected to either terminal.

Check the switch orientation before installing it into the top case.

The 2 wires go on the 2 outside pins of the 3 pin plug.

power socket

*Figure 3 - The Main 5v DC Power Switch headder.*

---

## IC Power / Sense

Selects the operating voltage for the IC under test and the voltage rail monitored by the tester.

power socket

*Figure 4 - The IC Power and Sense Switch.*

This switch handles 2 important jobs in the tester and it is a DPDT switch.

The switch has 3 positions because when changing IC voltage you need to remove the power before you select the next voltage or you very well could spike the IC, MCU or RP2040.

The switch is divided in to 2 separate functions.

1. first side of the switch - IC Voltage Select:

Wiring Diagram

Left Terminal Pin1  → 5 V

Centre Terminal pin2  → Common

Right Terminal pin3  → 3.3 V

Operation

Switch Position	Result

Up	5 V
Centre	OFF
Down	3.3 V

2. second side of the switch pin-1 to 5v sense / pin-2 to ground / pin-3 to 3.3v sense. 

Wiring Diagram

Left Terminal Pin1  → 5 V sense to MCP

Centre Terminal pin2  → Selected Voltage

Right Terminal pin3  → 3.3 V to MCP

Operation

Switch Position	Result

Up	5 V sense
Centre	OFF
Down	3.3 V sense

power socket

*Figure 5 - selector switch-header sockets.*

>Tip: Use different coloured wires where possible. This makes identifying each connector much easier during assembly and troubleshooting.

---

## IC Package Select Switch

package selector switch

*Figure 6 - IC Package Select Switch.*

This switch is a very important one as it selects the type of IC package you are going to test.

The Package selector switch is a 3 Pole by 4 position rotary switch and is divided into 3 jobs.

*Centre Pin-A = Ground Pin for ZIF:*

Centre Pin-A  →  Pin 1 OFF
	      →  Pin 2 - pin 7 on ZIF.
	      →  Pin 3 - pin 8 on ZIF.
              →  Pin 4 - pin 10 on ZIF.

*Centre Pin-B = Ground for Package sence:*

Centre Pin-B  →  Pin 1 OFF
	      →  Pin 2 Package sence 14.
	      →  Pin 3 Package sence 16.
              →  Pin 4 Package sence 20.

*Centre Pin-C = Voltage in for ZIF*

Centre Pin-C  →  Pin 1 OFF
	      →  Pin 2 Voltage pin 20 ZIF.
	      →  Pin 3 Voltage pin 20 ZIF.
              →  Pin 4 Voltage pin 20 ZIF.

package selector switch

*Figure 7 - IC Package Select Switch.*

*Header Plug Pin out*
 
	     Pin 1 →  Pin C Voltage in
	     Pin 2 →  Pin 12/11/10 Voltage to pin 20 ZIF.
	     Pin 3 →  Pin 4 Ground pin 10 ZIF.
             Pin 4 →  Pin B Ground sence pin.
	     Pin 5 →  Pin 3 Ground pin 8 ZIF.
	     Pin 6 →  Pin 6 sence 14 return.
	     Pin 7 →  Pin 2 Ground pin 7 ZIF.
	     Pin 8 →  Pin 7 sence 16 return.
             Pin 9 →  Pin A Ground in for ZIF.
	     Pin 10 →  Pin 8 sence 20 return.

package selector Header

*Figure 8 - Package Select Board Header KiCad.*

package selector Header2

*Figure 9 - Package Select Board Header.*

---
## Related Documentation

| Document | Description |
|---|---|
| [🏠 Project Home](../../README.md) | Return to the main project page |
| [📖 Documentation Index](../README.md) | Documentation overview |

| ← Previous | Next → |
|---|---|
| [🔧 Build Guide](build-guide.md) | [💾 Firmware Guide](firmware-guide.md) |

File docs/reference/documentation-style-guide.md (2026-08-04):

Author:
David-k Otter

Project:
OD-PT74 Pico 74xx Logic IC Tester

Documentation Standard:
Version 1.0

# Documentation Style Guide

## Purpose

This document defines the documentation standards used throughout the OD-PT74 repository.

Following a consistent style improves readability, simplifies maintenance, and provides a professional experience for users and contributors.

---

# General Principles

Documentation should be:

- Clear
- Accurate
- Concise
- Consistent
- Friendly
- Technically correct

Assume the reader has basic electronics knowledge but may be unfamiliar with the project.

---

# Document Structure

Where appropriate, documents should follow this structure:

1. Introduction
2. Before You Begin
3. Main Content
4. Notes or Warnings
5. Next Steps

Not every document requires every section, but the overall structure should remain consistent.

---

# Heading Levels

Use Markdown headings consistently.

```text
# Document Title

## Major Section

### Subsection

#### Minor Subsection
```

Only one H1 heading should appear in each document.

---

# File Naming

Use lowercase filenames with hyphens.

Examples:

build-guide.md

usage-guide.md

supported-ics.md

hardware-design-guide.md

Do not use spaces or mixed capitalisation.

---

# Image Naming

Images should use descriptive filenames.

Examples:

figure-01-system-architecture.svg

01-power-supply.jpg

08-post-screen.jpg

Avoid generic names such as:

image1.png

diagram-new.svg

test.jpg

---

# Figure Captions

Use the following format:

Figure 1. Hardware architecture.

Figure 2. Power system.

Do not abbreviate "Figure".

---

# Callouts

Use GitHub Markdown callouts consistently.

NOTE

General information.

TIP

Helpful advice.

IMPORTANT

Information that should not be overlooked.

WARNING

Potential risk or damage.

---

# Terminology

Always use the following project terminology:

Power-On Self Test (POST)

Device Under Test (DUT)

Raspberry Pi Pico

OD-PT74 Pico 74xx Logic IC Tester

Quick Test

Full Test

Soak Test

Avoid introducing alternative names for the same feature.

---

Always use the following names consistently:

Product:
OD-PT74

Full Product Name:
OD-PT74 Pico 74xx Logic IC Tester

Company:
Otter Designs

Hardware:
Rev-C

Firmware:
v1.0.0

---

# Language

Use British English throughout.

Examples:

colour

centre

organisation

initialise

behaviour

maintainable

---

# Writing Style

Prefer:

Short paragraphs

Active voice

Simple language

Consistent terminology

Avoid:

Long paragraphs

Unnecessary repetition

Marketing language

Humour in technical documentation

---

# Lists

Use bullet lists for related items.

Use numbered lists only when order matters.

---

# Tables

Use tables for:

Specifications

Supported ICs

Comparison data

Pin assignments

Avoid using tables for long explanations.

---

# Diagrams

Engineering diagrams should be created as SVG files.

Source files should be stored in:

graphics/source/

Exported PNG files used by the documentation should be stored in:

graphics/exports/

Always edit the SVG source file and regenerate the PNG export. Do not edit exported PNG files directly.

---

# Photos

Use:

Consistent lighting

Neutral background

Square alignment

High resolution

Minimal editing

---

# Versioning

Documentation should match the current project release.

Current release

Hardware: Rev-C
Firmware: v1.0.0

---

# Cross References

Where appropriate, documents should link to related guides.

For example:

Build Guide

Usage Guide

Troubleshooting Guide

Supported ICs

Project Overview

---

# Repository Philosophy

The OD-PT74 repository documents the OD-PT74 Pico 74xx Logic IC Tester. Future Otter Designs projects, such as the OD-ADU, maintain their own documentation and repositories.

Documentation should describe the current hardware and firmware.

Future projects should maintain their own documentation repositories.

Good documentation should enable a first-time builder to assemble, verify and use the OD-PT74 Pico 74xx Logic IC Tester with confidence, while providing sufficient technical detail for future maintenance and community contributions.

## Related Documentation

| Document | Description |
|---|---|
| [🏠 Project Home](../../README.md) | Return to the main project page |
| [📖 Documentation Index](../README.md) | Documentation overview |

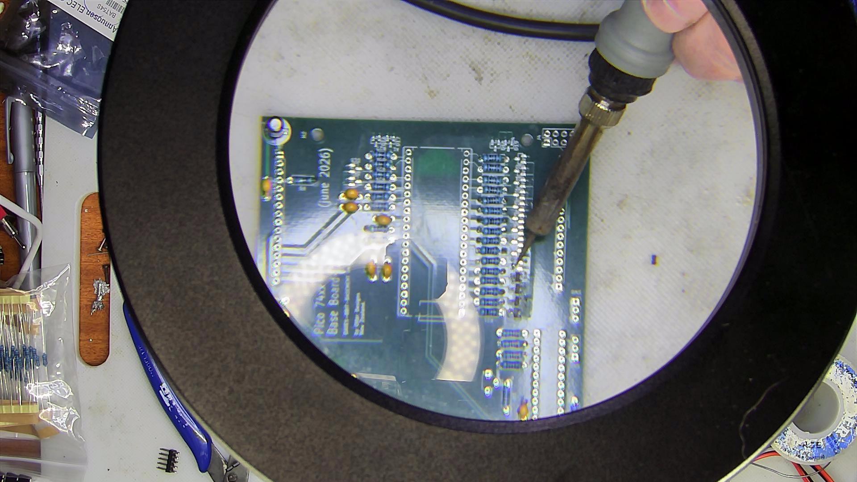
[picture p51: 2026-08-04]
docs/images/build/12-bat-attach-1-pin.jpg

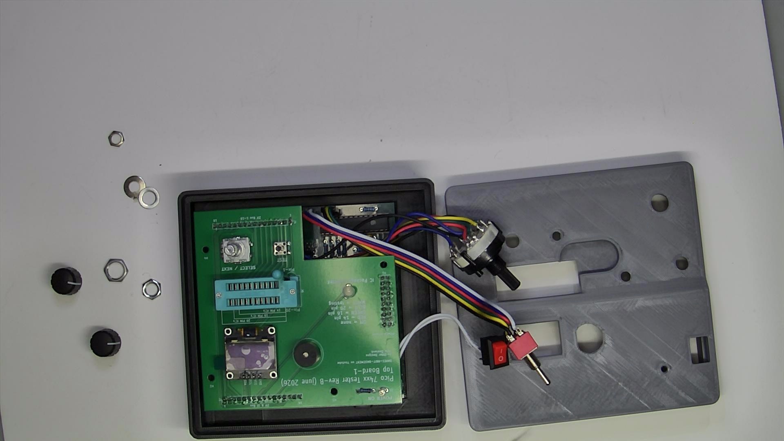
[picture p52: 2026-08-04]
docs/images/build/51-board-stack-in-case.jpg

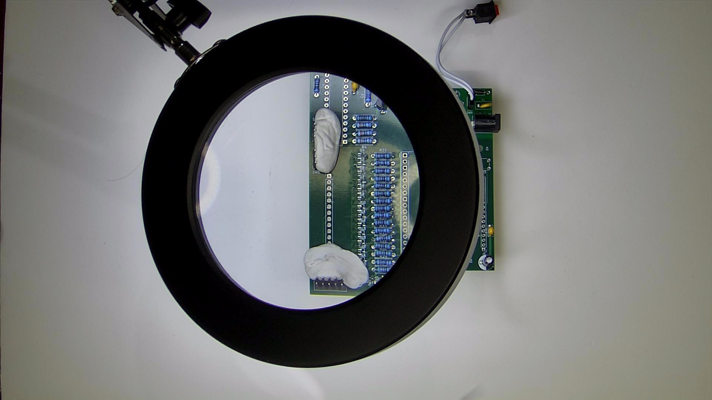
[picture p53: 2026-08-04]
docs/images/build/07-attach-header-2.jpg

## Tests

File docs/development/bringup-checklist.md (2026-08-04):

# Bring-up Checklist

## Before installing socketed devices

- [ ] Inspect PCB for shorts or solder bridges
- [ ] Check 3.3V to GND resistance
- [ ] Check 5V to GND resistance
- [ ] Check V_OUT to GND resistance
- [ ] Confirm Pico orientation
- [ ] Confirm MCP23017 orientation
- [ ] Confirm transistor pinout
- [ ] Confirm ZIF socket orientation
- [ ] Confirm voltage selector switch orientation
- [ ] Confirm package selector switch orientation

## First power-on

- [ ] Power from USB only
- [ ] Confirm Pico boots
- [ ] Confirm 3.3V rail
- [ ] Confirm 5V/VBUS rail
- [ ] Confirm MCP23017 detected
- [ ] Confirm OLED detected if fitted
- [ ] Confirm buttons work
- [ ] Confirm RGB LED works
- [ ] Confirm buzzer works
- [ ] Confirm 5 V power LED
- [ ] Confirm 3.3 V power LED
- [ ] Confirm rotary encoder operation

## Switch tests

- [ ] Package switch reads 14-pin
- [ ] Package switch reads 16-pin
- [ ] Package switch reads 20-pin
- [ ] Voltage switch reads 3.3V
- [ ] Voltage switch reads OFF
- [ ] Voltage switch reads 5V

## Socket power tests

With no IC inserted:

- [ ] 14-pin mode: V_OUT appears on ZIF pin 20
- [ ] 14-pin mode: GND appears on ZIF pin 7
- [ ] 16-pin mode: V_OUT appears on ZIF pin 20
- [ ] 16-pin mode: GND appears on ZIF pin 8
- [ ] 20-pin mode: V_OUT appears on ZIF pin 20
- [ ] 20-pin mode: GND appears on ZIF pin 10

## First IC test

- [ ] Test known-good 74HC00 at 3.3V
- [ ] Test known-good 74HC04 at 3.3V
- [ ] Test known-good 74LS00 at 5V

## Final Verification

- [ ] POST completes with no errors
- [ ] Main menu displayed
- [ ] Known-good IC passes Quick Test
- [ ] Known-good IC passes Full Test
- [ ] Soak Test runs successfully

## Related Documentation

| Document | Description |
|---|---|
| [🏠 Project Home](../../README.md) | Return to the main project page |
| [📖 Documentation Index](../README.md) | Documentation overview |

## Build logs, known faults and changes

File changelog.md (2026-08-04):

# Changelog

All notable changes to the Pico 74xx IC Tester project are documented in this file.

The project follows a hardware revision (Rev-A, Rev-B, etc.) combined with semantic firmware versioning for public releases.

---

## Rev-C v1.0.0 — Initial Public Release

### Highlights

* First public release of the Rev-B hardware platform
* Stable MicroPython firmware
* Production enclosure completed
* Comprehensive project documentation
* Open-source hardware and firmware published on GitHub

v1.0.0
-------
• First public release.
• Hardware Rev-C.
• Firmware v1.0.

### Added

#### Hardware

Rev-C Hardware
--------------
• BAT54S footprint corrected.
• SDA/SCL routing corrected.
• Two power LEDs.
• Piezo 3.3 V / 5 V links.
• Enclosure updated.
• Front panel updated.

Rev-B Hardware
--------------
* Rev-B PCB.s
* Raspberry Pi Pico (RP2040) controller
* MCP23017 I/O expander
* 20-pin ZIF socket
* 14-, 16- and 20-pin package support
* SSD1306 OLED display
* Rotary encoder navigation
* TEST and NEXT push buttons
* RGB status LED
* Audible buzzer
* 3.3 V / OFF / 5 V DUT power selection

#### Firmware

* Power-On Self Test (POST)
* Interactive menu system
* Automatic package detection
* DUT voltage detection
* Quick Test mode
* Full Functional Test mode
* Soak Test modes

  * 50 cycles
  * 500 cycles
  * Continuous
* OLED diagnostic messages
* USB serial diagnostics
* Modular IC definition library

### Improved

* Overall firmware stability
* Hardware diagnostics
* User interface responsiveness
* IC test framework
* Documentation and project structure

### Fixed

* 7403 open-collector NAND testing
* 74139 decoder verification
* 74163 counter verification
* 7414 inverter timing behaviour
* TEST button startup handling
* Package mismatch detection

### Validation

The following hardware functions have been verified:

* OLED display
* MCP23017 communication
* I²C bus
* Package detection
* DUT voltage selection
* Rotary encoder
* Quick Test mode
* Full Test mode
* Soak Test modes

Multiple 74LS devices have been validated on production Rev-B hardware using Quick, Full and Soak testing.

---

## Rev-A Development

Rev-A served as the proof-of-concept platform used during initial hardware and firmware development.

### Hardware

* Initial RP2040 platform
* MCP23017 interface
* OLED support
* Rotary encoder
* RGB LED
* Buzzer
* 20-pin ZIF socket

### Firmware

* Initial menu system
* Interactive IC selection
* Package detection
* Initial 74xx device library

### Validation

Early validation covered representative devices including:

* Logic gates
* Decoders
* Counters
* Registers
* Latches
* Shift registers

Rev-A successfully validated the overall hardware architecture and provided the foundation for the Rev-B production design.

Rev-B
Corrected BAT54S clamp-diode rail connections. Original layout connected pin 1 to +3.3 V and pin 2 to GND, 
causing excessive current draw and collapse of the 3.3 V rail. Correct wiring is pin 1 to GND, pin 2 to +3.3 V, 
and pin 3 to the protected GPIO.

Rev-B PCB:
- MCP23017 SDA/SCL swapped.
- Correct by swapping MCP pins 12 and 13 (or PCB tracks).

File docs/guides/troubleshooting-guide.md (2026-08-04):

# Troubleshooting Guide

## Introduction

This guide provides practical troubleshooting information for the **OD-PT74 Pico 74xx IC Tester**.

Most problems can be resolved by following the recommended diagnostic steps in this guide. Work through each section in order, beginning with the power supply and progressing through the hardware and firmware checks.

> [!TIP]
>
> Do not assume the IC under test is faulty. Always verify the tester is operating correctly before diagnosing the device.

---

## Before you begin

Before troubleshooting, ensure:

* The hardware has been assembled according to the **Build Guide**.
* Firmware v1.0.0 (or later) is installed.
* The Raspberry Pi Pico is correctly seated.
* The tester is powered from a stable 5 V DC supply or Stable 5 V USB power source..

Have the following available:

* Digital multimeter
* Known-good 74LS00 or 74HC00
* USB cable
* Magnifying glass or inspection lamp

---

## Power problems

### Symptom

The tester does not power on.

### Possible causes

* No USB power
* Incorrectly fitted voltage regulator
* Incorrect BAT54S orientation
* Short circuit on the PCB
* Faulty USB cable

### Checks

* Verify 5 V at the DC input.
* Verify 3.3 V regulator output.
* Inspect for solder bridges.
* Check regulator orientation.
* Confirm BAT54S orientation.

> [!IMPORTANT]
>
> Do not continue until both the 5 V and 3.3 V rails are correct.

---

## POST failures

During startup the tester performs a **Power-On Self Test (POST)**.

If POST reports an error, identify the failed subsystem before continuing.

### OLED failure

Possible causes:

* OLED module not connected
* Incorrect header soldering
* I²C communication fault

Checks:

* Inspect the OLED header.
* Verify SDA and SCL continuity.
* Confirm the OLED module is correctly fitted.

---

### MCP23017 failure

Possible causes:

* MCP23017 incorrectly installed
* Poor solder joints
* I²C bus fault

Checks:

* Verify 3.3 V supply.
* Inspect SDA and SCL.
* Check device orientation.
* Reflow suspect solder joints.

---

### Button test failure

Possible causes:

* Incorrect switch orientation
* Poor solder joints
* Mechanical obstruction

Checks:

* Press each button several times.
* Inspect solder joints.
* Verify switch operation using a multimeter if necessary.

---

## OLED display problems

### Symptom

Display remains blank.

Possible causes:

* No power
* Incorrect OLED orientation
* Faulty OLED module
* I²C communication failure

Checks:

* Verify the 3.3 V rail.
* Confirm OLED orientation.
* Inspect the OLED connector.
* Check I²C continuity.

---

## Rotary encoder problems

### Symptom

Menu navigation is unreliable.

Possible causes:

* Poor solder joints
* Incorrect encoder alignment
* Mechanical damage

Checks:

* Inspect solder joints.
* Confirm encoder alignment.
* Rotate the encoder slowly while observing the menu.

---

## TEST button problems

### Symptom

Pressing **TEST** has no effect.

Possible causes:

* Faulty switch
* Poor solder joint
* Firmware configuration issue

Checks:

* Inspect switch soldering.
* Verify switch operation.
* Repeat the POST.

---

## IC testing problems

### Symptom

Every IC reports **FAIL**.

Possible causes:

* Incorrect IC selected
* Wrong package size
* Wrong DUT supply voltage
* Poor IC socket contact

Checks:

* Verify the selected IC.
* Verify package selection.
* Confirm the DUT voltage.
* Reinsert the IC.
* Test using a known-good device.

---

### Symptom

Only one IC fails.

Possible causes:

* Faulty IC
* Dirty or oxidised pins
* Bent pins
* Counterfeit device

Checks:

* Clean the IC pins.
* Straighten bent pins.
* Test another known-good device of the same type.
* Repeat the test.

---

## Intermittent failures

Intermittent failures are often caused by:

* Dirty IC pins
* Worn ZIF socket contacts
* Poor solder joints
* Marginal ICs
* Incorrect supply voltage

Use **Soak Test** mode to help identify intermittent faults.

---

## 74LVC device problems

> [!IMPORTANT]
>
> All 74LVC devices must be tested with the DUT voltage selector set to **3.3 V**.

Common causes of failure include:

* Incorrect supply voltage
* Dirty IC pins
* Poor socket contact

---

## Before reporting a problem

Please gather the following information:

* Hardware revision
* Firmware version
* IC part number
* Logic family
* Package size
* DUT voltage
* Test mode
* POST results
* Error messages
* USB serial output (if available)

Providing this information will help diagnose the problem more quickly.

---

## Quick reference

| Symptom | Possible cause | Recommended action |
| --- | --- | --- |
| No power | USB or regulator problem | Verify 5 V and 3.3 V rails |
| Blank OLED | Display or I²C fault | Check OLED installation |
| POST failure | Hardware fault | Identify failed subsystem |
| TEST button not responding | Switch or solder fault | Inspect button and solder joints |
| All ICs fail | Configuration error | Verify IC selection, package and voltage |
| One IC fails | Faulty IC | Test another known-good device |
| Intermittent failures | Poor contact | Clean IC pins and run Soak Test |
| No serial output	 | Incorrect COM port	| Verify Thonny interpreter & USB connection|

---

## Still having problems?

If the fault cannot be resolved:

1. Repeat the POST.
2. Verify the power rails.
3. Test with a known-good IC.
4. Review the **Build Guide**.
5. Review the **Usage Guide**.

If you believe you have found a firmware defect or hardware issue, please include the information listed above when opening a GitHub issue.

Most problems are resolved by careful inspection of the power supply, solder joints, connector alignment, or IC orientation before more complex troubleshooting is required.
---

# Next Steps

You should now have the information needed to diagnose and resolve the most common hardware, firmware, and operational issues with the **OD-PT74 Pico 74xx IC Tester**.

If your issue is not covered in this guide, please check for updates to the documentation, firmware releases, or report the problem through the project's GitHub repository.

## Related Documentation

| Document | Description |
|---|---|
| [🏠 Project Home](../../README.md) | Return to the main project page |
| [📖 Documentation Index](../README.md) | Browse all project documentation |
| [🚀 Getting Started](getting-started.md) | First-time setup |
| [🔧 Build Guide](build-guide.md) | Hardware assembly |
| [💾 Firmware Guide](firmware-guide.md) | Installing and updating the firmware |
| [▶️ Usage Guide](usage-guide.md) | Operating the tester |
| [🧩 Supported ICs](supported-ics.md) | List of supported logic devices |
| **🛠 Troubleshooting Guide** | **You are here** |

---

| ← Previous | Next → |
|---|---|
| [🧩 Supported ICs](supported-ics.md) | [🏠 Project Home](../../README.md) |

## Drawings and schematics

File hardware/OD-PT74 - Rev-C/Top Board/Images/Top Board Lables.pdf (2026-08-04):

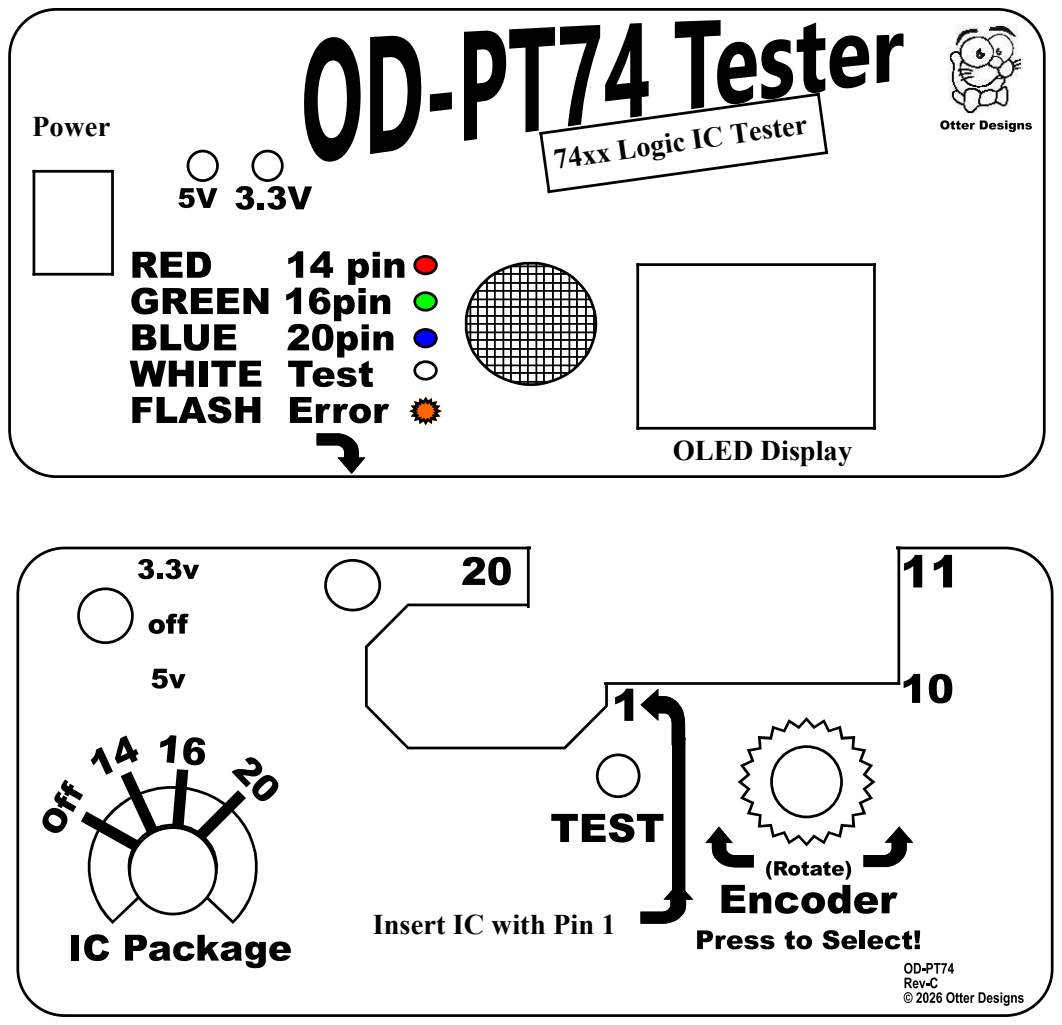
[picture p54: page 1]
Power; OLED Display

74xx Logic IC Tester

Insert IC with Pin 1

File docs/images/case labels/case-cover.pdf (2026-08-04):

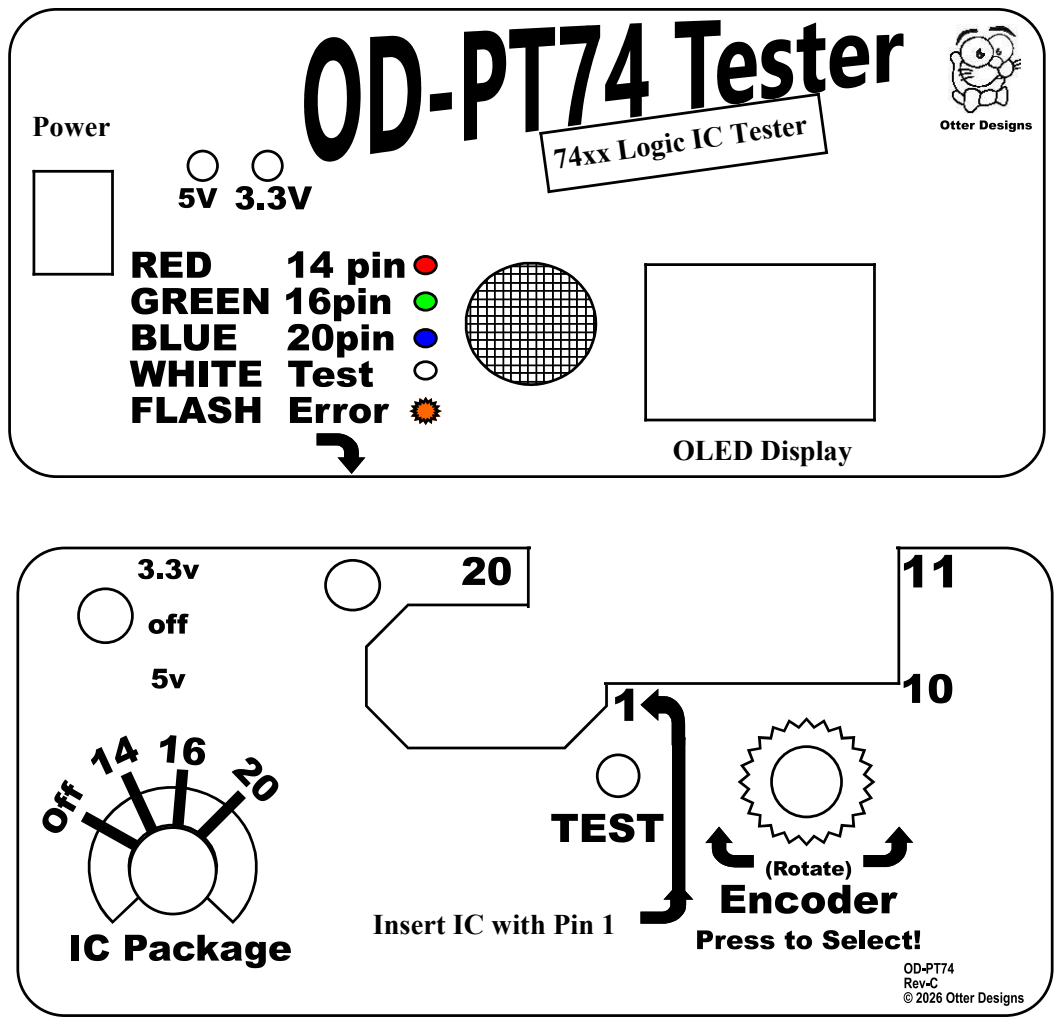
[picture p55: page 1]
Power; OLED Display

74xx Logic IC Tester

Insert IC with Pin 1

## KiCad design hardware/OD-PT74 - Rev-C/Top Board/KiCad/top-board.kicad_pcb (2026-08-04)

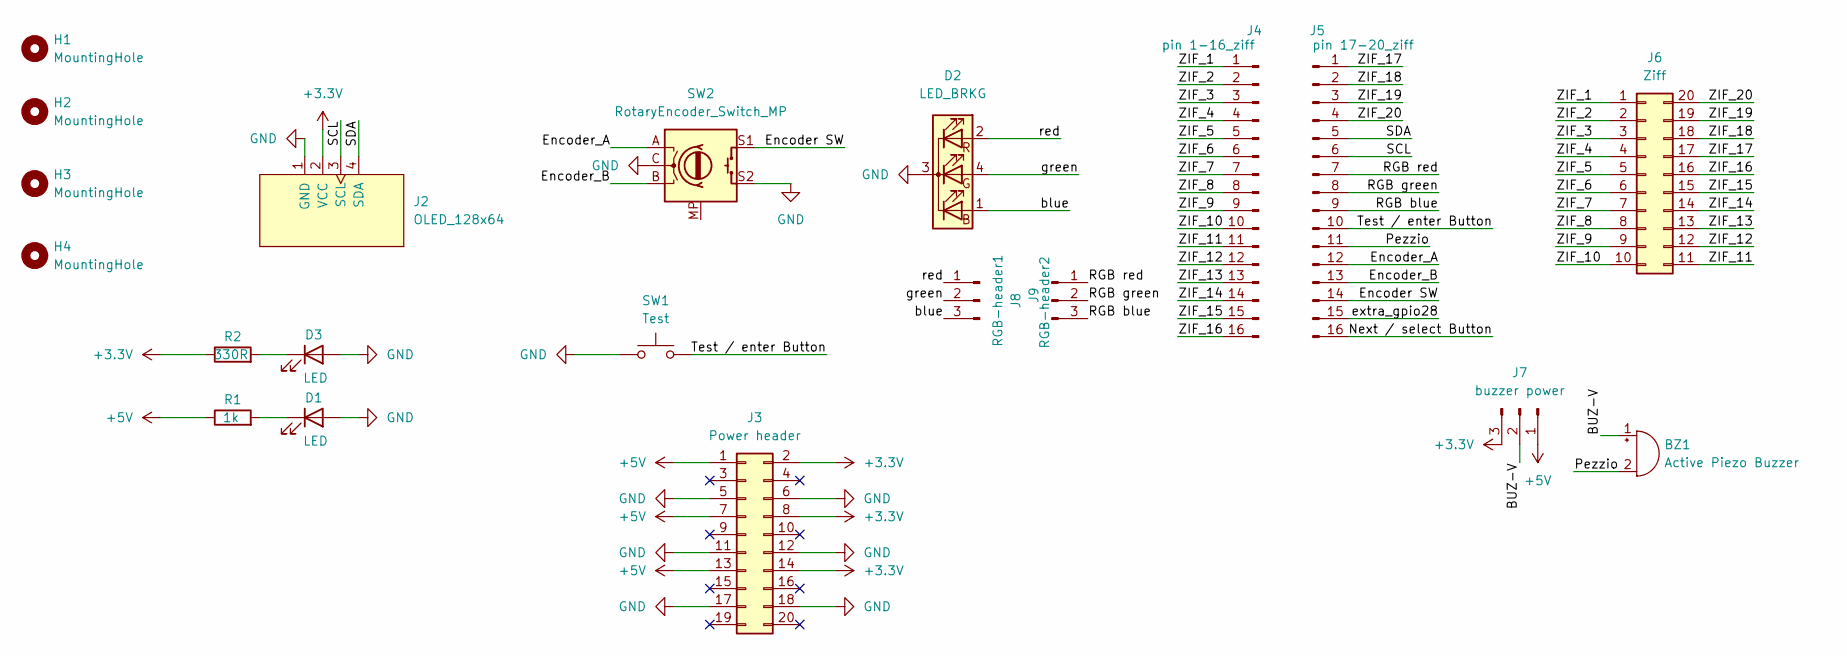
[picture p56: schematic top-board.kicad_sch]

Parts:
BZ1: Active Piezo Buzzer; Buzzer_15x7.5RM7.6
D1, D3: LED; LED_D3.0mm
D2: LED_BRKG; LED_D5.0mm-4_RGB_Staggered_Pins
H1, H2, H3, H4: MountingHole; MountingHole_3.2mm_M3
J2: OLED_128x64
J3: Power header; PinHeader_2x10_P2.54mm_Vertical
J4: pin 1-16_ziff; PinHeader_1x16_P2.54mm_Vertical
J5: pin 17-20_ziff; PinHeader_1x16_P2.54mm_Vertical
J6: Ziff; DIP_Socket-20_W4.3mm_W5.08mm_W7.62mm_W10.16mm_W10.9mm_3M_22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
J7: buzzer power; PinHeader_1x03_P2.54mm_Horizontal
J8: RGB-header1; PinHeader_1x03_P2.54mm_Vertical
J9: RGB-header2; PinHeader_1x03_P2.54mm_Vertical
R1: 1k; R_Axial_DIN0207_L6.3mm_D2.5mm_P7.62mm_Horizontal
R2: 330R; R_Axial_DIN0207_L6.3mm_D2.5mm_P7.62mm_Horizontal
SW1: Test; SW_PUSH_6mm
SW2: RotaryEncoder_Switch_MP; RotaryEncoder_Alps_EC11E-Switch_Vertical_H20mm

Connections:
+3.3V: J2.2 (VCC), J3.2, J3.8, J3.14, J7.3, R2.1
+5V: J3.1, J3.7, J3.13, J7.1, R1.1
/BUZ-V: BZ1.1 (+), J7.2
/Encoder SW: J5.14, SW2.S1
/Encoder_A: J5.12, SW2.A
/Encoder_B: J5.13, SW2.B
/Next / select Button: J5.16
/Pezzio: BZ1.2 (-), J5.11
/RGB blue: J5.9, J9.3
/RGB green: J5.8, J9.2
/RGB red: J5.7, J9.1
/SCL: J2.3 (SCL), J5.6
/SDA: J2.4 (SDA), J5.5
/Test / enter Button: J5.10, SW1.2
/ZIF_1: J4.1, J6.1
/ZIF_2: J4.2, J6.2
/ZIF_3: J4.3, J6.3
/ZIF_4: J4.4, J6.4
/ZIF_5: J4.5, J6.5
/ZIF_6: J4.6, J6.6
/ZIF_7: J4.7, J6.7
/ZIF_8: J4.8, J6.8
/ZIF_9: J4.9, J6.9
/ZIF_10: J4.10, J6.10
/ZIF_11: J4.11, J6.11
/ZIF_12: J4.12, J6.12
/ZIF_13: J4.13, J6.13
/ZIF_14: J4.14, J6.14
/ZIF_15: J4.15, J6.15
/ZIF_16: J4.16, J6.16
/ZIF_17: J5.1, J6.17
/ZIF_18: J5.2, J6.18
/ZIF_19: J5.3, J6.19
/ZIF_20: J5.4, J6.20
/blue: D2.1 (BA), J8.3
/extra_gpio28: J5.15
/green: D2.4 (GA), J8.2
/red: D2.2 (RA), J8.1
GND: D1.2 (A), D2.3 (K), D3.2 (A), J2.1 (GND), J3.5, J3.6, J3.11, J3.12, J3.17, J3.18, SW1.1, SW2.C, SW2.S2
unnamed: D1.1 (K), R1.2
unnamed: D3.1 (K), R2.2

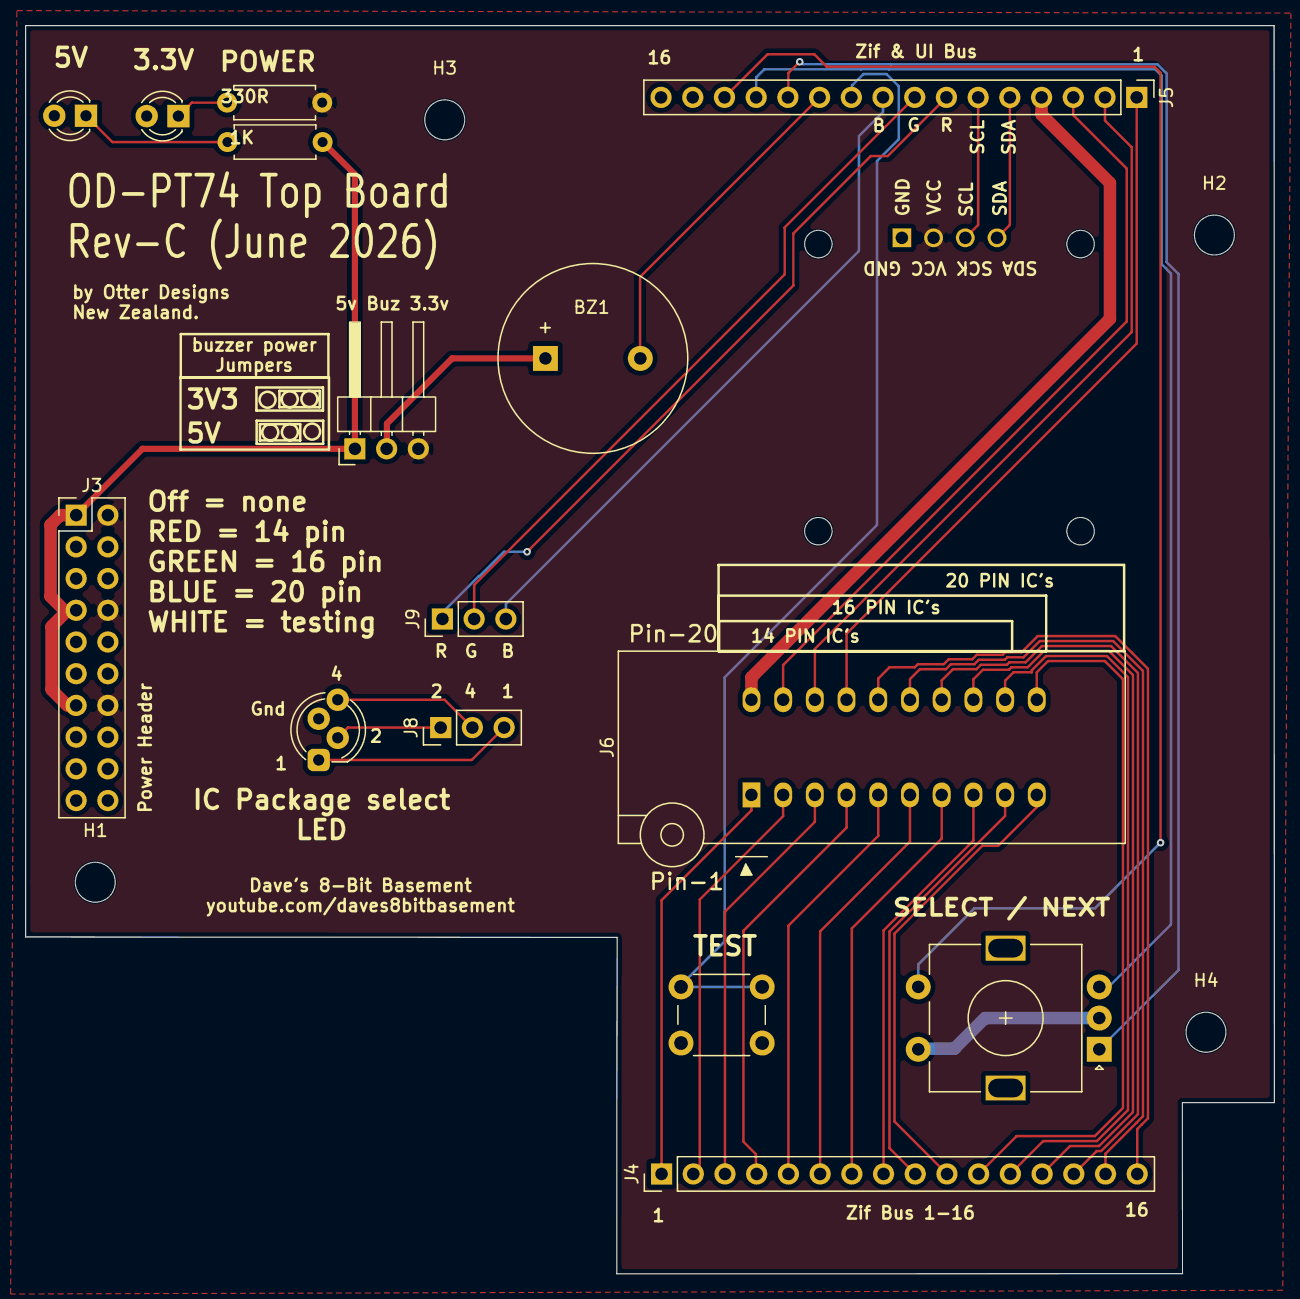
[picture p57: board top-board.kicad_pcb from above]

Board: 2 copper layers, 100.0 x 100.0 mm, 20 parts (0 on the bottom side), 39 nets.

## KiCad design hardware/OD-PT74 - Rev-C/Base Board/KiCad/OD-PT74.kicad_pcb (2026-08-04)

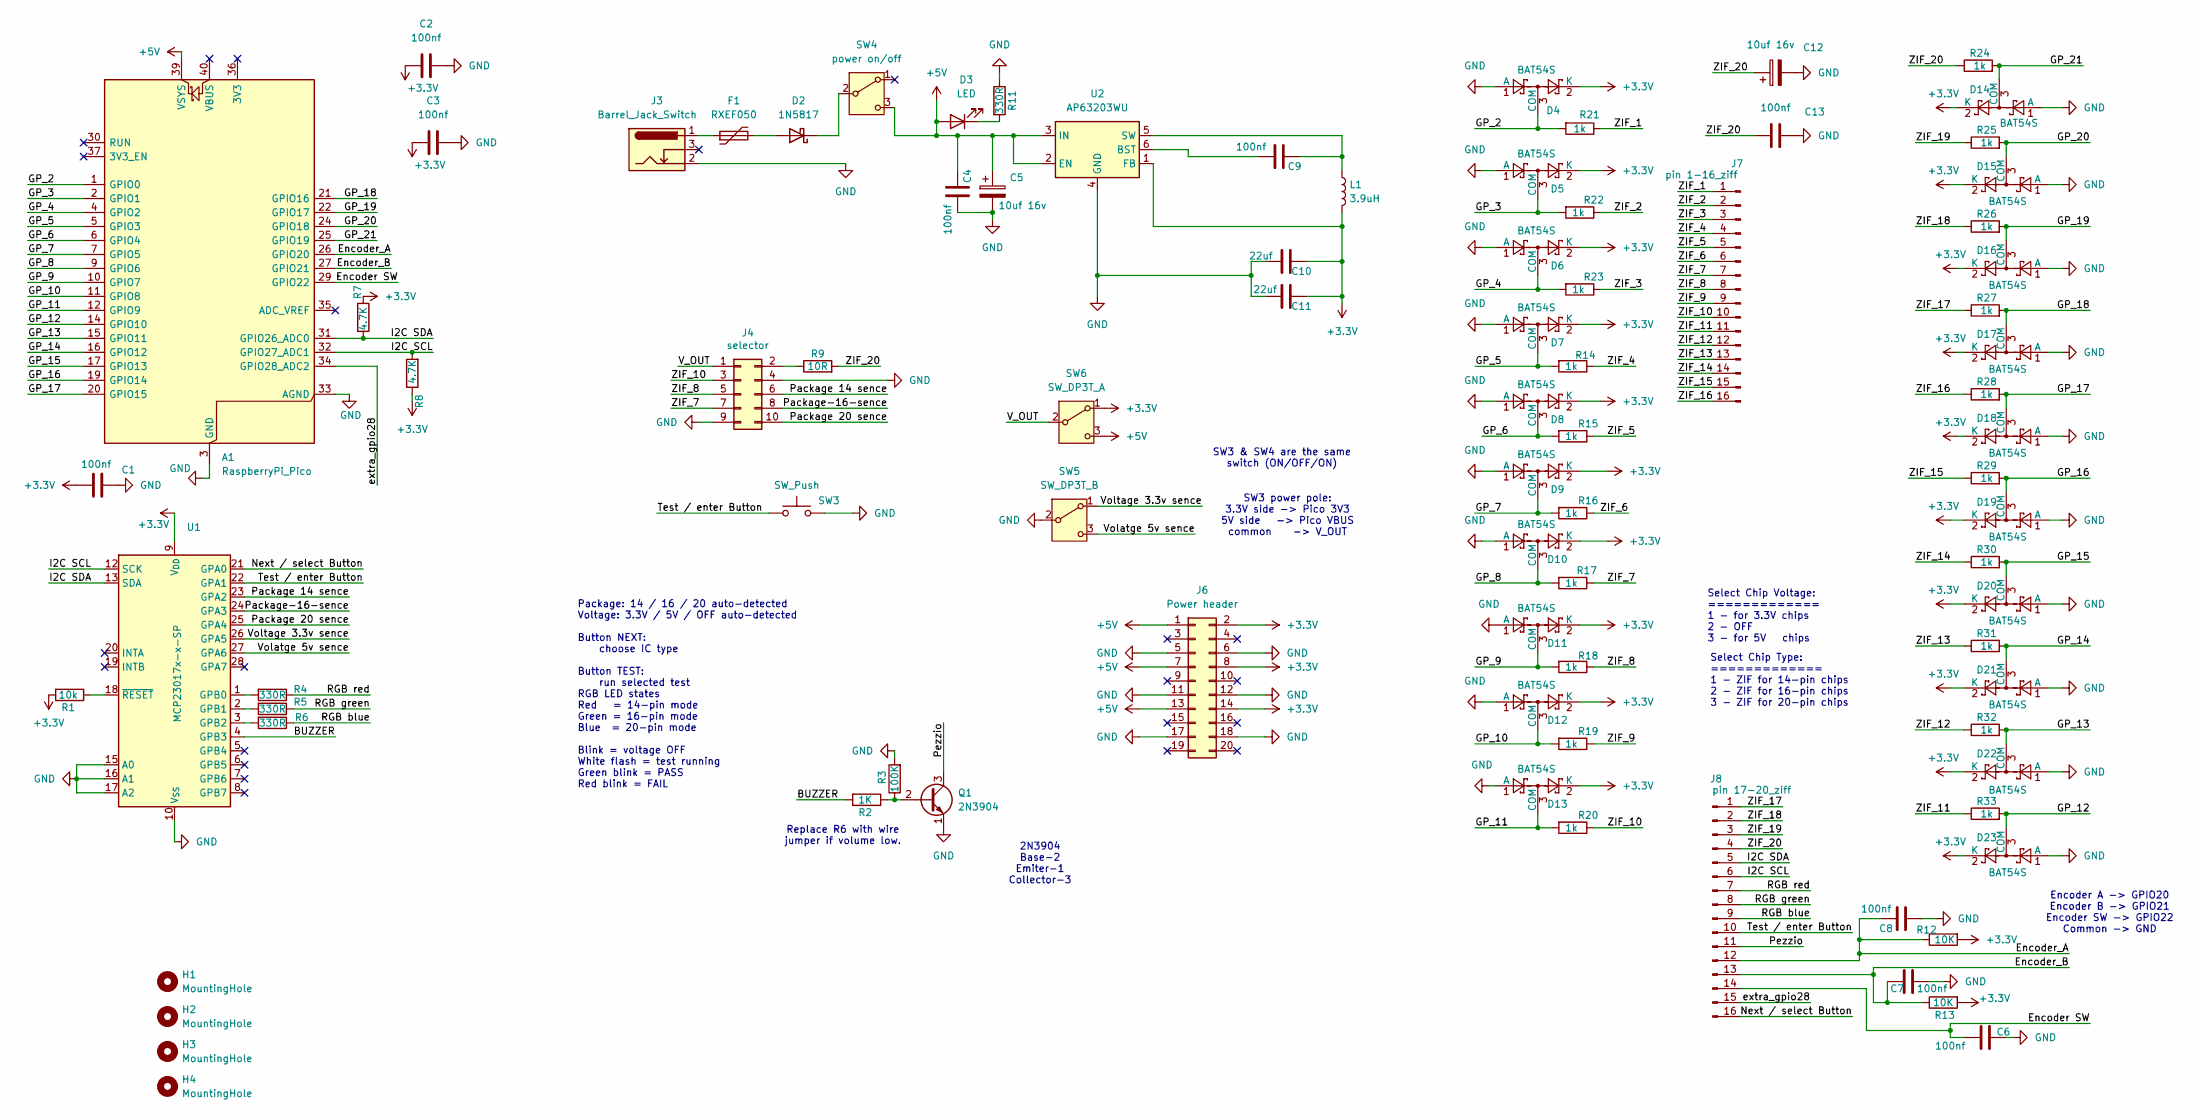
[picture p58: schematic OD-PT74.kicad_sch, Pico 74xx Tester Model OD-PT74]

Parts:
A1: RaspberryPi_Pico; RaspberryPi_Pico_Common_THT
C1, C2, C3, C4, C6, C7, C8, C9, C13: 100nf; C_Disc_D6.0mm_W2.5mm_P5.00mm
C5, C12: 10uf 16v; CP_Radial_D8.0mm_P5.00mm
C10, C11: 22uf; C_Disc_D6.0mm_W2.5mm_P5.00mm
D2: 1N5817; D_DO-41_SOD81_P10.16mm_Horizontal
D3: LED; LED_D3.0mm_Clear
D4, D5, D6, D7, D8, D9, D10, D11, D12, D13, D14, D15, D16, D17, D18, D19, D20, D21, D22, D23: BAT54S; SOT-23
F1: RXEF050; Fuse_Littelfuse_395Series
H1, H2, H3, H4: MountingHole; MountingHole_3.2mm_M3
J3: Barrel_Jack_Switch; BarrelJack_Horizontal
J4: selector; PinHeader_2x05_P2.54mm_Vertical
J6: Power header; PinHeader_2x10_P2.54mm_Vertical
J7: pin 1-16_ziff; PinHeader_1x16_P2.54mm_Vertical
J8: pin 17-20_ziff; PinHeader_1x16_P2.54mm_Vertical
L1: 3.9uH; R_Axial_DIN0207_L6.3mm_D2.5mm_P7.62mm_Horizontal
Q1: 2N3904; TO-92L_Wide
R1: 10k; R_Axial_DIN0207_L6.3mm_D2.5mm_P7.62mm_Horizontal
R2: 1K; R_Axial_DIN0207_L6.3mm_D2.5mm_P7.62mm_Horizontal
R3: 100K; R_Axial_DIN0207_L6.3mm_D2.5mm_P7.62mm_Horizontal
R4, R5, R6, R11: 330R; R_Axial_DIN0207_L6.3mm_D2.5mm_P7.62mm_Horizontal
R7, R8: 4.7K; R_Axial_DIN0207_L6.3mm_D2.5mm_P7.62mm_Horizontal
R9: 10R; R_Axial_DIN0207_L6.3mm_D2.5mm_P7.62mm_Horizontal
R12, R13: 10K; R_Axial_DIN0207_L6.3mm_D2.5mm_P7.62mm_Horizontal
R14, R15, R16, R17, R18, R19, R20, R21, R22, R23, R24, R25, R26, R27, R28, R29, R30, R31, R32, R33: 1k; R_Axial_DIN0207_L6.3mm_D2.5mm_P7.62mm_Horizontal
SW3: SW_Push; SW_PUSH_6mm_H7.3mm
SW4: power on/off; PinHeader_1x03_P2.54mm_Vertical
SW5: SW_DP3T_B; PinSocket_1x03_P2.54mm_Vertical
SW6: SW_DP3T_A; PinSocket_1x03_P2.54mm_Vertical
U1: MCP23017x-x-SP; DIP-28_W7.62mm
U2: AP63203WU; TSOT-23-6

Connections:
+3.3V: C1.1, C2.1, C3.1, C10.2, C11.2, D4.2 (K), D5.2 (K), D6.2 (K), D7.2 (K), D8.2 (K), D9.2 (K), D10.2 (K), D11.2 (K), D12.2 (K), D13.2 (K), D14.2 (K), D15.2 (K), D16.2 (K), D17.2 (K), D18.2 (K), D19.2 (K), D20.2 (K), D21.2 (K), D22.2 (K), D23.2 (K), J6.2, J6.8, J6.14, L1.2, R1.2, R7.1, R8.1, R12.2, R13.2, SW6.1 (A), U1.9 (V_{DD}), U2.1 (FB)
+5V: A1.39 (VSYS), C4.2, C5.1, D3.2 (A), J6.1, J6.7, J6.13, SW4.3 (C), SW6.3 (C), U2.2 (EN), U2.3 (IN)
/<NO NET>: J4.8, U1.24 (GPA3)
/BUZZER: R2.2, U1.4 (GPB3)
/Encoder SW: A1.29 (GPIO22), C6.2, J8.14
/Encoder_A: A1.26 (GPIO20), C8.2, J8.12, R12.1
/Encoder_B: A1.27 (GPIO21), C7.2, J8.13, R13.1
/GP_2: A1.1 (GPIO0), D4.3 (COM), R21.2
/GP_3: A1.2 (GPIO1), D5.3 (COM), R22.2
/GP_4: A1.4 (GPIO2), D6.3 (COM), R23.2
/GP_5: A1.5 (GPIO3), D7.3 (COM), R14.2
/GP_6: A1.6 (GPIO4), D8.3 (COM), R15.2
/GP_7: A1.7 (GPIO5), D9.3 (COM), R16.2
/GP_8: A1.9 (GPIO6), D10.3 (COM), R17.2
/GP_9: A1.10 (GPIO7), D11.3 (COM), R18.2
/GP_10: A1.11 (GPIO8), D12.3 (COM), R19.2
/GP_11: A1.12 (GPIO9), D13.3 (COM), R20.2
/GP_12: A1.14 (GPIO10), D23.3 (COM), R33.2
/GP_13: A1.15 (GPIO11), D22.3 (COM), R32.2
/GP_14: A1.16 (GPIO12), D21.3 (COM), R31.2
/GP_15: A1.17 (GPIO13), D20.3 (COM), R30.2
/GP_16: A1.19 (GPIO14), D19.3 (COM), R29.2
/GP_17: A1.20 (GPIO15), D18.3 (COM), R28.2
/GP_18: A1.21 (GPIO16), D17.3 (COM), R27.2
/GP_19: A1.22 (GPIO17), D16.3 (COM), R26.2
/GP_20: A1.24 (GPIO18), D15.3 (COM), R25.2
/GP_21: A1.25 (GPIO19), D14.3 (COM), R24.2
/I2C SCL: A1.32 (GPIO27_ADC1), J8.6, R8.2, U1.12 (SCK)
/I2C SDA: A1.31 (GPIO26_ADC0), J8.5, R7.2, U1.13 (SDA)
/Next / select Button: J8.16, U1.21 (GPA0)
/Package 14 sence: J4.6, U1.23 (GPA2)
/Package 20 sence: J4.10, U1.25 (GPA4)
/Pezzio: J8.11, Q1.3 (C)
/RGB blue: J8.9, R6.1
/RGB green: J8.8, R5.1
/RGB red: J8.7, R4.1
/Test / enter Button: J8.10, SW3.1, U1.22 (GPA1)
/V_OUT: J4.1, SW6.2 (B)
/Volatge 5v sence: SW5.3 (C), U1.27 (GPA6)
/Voltage 3.3v sence: SW5.1 (A), U1.26 (GPA5)
/ZIF_1: J7.1, R21.1
/ZIF_2: J7.2, R22.1
/ZIF_3: J7.3, R23.1
/ZIF_4: J7.4, R14.1
/ZIF_5: J7.5, R15.1
/ZIF_6: J7.6, R16.1
/ZIF_7: J4.7, J7.7, R17.1
/ZIF_8: J4.5, J7.8, R18.1
/ZIF_9: J7.9, R19.1
/ZIF_10: J4.3, J7.10, R20.1
/ZIF_11: J7.11, R33.1
/ZIF_12: J7.12, R32.1
/ZIF_13: J7.13, R31.1
/ZIF_14: J7.14, R30.1
/ZIF_15: J7.15, R29.1
/ZIF_16: J7.16, R28.1
/ZIF_17: J8.1, R27.1
/ZIF_18: J8.2, R26.1
/ZIF_19: J8.3, R25.1
/ZIF_20: C12.1, C13.1, J8.4, R9.2, R24.1
/extra_gpio28: A1.34 (GPIO28_ADC2), J8.15
GND: A1.3 (GND), A1.8 (GND), A1.13 (GND), A1.18 (GND), A1.23 (GND), A1.28 (GND), A1.33 (AGND), A1.38 (GND), C1.2, C2.2, C3.2, C4.1, C5.2, C6.1, C7.1, C8.1, C10.1, C11.1, C12.2, C13.2, D4.1 (A), D5.1 (A), D6.1 (A), D7.1 (A), D8.1 (A), D9.1 (A), D10.1 (A), D11.1 (A), D12.1 (A), D13.1 (A), D14.1 (A), D15.1 (A), D16.1 (A), D17.1 (A), D18.1 (A), D19.1 (A), D20.1 (A), D21.1 (A), D22.1 (A), D23.1 (A), J3.2, J4.4, J4.9, J6.5, J6.6, J6.11, J6.12, J6.17, J6.18, Q1.1 (E), R3.2, R11.1, SW3.2, SW5.2 (B), U1.10 (V_{SS}), U1.15 (A0), U1.16 (A1), U1.17 (A2), U2.4 (GND)
unnamed: D2.2 (A), F1.2
unnamed: D2.1 (K), SW4.2 (B)
unnamed: D3.1 (K), R11.2
unnamed: F1.1, J3.1
unnamed: J4.2, R9.1
unnamed: Q1.2 (B), R2.1, R3.1
unnamed: R4.2, U1.1 (GPB0)
unnamed: R5.2, U1.2 (GPB1)
unnamed: R6.2, U1.3 (GPB2)
unnamed: R1.1, U1.18 (~RESET)
unnamed: C9.1, U2.6 (BST)
unnamed: C9.2, L1.1, U2.5 (SW)

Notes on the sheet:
SW3 power pole: 3.3V side -> Pico 3V3 5V side -> Pico VBUS common -> V_OUT
Select Chip Type: ============= 1 - ZIF for 14-pin chips 2 - ZIF for 16-pin chips 3 - ZIF for 20-pin chips
SW3 & SW4 are the same switch (ON/OFF/ON)
Select Chip Voltage: ============= 1 - for 3.3V chips 2 - OFF 3 - for 5V chips
Replace R6 with wire jumper if volume low.
Package: 14 / 16 / 20 auto-detected Voltage: 3.3V / 5V / OFF auto-detected Button NEXT: choose IC type Button TEST: run selected test RGB LED states Red = 14-pin mode Green = 16-pin mode Blue = 20-pin mode Blink = voltage OFF White flash = test running Green blink = PASS Red blink = FAIL
2N3904 Base-2 Emiter-1 Collector-3
Encoder A -> GPIO20 Encoder B -> GPIO21 Encoder SW -> GPIO22 Common -> GND

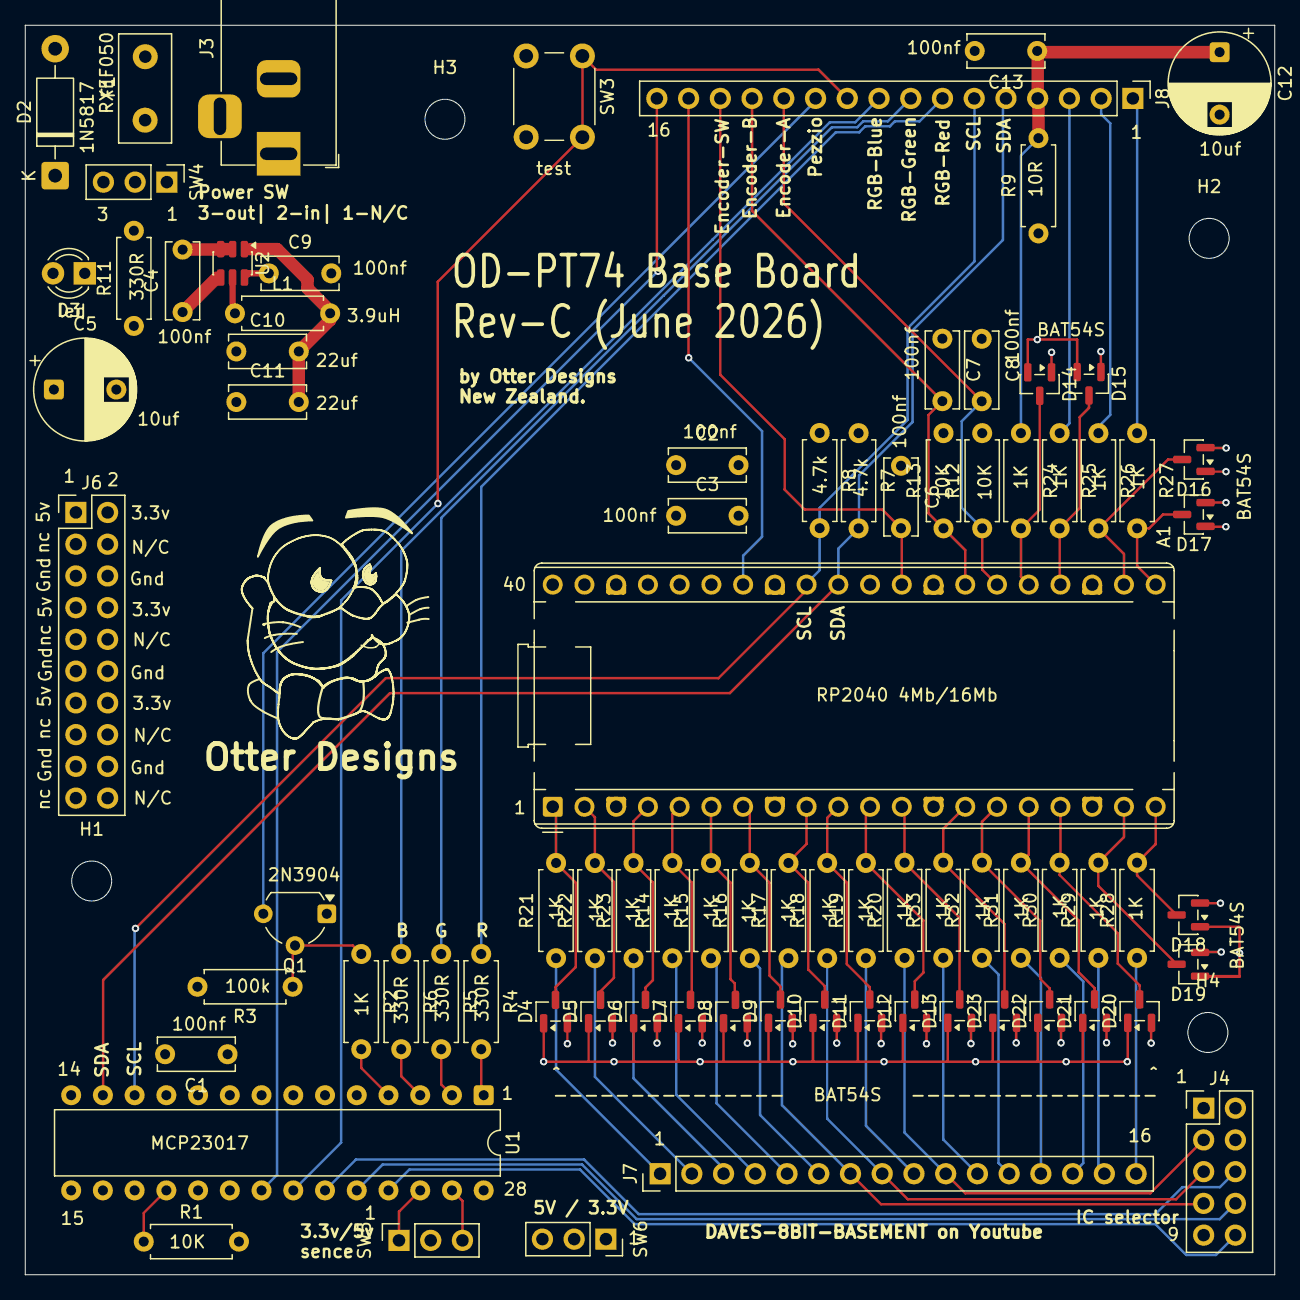
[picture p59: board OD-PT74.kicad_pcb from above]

Board: 4 copper layers, 100.0 x 100.0 mm, 86 parts (0 on the bottom side), 74 nets.

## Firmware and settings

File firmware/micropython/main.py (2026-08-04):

# ============================================================
# OD-PT74
# Pico 74xx Logic IC Tester
#
# Hardware : Rev-C
# Firmware : v1.0.0
#
# Author    : Otter Designs
#
# Release : Public v1.0.0
#
# Description:
# The OD-PT74 is a Raspberry Pi Pico based logic IC tester for
# the 74xx family of TTL logic devices.
#
# The firmware controls the GPIO test interface, MCP23017 I/O
# expander, SSD1306 OLED display and user interface to perform
# functional testing of supported ICs.
# ============================================================
# ============================================================
# File Structure
#
#   Imports
#   Product Information
#   Hardware Configuration
#   User Interface Pins
#   ZIF Pin Mapping
#   Package Pin Maps
#   MCP23017 Definitions
#   OLED Functions
#   MCP23017 Functions
#   Hardware Helper Functions
#   GPIO/ZIF Functions
#   Generic Test Helpers
#   Individual IC Test Functions
#   Chip Database
#   Statistics Functions
#   Menu Functions
#   Main Program
# ============================================================
from machine import Pin, SoftI2C
import time
try:
    import ujson as json
except:
    import json
  
# ------------------------------------------------------------
# Product Information
# ------------------------------------------------------------

PRODUCT_NAME = "OD-PT74"
PRODUCT_DESCRIPTION = "Pico 74xx Logic IC Tester"

HARDWARE_REV = "Rev-C"
FIRMWARE_VERSION = "v1.0.0"
COPYRIGHT = "© 2026 Otter Designs"
AUTHOR = "Otter Designs"

# ------------------------------------------------------------
# Hardware Configuration
# ------------------------------------------------------------

I2C_SDA = 26
I2C_SCL = 27
MCP_ADDR = 0x20

# ------------------------------------------------------------
# User Interface Pins
# ------------------------------------------------------------

enc_a = Pin(20, Pin.IN, Pin.PULL_UP)
enc_b = Pin(21, Pin.IN, Pin.PULL_UP)
enc_sw = Pin(22, Pin.IN, Pin.PULL_UP)
last_enc_a = enc_a.value()

# ------------------------------------------------------------
# ZIF Pin Mapping
# ------------------------------------------------------------

ZIF_TO_GPIO = {
    1: 0,
    2: 1,
    3: 2,
    4: 3,
    5: 4,
    6: 5,
    7: 6,
    8: 7,
    9: 8,
    10: 9,
    11: 10,
    12: 11,
    13: 12,
    14: 13,
    15: 14,
    16: 15,
    17: 16,
    18: 17,
    19: 18,
    20: 19,
}

MAP_8 = {
    1: 1,
    2: 2,
    3: 3,
    4: 4,
    5: 17,
    6: 18,
    7: 19,
    8: 20,
}

MAP_14 = {
    1: 1,
    2: 2,
    3: 3,
    4: 4,
    5: 5,
    6: 6,
    7: 7,
    8: 14,
    9: 15,
    10: 16,
    11: 17,
    12: 18,
    13: 19,
    14: 20,
}

MAP_16 = {
    1: 1,
    2: 2,
    3: 3,
    4: 4,
    5: 5,
    6: 6,
    7: 7,
    8: 8,
    9: 13,
    10: 14,
    11: 15,
    12: 16,
    13: 17,
    14: 18,
    15: 19,
    16: 20,
}

MAP_20 = {
    1: 1,
    2: 2,
    3: 3,
    4: 4,
    5: 5,
    6: 6,
    7: 7,
    8: 8,
    9: 9,
    10: 10,
    11: 11,
    12: 12,
    13: 13,
    14: 14,
    15: 15,
    16: 16,
    17: 17,
    18: 18,
    19: 19,
    20: 20,
}

# ------------------------------------------------------------
# Global Variables
# ------------------------------------------------------------

current_map = MAP_14
zif_pins = {}

# ------------------------------------------------------------
# MCP23017 Register Definitions
# ------------------------------------------------------------

IODIRA = 0x00
IODIRB = 0x01
GPPUA  = 0x0C
GPPUB  = 0x0D
GPIOA  = 0x12
GPIOB  = 0x13
OLATB  = 0x15

# ------------------------------------------------------------
# MCP23017 GPIO Assignments
# ------------------------------------------------------------
# MCP GPA inputs
BTN_TEST = 1
PKG14    = 2
PKG16    = 3
PKG20    = 4
V_3V3    = 5
V_5V     = 6

# MCP GPB outputs
RGB_R  = 0
RGB_G  = 1
RGB_B  = 2
BUZZER = 3

i2c = SoftI2C(scl=Pin(I2C_SCL), sda=Pin(I2C_SDA), freq=100000)

try:
    import ssd1306
    OLED_AVAILABLE = True
except:
    OLED_AVAILABLE = False
    
oled = None

# ------------------------------------------------------------
# OLED Initialisation
# ------------------------------------------------------------

def oled_init():
    global oled

    if not OLED_AVAILABLE:
        print("OLED driver not found")
        return

    try:
        oled = ssd1306.SSD1306_I2C(128, 64, i2c, addr=0x3c)
        oled.fill(0)
        oled.text(PRODUCT_NAME, 0, 0)
        oled.text("Firmware", 0, 16)
        oled.text(FIRMWARE_VERSION, 0, 32)
        oled.show()
        print("OLED OK")
    except Exception as e:
        oled = None
        print("OLED ERROR:", e)

# ------------------------------------------------------------
# OLED Utility Functions
# ------------------------------------------------------------

def oled_clear():
    if oled:
        oled.fill(0)

def oled_show():
    if oled:
        oled.show()

def oled_text(txt, x, y):
    if oled:
        oled.text(str(txt), x, y)

# ------------------------------------------------------------
# OLED User Interface Screens
# ------------------------------------------------------------

def oled_main(chip, family, mode, pkg, volt, field):
    if not oled:
        return

    oled.fill(0)

    # OLED is intentionally kept simple.
    # Detailed information stays on the terminal.
    prefix_ic = ">" if field == 0 else " "
    prefix_fam = ">" if field == 1 else " "
    prefix_mode = ">" if field == 2 else " "

    oled.text(prefix_ic + chip["name"][:15], 0, 0)
    oled.text(prefix_fam + "Fam: " + family, 0, 16)
    oled.text(prefix_mode + mode, 0, 28)

    status = "{}pin  {}".format(pkg if pkg else "--", volt)
    oled.text(status[:16], 0, 44)
    oled.text("READY", 0, 56)

    oled.show()
    
def oled_info(chip):
    if not oled:
        return

    oled.fill(0)

    oled.text(chip["name"][:16], 0, 0)
    oled.text("Pins: {}".format(chip["pins"]), 0, 16)

    oled.text("Family:", 0, 32)
    oled.text(families[selected_family], 64, 32)

    oled.text("TEST=Exit", 0, 56)

    oled.show()
    
def oled_running(chip, mode):
    if not oled:
        return

    oled.fill(0)
    oled.text(chip["name"][:16], 0, 0)
    oled.text("Running...", 0, 24)
    oled.text(mode, 0, 40)
    oled.show()


def oled_result(chip, result):
    if not oled:
        return

    oled.fill(0)
    oled.text(chip["name"][:16], 0, 0)

    if result:
        oled.text("PASS", 44, 14)
    else:
        oled.text("FAIL", 44, 14)

    oled.text("S P{} F{}".format(session_pass, session_fail), 0, 32)
    oled.text("L P{} F{}".format(
        stats["lifetime_pass"],
        stats["lifetime_fail"]
    ), 0, 44)

    oled.text("TEST=Menu", 0, 56)
    oled.show()

def oled_soak(chip, passes, target):
    if not oled:
        return

    oled.fill(0)
    oled.text(chip["name"][:16], 0, 0)
    oled.text("SOAK", 0, 20)

    if target is None:
        oled.text("{} / INF".format(passes), 0, 40)
    else:
        oled.text("{} / {}".format(passes, target), 0, 40)

    oled.show()

def oled_error(msg):
    if not oled:
        return

    oled.fill(0)
    oled.text("ERROR", 44, 0)
    oled.text(str(msg)[:16], 0, 24)
    oled.text("See terminal", 0, 48)
    oled.show()

# ------------------------------------------------------------
# MCP23017 Functions
# ------------------------------------------------------------

def mcp_write(reg, val):
    i2c.writeto_mem(MCP_ADDR, reg, bytes([val & 0xFF]))

def mcp_read(reg):
    return i2c.readfrom_mem(MCP_ADDR, reg, 1)[0]

def mcp_init():
    mcp_write(IODIRA, 0xFF)  # GPA inputs
    mcp_write(IODIRB, 0xF0)  # GPB0..3 outputs
    mcp_write(GPPUA, 0xFF)   # GPA pullups
    mcp_write(GPPUB, 0x00)
    mcp_write(OLATB, 0x00)

print("I2C scan:", [hex(x) for x in i2c.scan()])

def mcp_input_low(bit):
    return (mcp_read(GPIOA) & (1 << bit)) == 0

def mcp_set_outputs(mask):
    mcp_write(OLATB, mask & 0xFF)

def rgb(r, g, b):
    mask = 0
    if r:
        mask |= 1 << RGB_R
    if g:
        mask |= 1 << RGB_G
    if b:
        mask |= 1 << RGB_B
    mcp_set_outputs(mask)

def buzzer(on):
    cur = mcp_read(GPIOB)
    if on:
        cur |= 1 << BUZZER
    else:
        cur &= ~(1 << BUZZER)
    mcp_write(OLATB, cur)

def beep(ms=80):
    buzzer(True)
    time.sleep_ms(ms)
    buzzer(False)

# ------------------------------------------------------------
# Hardware Detection
# ------------------------------------------------------------

def detect_package():
    val = mcp_read(GPIOA)

    if (val & 0x04) == 0:
        rgb(1, 0, 0)
        return 14, MAP_14

    if (val & 0x08) == 0:
        rgb(0, 1, 0)
        return 16, MAP_16

    if (val & 0x10) == 0:
        rgb(0, 0, 1)
        return 20, MAP_20

    rgb(0, 0, 0)
    return None, None

def detect_voltage():
    if mcp_input_low(V_3V3):
        return "3.3V"
    if mcp_input_low(V_5V):
        return "5V"
    return "OFF"

def wait_button(bit):
    while not mcp_input_low(bit):
        time.sleep_ms(20)
    time.sleep_ms(40)
    while mcp_input_low(bit):
        time.sleep_ms(20)
    time.sleep_ms(40)

# ------------------------------------------------------------
# ZIF GPIO Functions
# ------------------------------------------------------------

def all_zif_inputs():
    global zif_pins
    zif_pins = {}

    for zif, gpio in ZIF_TO_GPIO.items():
        zif_pins[zif] = Pin(gpio, Pin.IN)

    time.sleep_ms(2)

def dut_to_zif(dut_pin):
    return current_map[dut_pin]

def set_output(dut_pin, val):
    zif = dut_to_zif(dut_pin)
    gpio = ZIF_TO_GPIO[zif]

    p = Pin(gpio, Pin.OUT)
    p.value(1 if val else 0)

    zif_pins[zif] = p

def set_input(dut_pin):
    zif = dut_to_zif(dut_pin)
    gpio = ZIF_TO_GPIO[zif]
    zif_pins[zif] = Pin(gpio, Pin.IN)

def set_input_pullup(dut_pin):
    zif = dut_to_zif(dut_pin)
    gpio = ZIF_TO_GPIO[zif]
    zif_pins[zif] = Pin(gpio, Pin.IN, Pin.PULL_UP)

def set_input_pulldown(dut_pin):
    zif = dut_to_zif(dut_pin)
    gpio = ZIF_TO_GPIO[zif]
    zif_pins[zif] = Pin(gpio, Pin.IN, Pin.PULL_DOWN)
    
def read_pin(dut_pin):
    zif = dut_to_zif(dut_pin)
    return zif_pins[zif].value()

# ------------------------------------------------------------
# Test helpers
# ------------------------------------------------------------

def test_gate_2in(name, a_pin, b_pin, y_pin, func):
    ok = True

    for a, b in [(0,0), (0,1), (1,0), (1,1)]:
        all_zif_inputs()

        set_output(a_pin, a)
        set_output(b_pin, b)
        set_input(y_pin)

        time.sleep_ms(50)

        expected = func(a, b)
        got = read_pin(y_pin)

        if got != expected:
            print("{} FAIL A={} B={} expected={} got={}".format(
                name, a, b, expected, got
            ))
            ok = False

    all_zif_inputs()

    if ok:
        print("{} PASS".format(name))

    return ok

def test_gate_2in_oc(name, a_pin, b_pin, y_pin, func):
    ok = True

    for a, b in [(0,0), (0,1), (1,0), (1,1)]:
        all_zif_inputs()

        set_output(a_pin, a)
        set_output(b_pin, b)

        # Open-collector outputs need a pull-up because the IC only pulls low.
        set_input_pullup(y_pin)

        time.sleep_ms(50)

        expected = func(a, b)
        got = read_pin(y_pin)

        if got != expected:
            print("{} FAIL A={} B={} expected={} got={}".format(
                name, a, b, expected, got
            ))
            ok = False

    all_zif_inputs()

    if ok:
        print("{} PASS".format(name))

    return ok

def test_buffer_oc(name, a_pin, y_pin):
    ok = True

    for a in [0, 1]:
        all_zif_inputs()

        set_output(a_pin, a)
        set_input_pullup(y_pin)

        time.sleep_ms(50)

        expected = 1 if a else 0
        got = read_pin(y_pin)

        if got != expected:
            print("{} FAIL A={} expected={} got={}".format(
                name, a, expected, got
            ))
            ok = False

    all_zif_inputs()

    if ok:
        print("{} PASS".format(name))

    return ok

def test_inverter_oc(name, a_pin, y_pin):
    ok = True

    for a in [0, 1]:
        all_zif_inputs()

        set_output(a_pin, a)
        set_input_pullup(y_pin)

        time.sleep_ms(50)

        expected = 0 if a else 1
        got = read_pin(y_pin)

        if got != expected:
            print("{} FAIL A={} expected={} got={}".format(
                name, a, expected, got
            ))
            ok = False

    all_zif_inputs()

    if ok:
        print("{} PASS".format(name))

    return ok

def test_gate_3in(name, a_pin, b_pin, c_pin, y_pin, func):
    ok = True

    set_input(y_pin)

    tests = [
        (0,0,0),
        (0,0,1),
        (0,1,0),
        (0,1,1),
        (1,0,0),
        (1,0,1),
        (1,1,0),
        (1,1,1),
    ]

    for a,b,c in tests:

        set_output(a_pin, a)
        set_output(b_pin, b)
        set_output(c_pin, c)

        time.sleep_ms(100)

        expected = func(a,b,c)
        got = read_pin(y_pin)

        print(
            name,
            "A={} B={} C={} expected={} got={}".format(
                a,b,c,expected,got
            )
        )

        if got != expected:
            ok = False

    if ok:
        print(name, "PASS")

    return ok

def test_gate_4in(name, a_pin, b_pin, c_pin, d_pin, y_pin, func):
    ok = True

    tests = [
        (0,0,0,0), (0,0,0,1), (0,0,1,0), (0,0,1,1),
        (0,1,0,0), (0,1,0,1), (0,1,1,0), (0,1,1,1),
        (1,0,0,0), (1,0,0,1), (1,0,1,0), (1,0,1,1),
        (1,1,0,0), (1,1,0,1), (1,1,1,0), (1,1,1,1),
    ]

    for a,b,c,d in tests:
        all_zif_inputs()
        set_output(a_pin, a)
        set_output(b_pin, b)
        set_output(c_pin, c)
        set_output(d_pin, d)
        set_input(y_pin)

        time.sleep_ms(50)

        expected = func(a,b,c,d)
        got = read_pin(y_pin)

        if got != expected:
            print("{} FAIL A={} B={} C={} D={} expected={} got={}".format(
                name, a,b,c,d,expected,got
            ))
            ok = False

    all_zif_inputs()

    if ok:
        print("{} PASS".format(name))

    return ok

def test_gate_8in(name, pins, y_pin, func):
    ok = True

    tests = [
        [0,0,0,0,0,0,0,0],
        [1,0,0,0,0,0,0,0],
        [0,1,0,0,0,0,0,0],
        [0,0,1,0,0,0,0,0],
        [0,0,0,1,0,0,0,0],
        [0,0,0,0,1,0,0,0],
        [0,0,0,0,0,1,0,0],
        [0,0,0,0,0,0,1,0],
        [0,0,0,0,0,0,0,1],
        [1,1,1,1,1,1,1,1],
    ]

    for values in tests:
        all_zif_inputs()

        for pin, val in zip(pins, values):
            set_output(pin, val)

        set_input(y_pin)

        time.sleep_ms(50)

        expected = func(values)
        got = read_pin(y_pin)

        if got != expected:
            print("{} FAIL inputs={} expected={} got={}".format(
                name, values, expected, got
            ))
            ok = False

    all_zif_inputs()

    if ok:
        print("{} PASS".format(name))

    return ok

def test_inverter(name, a_pin, y_pin):
    ok = True

    for a in [0, 1]:
        all_zif_inputs()

        set_output(a_pin, a)
        set_input(y_pin)

        time.sleep_ms(50)

        expected = 0 if a else 1
        got = read_pin(y_pin)

        if got != expected:
            print("{} FAIL A={} expected={} got={}".format(
                name, a, expected, got
            ))
            ok = False

    all_zif_inputs()

    if ok:
        print("{} PASS".format(name))

    return ok

def expect_decoder_outputs(y0, y1, y2, y3, expected):
    return [
        y0 == expected[0],
        y1 == expected[1],
        y2 == expected[2],
        y3 == expected[3],
    ]
def test_buffer_3state(name, oe_pin, a_pin, y_pin, oe_active_low=True):
    ok = True

    # Enabled test
    enable_val = 0 if oe_active_low else 1

    for a in [0, 1]:
        all_zif_inputs()

        set_output(oe_pin, enable_val)
        set_output(a_pin, a)
        set_input(y_pin)

        time.sleep_ms(50)

        got = read_pin(y_pin)

        if got != a:
            print("{} FAIL ENABLED A={} expected={} got={}".format(
                name, a, a, got
            ))
            ok = False

    # Disabled / Hi-Z test
    disable_val = 1 if oe_active_low else 0

    all_zif_inputs()
    set_output(oe_pin, disable_val)
    set_output(a_pin, 0)
    set_input_pullup(y_pin)
    time.sleep_ms(50)
    got_hi = read_pin(y_pin)

    all_zif_inputs()
    set_output(oe_pin, disable_val)
    set_output(a_pin, 1)
    set_input_pulldown(y_pin)
    time.sleep_ms(50)
    got_lo = read_pin(y_pin)

    if got_hi != 1 or got_lo != 0:
        print("{} FAIL Hi-Z expected pullup=1 pulldown=0 got {}/{}".format(
            name, got_hi, got_lo
        ))
        ok = False

    all_zif_inputs()

    if ok:
        print("{} PASS".format(name))

    return ok

def test_shiftreg_74164():
    print("Testing 74164 8-bit shift register")

    ok = True

    # Pins
    # 1=A, 2=B, 8=GND
    # 9..13,15,16,17 = Q outputs
    # 8 CLK
    # 9 CLR\

    q_pins = [3,4,5,6,10,11,12,13]

    # -------------------------
    # Reset test
    # -------------------------

    all_zif_inputs()

    # CLR low
    set_output(9, 0)

    # CLK low
    set_output(8, 0)

    for q in q_pins:
        set_input(q)

    time.sleep_ms(50)

    got = [read_pin(q) for q in q_pins]

    if got != [0]*8:
        print("RESET FAIL got={}".format(got))
        ok = False

    # -------------------------
    # Shift in 10101010
    # -------------------------

    pattern = [1,0,1,0,1,0,1,0]

    all_zif_inputs()

    # CLR high = enabled
    set_output(9, 1)

    # B high permanently
    set_output(2, 1)

    set_output(8, 0)

    for bit in pattern:

        # A input
        set_output(1, bit)

        time.sleep_ms(10)

        # rising edge
        set_output(8, 1)
        time.sleep_ms(10)

        # falling edge
        set_output(8, 0)
        time.sleep_ms(10)

    for q in q_pins:
        set_input(q)

    time.sleep_ms(50)

    got = [read_pin(q) for q in q_pins]

    expected = list(reversed(pattern))

    if got != expected:
        print("SHIFT FAIL expected={} got={}".format(expected, got))
        ok = False

    all_zif_inputs()

    if ok:
        print("74164 PASS")

    return ok

def test_octal_buffer_244():
    ok = True

    # Group 1 enable = pin 1
    # Group 2 enable = pin 19

    # -------------------------
    # Group 1
    # -------------------------

    pairs1 = [
        (2,18),
        (4,16),
        (6,14),
        (8,12),
    ]

    for a_pin, y_pin in pairs1:
        ok &= test_buffer_3state(
            "BUF {}->{}".format(a_pin, y_pin),
            1,
            a_pin,
            y_pin,
            True
        )

    # -------------------------
    # Group 2
    # -------------------------

    pairs2 = [
        (11,9),
        (13,7),
        (15,5),
        (17,3),
    ]

    for a_pin, y_pin in pairs2:
        ok &= test_buffer_3state(
            "BUF {}->{}".format(a_pin, y_pin),
            19,
            a_pin,
            y_pin,
            True
        )

    return ok

def test_bus_transceiver_245():
    ok = True

    # ---------------------------------
    # A -> B direction
    # DIR=1, OE=0
    # ---------------------------------

    pairs = [
        (2,18),
        (3,17),
        (4,16),
        (5,15),
        (6,14),
        (7,13),
        (8,12),
        (9,11),
    ]

    for a_pin, b_pin in pairs:

        for val in [0,1]:

            all_zif_inputs()

            # OE low = enabled
            set_output(19, 0)

            # DIR high = A -> B
            set_output(1, 1)

            set_output(a_pin, val)
            set_input(b_pin)

            time.sleep_ms(50)

            got = read_pin(b_pin)

            if got != val:
                print("A->B FAIL {}->{} val={} got={}".format(
                    a_pin, b_pin, val, got
                ))
                ok = False

    # ---------------------------------
    # B -> A direction
    # DIR=0, OE=0
    # ---------------------------------

    for a_pin, b_pin in pairs:

        for val in [0,1]:

            all_zif_inputs()

            set_output(19, 0)

            # DIR low = B -> A
            set_output(1, 0)

            set_output(b_pin, val)
            set_input(a_pin)

            time.sleep_ms(50)

            got = read_pin(a_pin)

            if got != val:
                print("B->A FAIL {}->{} val={} got={}".format(
                    b_pin, a_pin, val, got
                ))
                ok = False

    # ---------------------------------
    # Hi-Z test
    # ---------------------------------

    all_zif_inputs()

    # OE high = disabled
    set_output(19, 1)
    set_output(1, 1)

    set_output(2, 1)

    set_input_pulldown(18)

    time.sleep_ms(50)

    if read_pin(18) != 0:
        print("Hi-Z FAIL")
        ok = False

    all_zif_inputs()

    if ok:
        print("74245 PASS")

    return ok
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

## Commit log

2026-06-26 Update Main Board B.O.M.txt
2026-06-26 Update Top Board B.O.M Rev-B.txt
2026-06-27 Create UI connector revb.md
2026-06-27 Create enclosure
2026-06-29 Add design details for 3D case
2026-06-29 Fix typo in 3D case readme
2026-06-29 Update readme with printing details
    Added information about the printing material and file formats.
2026-06-29 Correct typo in 3D case readme
2026-06-29 Update title to 'RevB 3D case' in readme
2026-06-29 Update status and notes for 74LVC245 IC
    Updated the status of 74LVC245 to 'Verified at 3.3V' and added note about sensitivity to poor socket contact.
2026-06-29 Update LVC device testing notes in supported-ics.md
    Added notes about LVC device sensitivity to socket contact and tarnished legs.
2026-06-29 Update LVC Device Testing section in supported-ics.md
    Added notes on testing requirements and considerations for LVC devices.
2026-06-29 Fix formatting in LVC Device Testing section
2026-07-07 Create Pico 74xx Rev-B Bringup
2026-07-09 Add Rev-B Power Bring-Up documentation
    Documented the power bring-up issues and component error for Rev-B.
2026-08-04 Release V1.0.0
    [OD-PT74-B_Adhesive.gbr, OD-PT74-B_Cu.gbr, OD-PT74-B_Mask.gbr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]
2026-08-04 add case label files
2026-09-28 Update README for Raspberry Pi Pico 2 changes
2026-09-28 Clarify model to Raspberry Pi Pico 2
    Updated the description to specify Raspberry Pi Pico 2.
2026-09-28 Update Raspberry Pi Pico to Pico 2 in guide
2026-09-28 Update firmware guide for Raspberry Pi Pico 2
    Updated references from Raspberry Pi Pico to Raspberry Pi Pico 2 throughout the guide.
2026-09-28 Update USB port reference for Raspberry Pi Pico 2

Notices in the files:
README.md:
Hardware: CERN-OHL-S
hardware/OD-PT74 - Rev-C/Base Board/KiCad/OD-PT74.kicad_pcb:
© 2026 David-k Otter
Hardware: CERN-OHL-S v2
